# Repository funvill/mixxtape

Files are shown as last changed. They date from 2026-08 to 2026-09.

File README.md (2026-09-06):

# Mixxtape — a cassette you can actually record on

A 2-layer PCB in the form factor of a compact cassette (99.5 × 63.5 mm)
that slides into a real Norelco cassette case. The bare board **is** the object —
no enclosure, no bezel.

An onboard MEMS microphone records three 4-minute tracks. Hold REC to record,
release to stop. Pair it to any Bluetooth earbuds or speaker and press PLAY.

Cassette-shaped Bluetooth *players* exist. Nobody ships a cassette-shaped
**recorder** — and recording is the part that made a mixtape a mixtape.

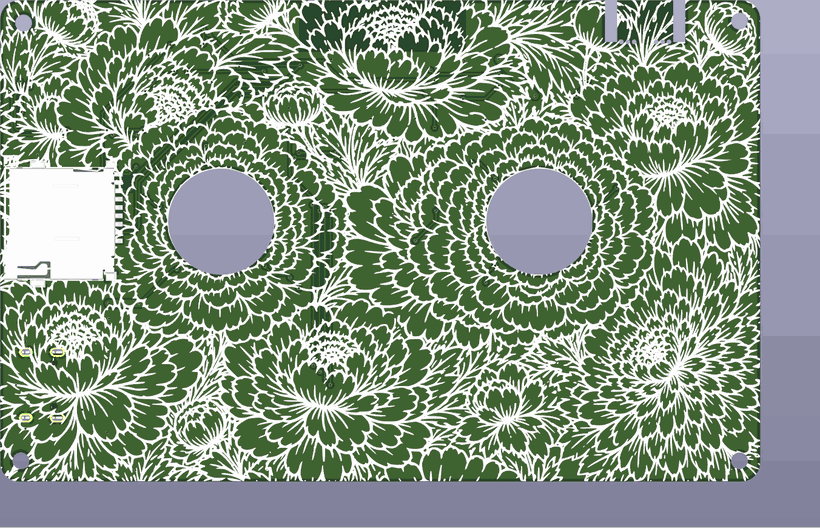
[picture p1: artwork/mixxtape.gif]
The Mixxtape board turning, front and back. The front carries the ESP32, two rings of RGB LEDs around the routed-out reel windows, four buttons and a USB-C port; the back is covered edge to edge in a peony line-art silkscreen.


<sub>3D render from KiCad. The mask reads green here because that is the
viewer's default — the board ships **matte white**, which is what makes the
sharpie label work.</sub>

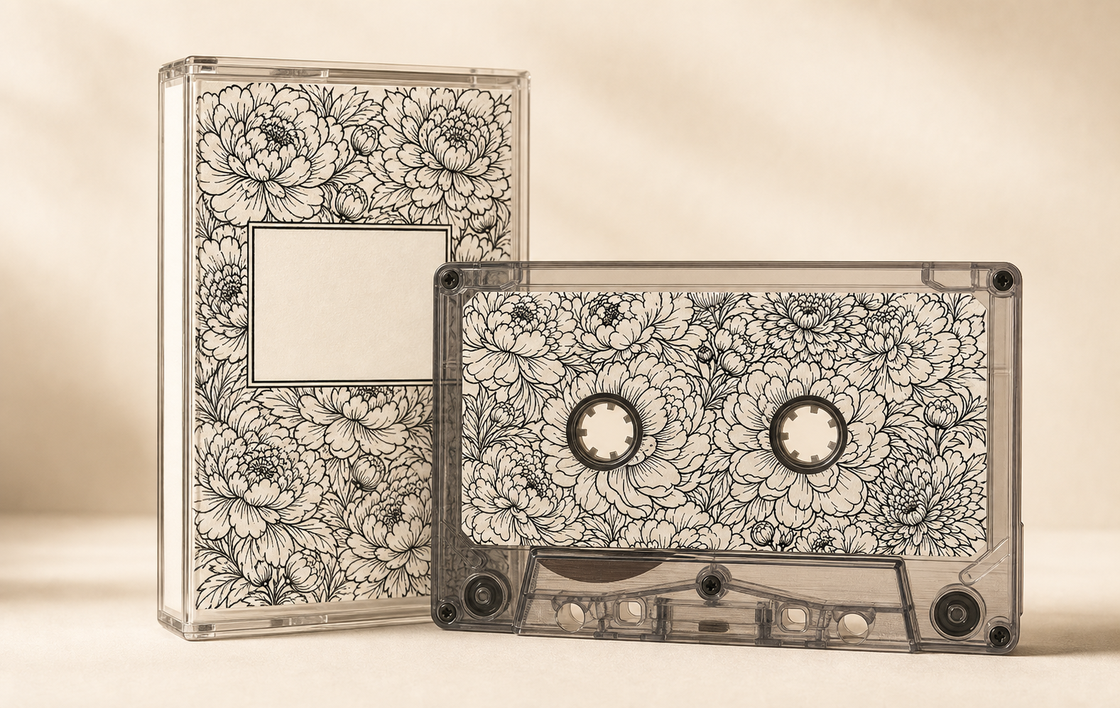
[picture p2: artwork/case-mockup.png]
A cassette and its paper insert, both carrying the same black peony line-art on an off-white ground, the insert showing a blank ruled label box.


<sub>Artwork mockup of the B-side design and the J-card insert. The board is
the object; this shows where the artwork is going.</sub>

## How you use it

- **Hold REC** — records. Release stops. Recording always overwrites the current
  track from zero — recording *is* erasing, same as tape.
- **PLAY** — plays all three tracks in order. It's a tape side, not three voice
  memos.
- **TRACK** — cycles track 1 → 2 → 3.
- **MODE (hold 2 s)** — pairing. Hold the board against your speaker; it picks
  the closest device by signal strength. No phone, no app, no list.
- Plug it in and it auto-reconnects to the last thing it paired with.

## Notable design features

- **Snap-off write-protect tab.** A mouse-bitten break-off PCB tab carries a
  trace to a GPIO. Snap it and the firmware refuses to record — permanently.
  Handing someone a tape becomes a ritual with a physical, irreversible step.
- **The reels show tape position.** Twelve RGB LEDs ring each routed-out reel
  window. During playback the left ring empties and the right ring fills, like
  tape transferring between reels. Red pulse tracks recording level.
- **Matte white solder mask** so you can sharpie the label on, with a ruled
  label block silkscreened where a cassette's paper label sits.
- **No battery.** USB-C only, and there is no charging circuit on the board
  at all. A cassette's promise is that you find it years later and it still
  works.
- **Jig-programmed.** No USB-UART on the board — USB-C is power only.
  Firmware loads through six pogo-pin pads via a programming jig.

## Hardware summary

Every fitted part is stocked at JLCPCB. The project rule is a minimum of 5,000
in stock, so a run never stalls on one line item — with a single documented
exception: **the microphone sits at ~3,500**, because no digital MEMS
microphone at JLCPCB clears the bar, and the one that does is analogue and
would wreck the audio path.

| Block | Part | JLCPCB | Qty | Notes |
|---|---|---|---|---|
| MCU | ESP32-WROOM-32E-N4 | [C701341](https://jlcpcb.com/partdetail/C701341) | 1 | The original Xtensa ESP32 — the only one with Classic Bluetooth, so the only one that can be an A2DP *source* |
| Microphone | MSM261DHT006 | [C51928215](https://jlcpcb.com/partdetail/C51928215) | 1 | **PDM** digital MEMS, mono, **top-ported** — sound enters from the component side, so there is no hole through the board |
| Storage | GD25Q128ESIG | [C2758105](https://jlcpcb.com/partdetail/C2758105) | 1 | 16 MB NOR flash, separate from the module's own flash. Three fixed slots, ~4 min each. Winbond W25Q128JVSIQ ([C97521](https://jlcpcb.com/partdetail/C97521)) is a drop-in second source |
| Indicators | XL-2020RGBC-2812B | [C5349954](https://jlcpcb.com/partdetail/C5349954) | 29 | WS2812-compatible RGB. Two 12-LED reel rings, three track lamps, REC, BT |
| LED data buffer | SN74AHCT1G125 | [C7484](https://jlcpcb.com/partdetail/C7484) | 1 | Lifts the ESP32's 3.3 V data line to the LEDs' 5 V rail |
| Regulator | AMS1117-3.3 | [C6186](https://jlcpcb.com/partdetail/C6186) | 1 | 5 V USB down to 3.3 V |
| USB-C | TYPE-C-31-M-12 | [C165948](https://jlcpcb.com/partdetail/C165948) | 1 | Power and CC sensing only — no data lines |
| Buttons | TS-1187A-B-A-B | [C318884](https://jlcpcb.com/partdetail/C318884) | 4 | REC, PLAY, TRACK, MODE |
| Write-protect tab | — | — | 1 | Not a part. A mouse-bitten PCB tongue carrying a net tie; snap it and recording is disabled for good |
| Programming pads | — | — | 1 | Six bare pogo targets. No USB-UART on the board |

Passives are all JLCPCB basic-library parts:
[10 µF 0805](https://jlcpcb.com/partdetail/C15850) ×2 (rail bulk),
[10 µF 0402](https://jlcpcb.com/partdetail/C15525),
[1 µF](https://jlcpcb.com/partdetail/C52923) (the ESP32's EN delay),
[100 nF](https://jlcpcb.com/partdetail/C1525) ×12,
[10 k](https://jlcpcb.com/partdetail/C25804) ×7,
[5.1 k](https://jlcpcb.com/partdetail/C25905) ×2 (the USB-C CC pull-downs) and
[100 Ω](https://jlcpcb.com/partdetail/C25076) (microphone supply isolation).

| | |
|---|---|
| Audio | 44.1 kHz mono, ADPCM-encoded at record time; playback decodes with table lookups and hands PCM to the Bluetooth stack |
| Power | USB-C only, power and CC sense. No battery, no charger |
| Board | 2-layer, 99.50 × 63.50 mm, matte white solder mask with black silkscreen |
| Cost | **$9.41/board** at a run of 20 — $173.14 in parts plus $15.00 of setup fees for five extended-library parts |

Full detail, with live stock and pricing, is in the
[generated BOM](docs/cassette-recorder-bom-v4.md) — it is derived from the
schematic, so it cannot drift out of step with it.

## Project status

**Design locked, schematic and firmware core underway.** `hardware/` holds a
KiCad 9 project with a first-pass schematic (ERC-clean) and JLCPCB part
libraries. `firmware/` has the ESP-IDF skeleton plus the host-tested core —
crash-safe slot manager, ADPCM codec, playback sequencer, reel display,
pairing policy, bond table and record limiter — all proven without hardware,
since there is no devkit. Target: a prototype run of 3–5 boards, then a full
run of 20. What is left needs a board in hand: the SPI flash, I²S capture,
the A2DP plumbing, LED output, and A2DP against real earbuds.

## Documentation

**Before ordering boards:**

- [Pre-production checklist](docs/PRE-PRODUCTION-CHECKLIST.md) — the
  case-fit test, open decisions, and what to re-quote
- [Case-fit test sheet](docs/case-fit-test-1to1.pdf) — print at 100%, cut
  out, put in a real cassette case

**For people using one:**

- [Cassette insert template](docs/jcard-template-1to1.pdf) — double-sided
  J-card for the case, 1:1, print at 100% ([side 1](docs/jcard-template-side1.svg), [side 2](docs/jcard-template-side2.svg))
- [Documentation index](docs/README.md) — everything below, organised
- [Quick-start pictograms](docs/quick-start-pictograms.html) — wordless
  instructions, one printable sheet
- [Manual](docs/MANUAL.md) — how to record, play, pair, and what the lights mean
- [FAQ](docs/FAQ.md) — including the honest limitations

**For people building or hacking one:**

- [Project write-up](docs/cassette-project-writeup.md) — the pitch, design
  rationale, and open questions
- [Agent handoff brief](docs/cassette-recorder-agent-brief.md) — the
  authoritative spec: locked decisions, GPIO map, behaviour spec, phase order
- [Bill of materials](docs/cassette-recorder-bom-v4.md) — generated from the
  schematic with live JLCPCB prices and stock, so it cannot drift
- [Line-out option](docs/line-out-option.md) — rejected; kept for the reasoning
  and the verified part numbers
- [Prior art](docs/prior-art.md) — research on cassette-form-factor projects
- [Firmware plan](docs/firmware-plan.md) — architecture, milestones, and
  hardware interface for the firmware agent

## Prior art

- **Mixtape Alpha** (Open Music Labs with Jie Qi / MIT Media Lab, 2012) — a
  cassette-shaped ATmega328p synth; the bare-PCB-as-object philosophy comes
  straight from it.
- **Mixxtape** (Mixxim) — the commercial cassette-shaped Bluetooth *player*.
  The thing this project is not.

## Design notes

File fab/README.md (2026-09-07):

# Fabrication export — JLCPCB

Generated from `hardware/mixxtape.kicad_pcb`. Rebuild with:

```
python hardware/scripts/export_fab.py
```

It refuses to run on a board that is not DRC clean, and it cross-checks the BOM
against the placement file — a designator in one and not the other stops the
export.

**Board state:** DRC 0 errors, 0 unconnected · ERC 0 violations · board and
schematic agree on every pad.

## What to upload

| File | Where it goes |
|---|---|
| `jlcpcb/mixxtape-gerbers.zip` | the main upload box |
| `jlcpcb/mixxtape-bom.csv` | BOM, once assembly is switched on |
| `jlcpcb/mixxtape-cpl.csv` | CPL / pick-and-place |

## Order settings

| | |
|---|---|
| Layers | 2 |
| Dimensions | **99.50 × 63.50 mm** |
| Thickness | 1.6 mm |
| **Solder mask** | **Matte white** — adds about two days, and the silkscreen is then black as a fixed pairing, not a choice |
| Silkscreen | Black (follows from white mask) |
| Surface finish | HASL is fine; ENIG if you want the break-off tab's link to stay bright |
| Assembly | Top side only |
| Parts | 66 placements across 15 BOM lines |

## Reference renders

`artwork/renders/` holds 3D renders of both sides, to compare against
JLCPCB's placement previewer before paying:

| | |
|---|---|
| `board-top-white.png`, `board-bottom-white.png` | Rendered with the stackup actually ordered — matte white mask, black silkscreen |
| `board-top.png`, `board-bottom.png` | KiCad's default green, which shows the copper more clearly |

The board file itself carries **no stackup block**, so KiCad renders it green.
The white pair was produced from a throwaway copy carrying the ordered
stackup; stackup colours do not affect the Gerbers either way. Regenerate
with:

```
kicad-cli pcb render --output out.png --side top --quality high hardware/mixxtape.kicad_pcb
```

## Things worth checking in their previewer

**Rotations.** Twenty parts sit at angles that are not multiples of 90° — the
two twelve-LED reel rings, plus four capacitors tucked between them. That is
deliberate, not an export fault. JLCPCB handles arbitrary angles, but their
part library sometimes defines a different zero-rotation than KiCad does,
particularly for LEDs and connectors. **Step through the placement previewer
before paying**, especially D1–D29 and J1.

**One part is deliberately not fitted.** J4, the microSD socket, is marked DNP
and is absent from both the BOM and the CPL — the microSD is a footprint-only
option. **If the previewer shows a microSD socket, stop.**

R9 *is* fitted. It is the pull-up that keeps the SD chip-select pin defined
even with the socket unpopulated.

## What is in the zip

Nine Gerber layers, two Excellon drill files (PTH and NPTH separately) and the
`.gbrjob` file, which helps their parser map the layers.

Drill map Gerbers are generated into `jlcpcb/gerbers/` but deliberately left
**out** of the zip — they are documentation, and a stray `.gbr` can be mistaken
for a copper layer by an auto-detector. Send them only if DFM asks.

## Export settings used

Per JLCPCB's own KiCad guide:

- Layers: F.Cu, B.Cu, F.Paste, B.Paste, F.SilkS, B.SilkS, F.Mask, B.Mask, Edge.Cuts
- Protel filename extensions (their recommendation)
- Subtract soldermask from silkscreen
- Zone fills checked before plotting
- X2 format **off**, for the widest CAM compatibility
- Drill: Excellon, millimetres, decimal, absolute origin, alternate oval mode,
  PTH and NPTH in separate files

The Gerbers and the CPL both use the absolute origin, so they align.

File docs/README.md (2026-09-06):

# Documentation

Start with the root [README](../README.md) for what the object is. This folder
holds the working documents behind it.

## Read first

| | |
|---|---|
| [Agent handoff brief](cassette-recorder-agent-brief.md) | The authoritative spec — locked decisions and the reasoning behind them, the GPIO map, the behaviour spec, and the phase order. Read in full before design, firmware or BOM work. |
| [Pre-production checklist](PRE-PRODUCTION-CHECKLIST.md) | Everything that must be true before boards are ordered. The case-fit test comes first, because the outline and hole positions have never touched real plastic. |

## For users

| | |
|---|---|
| [Manual](MANUAL.md) | How to record, play, pair, and what the lights mean. |
| [Quick-start pictograms](quick-start-pictograms.html) | Wordless, IKEA-style instructions for pairing, playing, recording and changing track. Drawn to the board's real proportions. Prints on one sheet. |
| [FAQ](FAQ.md) | Including the honest limitations. |

## Build and manufacture

| | |
|---|---|
| [Bill of materials](cassette-recorder-bom-v4.md) | **Generated** from the schematic with live JLCPCB stock and pricing. Rebuild with `python hardware/scripts/gen_bom.py`; never edit by hand. |
| [BOM as CSV](cassette-recorder-bom-v4.csv) | JLCPCB assembly format, fitted parts only. |
| [Case-fit test sheet](case-fit-test-1to1.pdf) | Print at 100 %, cut it out, put it in a case. |

## Artwork and packaging

| | |
|---|---|
| [B-side silkscreen template](../hardware/mixxtape-back-silkscreen-template.svg) | 1:1 outline of the back face with the keepouts marked, for anyone reworking the artwork. Rebuild with `gen_silk_template.py`. The art itself — the peony — is final and lives in the board file. |
| [Cassette insert template](jcard-template-1to1.pdf) | Double-sided J-card for the case, 1:1, two pages for duplex printing. Editable sides: [1](jcard-template-side1.svg), [2](jcard-template-side2.svg). Rebuild with `gen_jcard_template.py`. |

## Design record

| | |
|---|---|
| [Firmware plan](firmware-plan.md) | Architecture, milestones, and what is deliberately out of scope. |
| [Storage budget](storage-budget.md) | Why the tape stores ADPCM rather than SBC, and how the numbers work out. |
| [Line-out option](line-out-option.md) | **Rejected.** Kept as a decision record: what a 3.5 mm jack would have cost, with verified parts and pricing, should it ever come back. |
| [Prior art](prior-art.md) | Cassette-form-factor projects, and what nobody has shipped. |
| [Project write-up](cassette-project-writeup.md) | The pitch and the design reasoning, long form. |

## Generated files

Several documents here are produced by scripts in `hardware/scripts/` and will
be overwritten. Edit the generator, not the output:

| Output | Generator |
|---|---|
| `cassette-recorder-bom-v4.md` / `.csv` | `gen_bom.py` |
| `jcard-template-side{1,2}.svg`, `jcard-template-1to1.pdf` | `gen_jcard_template.py` |
| `../hardware/mixxtape-back-silkscreen-template.svg` | `gen_silk_template.py` |
| `../hardware/mixxtape-mechanical.kicad_pcb` | `gen_layout.py` |

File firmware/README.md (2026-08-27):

# Mixxtape firmware

ESP-IDF firmware for the cassette recorder. Read
[`docs/firmware-plan.md`](../docs/firmware-plan.md) first — it holds the
architecture, the hardware interface, and the milestone order. Storage
arithmetic lives in [`docs/storage-budget.md`](../docs/storage-budget.md).

**Framework is ESP-IDF and that is [LOCKED]** — Classic Bluetooth / A2DP
source exists only in Bluedroid. See the firmware plan for why Zephyr was
rejected.

## Layout

```
components/tape/   slot manager, ADPCM codec, tape-side player (portable C)
components/ui/     button grammar + device state machine     (portable C)
components/leds/   reel display rendering                    (portable C)
components/factory/ factory-test harness                     (portable C)
components/btaudio/ pairing, bonds, A2DP source                (mixed)
                   NB: must NOT be called `bt` — that is ESP-IDF's own
                   component name, and ours would shadow it
components/audio/  record-path look-ahead limiter            (portable C)
main/              ESP32 entry point and pin map
test/host/         host unit tests + NOR flash mock
```

Everything with real logic in it is portable C behind `flash_hal.h`, so it
compiles and is tested on a PC. There is no devkit for this project, so the
target-specific layer is kept as thin as possible and the logic that can
be proven without hardware is proven without hardware.

## Host tests

No ESP-IDF needed — any C compiler and CMake:

```bash
cmake -S firmware/test/host -B build && cmake --build build && ctest --test-dir build --output-on-failure
```

The centrepiece is the **power-yank sweep** in `test_tape_store.c`. The mock
flash models a NOR part honestly (erase sets bits, program only clears them,
torn writes land half the data) and can tear any chosen operation. The sweep
tears *every* flash operation of a recording in turn, "re-plugs" the device,
and re-checks the invariants:

- no slot is left mid-recording
- an untouched take is byte-identical
- the interrupted slot is either a whole-frame prefix of the new take, or
  the previous take complete and intact — never stale audio spliced on
- nothing is ever programmed over non-erased flash
- the device still records afterwards

This matters because there is no battery: a yanked USB cable is the normal
way this device powers off.

## Factory test (M5)

Twenty boards get assembled by hand, so each one is probed on the jig
before production firmware goes on:

```bash
idf.py -C firmware -DMIXXTAPE_FACTORY_TEST=ON build flash monitor
```

It probes every subsystem, prints an operator table, and emits one
greppable line:

```
FT|1|flash_id=PASS:0xEF4018|mic=PASS:1832|tab=PASS:1|bt=PASS:3|VERDICT=PASS
```

Log the jig's serial output to a file and that file is the build record for
the run — when board 14 turns out flaky three months later, you can look it
up instead of guessing.

Two properties matter and are enforced by tests:

- **Every step runs, even after one fails.** A board with a dead mic *and*
  a dead flash reports both faults on one pass, not one fault per reflash.
- **Results carry measured values, not just verdicts.** `mic=PASS:1832`
  lets you spot the one board reading 40 before it ships.

Interactive steps (LED walk, button presses) are skipped automatically on
an unattended run rather than blocking the line.

**Probes are not implemented yet.** The harness is host-tested; the probes
that need drivers M4 has still to write report `SKIP` with a `TODO M4`
detail, and the runner prints `SUITE INCOMPLETE` rather than a pass banner
while any remain. `main/factory_main.c` is the bring-up checklist.

## Target build

Needs ESP-IDF v5.x:

```bash
idf.py -C firmware build
```

Flashing is via the **J5 pogo pads and a jig** — there is no USB-UART on the
board (USB-C is power only). The jig carries the bridge and the EN/IO0
auto-program transistors.

## State

M0-M3 of the plan are done: project skeleton, storage budget resolved,
the host-tested core, and the reference study that settled the stored
format (ADPCM, not SBC — ESP-IDF's A2DP source takes PCM only). Playback
sequencing and the reel display are written and tested too.

Pairing *policy* and the bond table are written and tested too — what is
missing there is only the Bluedroid plumbing that feeds them.

Not yet written, all gated on prototype boards (M4): the SPI flash HAL,
PDM capture, the A2DP source and discovery callbacks, WS2812 output via
RMT, and CC sensing. Every one of those is a driver — the logic they feed
is already written and tested.

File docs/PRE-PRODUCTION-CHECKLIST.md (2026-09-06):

# Before you order boards

Nothing here is optional, and most of it is cheap. The expensive mistakes on
a project like this are all made in the ten minutes before clicking order.

Work top-down: the physical test gates the layout, the layout gates the
prototypes, and the prototypes gate the run of 20.

---

## 0. Blockers from the six-agent review (2026-08-30) ⬜

Six independent reviews ran against this board — schematic/electrical,
PCB/DFM, BOM/footprints, firmware-vs-hardware, bring-up/rework, and analog/RF.
Everything they found that could be fixed deterministically **has been fixed**
(see the CHANGELOG). What is left below needs either a physical object or your
judgement, and **each one can still cost the run.**

### 0a. USB-C plug fit — RESOLVED ✅

**Steven test-fitted a real USB-C plug against a 1:1 print on 2026-09-06 and
it seats.** J1 was not moved and the outline was not notched.

The measurement that prompted this stands and is worth keeping, because it
will be re-discovered: J1's mating face sits at x = 129.613 against a board
edge at 130.380, so **0.767 mm of bare FR4 protrudes in front of the
receptacle mouth**, with no relief notch. A review reasoned that a plug's
overmould shoulder seats flush against the receptacle at full insertion and
would foul that lip. The setback is real; the consequence was inferred from
generic plug geometry, and a real plug says otherwise.

**Still open, separately:** whether the closed cassette shell leaves room in
front of the port. That is a different question from whether the plug seats on
a bare board, and it is tracked under the case-fit items below.

### 0b. Mounting holes — RESOLVED ✅

**Steven measured them against the real shell on 2026-09-06 and they are
correct as drawn.** No change needed.

| | Position | Board-relative |
|---|---|---|
| 1 | 33.580, 32.750 | 2.750, 60.750 |
| 2 | 33.580, 90.750 | 2.750, 2.750 |
| 3 | 127.250, 33.000 | 96.420, 60.500 |
| 4 | 127.600, 90.750 | 96.770, 2.750 |

For the record, because it will look like a defect to the next person who
measures it: the four holes are **not** a rectangle. The bottom row spans
94.020 mm against the top row's 93.670 — 0.350 mm of skew — and the left
column's pitch is 58.000 against the right's 57.750, another 0.250 mm. A
review flagged this on the reasonable assumption that a moulded shell has
square bosses. It does not, and the holes follow the plastic. **Leave them
alone.**

### 0c. Step through D1–D29 in JLCPCB's previewer ⬜

**The LED part changed on 2026-08-30** — see the CHANGELOG. The old footprint
was drawn for a different manufacturer's pad-1 corner and would have
reverse-powered all 29. The new part (C5349954) has been verified against
LCSC's own library data and the netlist is correct, but:

- 20 parts sit at rotations that are not multiples of 90°, 16 of them LEDs.
- **JLCPCB's library sometimes defines a different zero-rotation than KiCad.**
- The previewer renders a *package*, not a netlist. **It cannot catch a pin-1
  error** — a wrong-corner part looks perfect in the render.

So the previewer is necessary and not sufficient. Look at it anyway, and give
D1–D29 and J1 their own minute.

### 0d. Microphone port direction — RESOLVED ✅

**MSM261DHT006 (C51928215) is TOP-PORTED.** Confirmed 2026-08-30 from LCSC's
own product page, which states: *"The MSM261DHT006 is an omnidirectional,
top-port MEMS microphone with PDM digital output."*
[C51928215](https://www.lcsc.com/product-detail/C51928215.html) ·
[datasheet](https://www.lcsc.com/datasheet/C51928215.pdf)

So the board is correct as drawn: **no through-hole under U2**, and the top
face is the acoustic path. This was flagged because `gen_layout.py` argues the
case using the name of the part it *replaced* (MSM261S4030H0R), and two
reviewers could not close it from the repo. It is closed now.

**What still applies:** keep U2's top face clear. Nothing tall beside it — the
only neighbours within 14 mm are C7 at 2.70 mm and R12 at 3.79 mm, both 0402,
so that is fine. But check during the case-fit test that no shell rib lands
over it, and remember a written label on the B-side artwork must not cover it.

### 0e. Decide on the protective components that were NOT added ⬜

These need schematic changes plus placement and routing. They were identified
but deliberately not applied unattended, because each adds a part and a net:

| Add | Where | Why |
|---|---|---|
| 10 k to 3V3 | `BTN_REC` (GPIO0) | Only the ESP32's internal ~45 k holds the boot strap. `BTN_REC` is **94.8 mm** — the longest signal net on the board — runs 16 mm alongside SPI_CLK, and lands on a bare pogo pad people touch. Leakage or noise at reset drops the board into download mode: dark, unresponsive, looks dead. |
| 10 k to GND | `LED_DATA` | GPIO27 is high-Z from reset, so U8's AHCT input floats near threshold, drawing crowbar current and possibly latching 29 LEDs to random colours at power-on. |
| 330 R series | U1.12 → U8.2 | J5 supplies **3V3, not VBUS**, so on jig power U8's VCC is 0 V. Driving GPIO27 high then forward-biases U8's input clamp into a dead rail, on **every flash cycle**. |
| 330 R series | U8.4 → D1 DIN | Damps the first hop of the chain. |
| 22 µF | U4 output, ≤2 mm | The AMS1117 datasheet asks for it and `cassette-recorder-agent-brief.md:103` says so; it never reached the schematic. Effective output C is realistically 5–6 µF. |
| 100 nF | U1 EN pin, ≤2 mm | The EN de-glitch RC (R3/C9) is **52 mm of routed trace** from the pin, alongside SPI_MOSI. |
| 1 k series | `TAB_SENSE` at U1 | The user snaps this tab **with their fingers** — a guaranteed human contact event on exposed copper wired straight to a GPIO with no clamp. |

Also consider **inverting the TAB1 divider** (3V3–R7–TAB_SENSE–TAB1–GND). As
built, GPIO21 is tied to 3V3 through a zero-ohm net tie; one firmware line
configuring it as output-low shorts the rail through the ESP32's driver.

### 0f. Fill in the factory-test probes ⬜

**With no prototype, the factory test is your only instrument** — and five of
its eight probes are stubs returning SKIP, so it can never report PASS. The
three unimplemented ones that matter most are exactly what you cannot check by
eye: **the microphone works, the radio transmits, and the flash accepts a
write.**

None of these need a board change:

- **`mic` — make it acoustic.** RMS of room noise cannot tell a working mic
  from a clock picking up crosstalk. Put a cheap piezo on the jig at a fixed
  distance, play a fixed tone, run a Goertzel at that frequency, and report the
  bin magnitude *and* its ratio to two neighbours.
- **`bt` — report RSSI, not a device count.** An inquiry count is
  environment-dependent: a quiet bench gives 0 and fails a good board. Pin one
  discoverable device at a fixed distance. An antenna or shield-solder defect
  shows as a 15 dB shift a pass/fail count would never see.
- **`flash_rw`** — pattern-write the spare region, read back, report CRC and
  throughput in KB/s. The JEDEC read barely exercises MISO.
- **`cc`** is nearly free: `cc_sense.c` already exists and works, it just is not
  wired into `probe_cc`.
- Add `esp_reset_reason()`, and **prefix the log line with the MAC** —
  `factory_test.h` calls the log "the build record for the run" and there is
  currently no way to tell board 14 from board 3.

**Also add a boot-time LED flash to `app_main`.** Today it never calls
`ws2812_init`, so a working board and a dead board are visually identical: 29
dark LEDs and UART on the jig pads. One line of "the CPU is running and the
RMT/level-shifter/LED-chain path works" is worth more during a 20-board
bring-up than any amount of UART.

Beware: **the `buttons` probe can pass spuriously.** REC is GPIO0, which the
jig's auto-reset also drives. The jig must tri-state IO0 before that step, and
the probe should verify IO0 reads high first.

### 0g. Build five, not twenty ⬜

Order 20 bare PCBs, **assemble 5**. Against the failure modes that remain
unrecoverable on this board — the USB-C fit, the mic port direction, the
mounting-hole skew — a pilot costs roughly one extra setup fee (~$20–30) and
one lead time, against ~$280 of scrapped assemblies.

Note **JLC will not assemble boards you already hold**, so a second run means
paying for boards again. Do not plan to hand-solder the microphone later: it is
a bottom-terminated LGA and hand-placing it is *harder* than letting JLC reflow
it.

### 0h. Accepted residuals — known, quantified, not fixed ⬜

These were judged not worth the risk of an unattended change. Decide whether
you agree.

- **Antenna clearance is 8.5 mm, not the 15 mm Espressif recommend.** Improved
  from 1.85 mm. Reaching 15 mm means rerouting 3V3/TAB_SENSE and EN/SPI_MOSI,
  or notching the outline so the antenna overhangs — which would invalidate
  the case fit you just verified against real plastic.
- **The write-protect tab is ~51 % solid FR4** across its 7.4 mm break line.
  It is now genuinely drilled (it was milled, at a size JLC could not cut), and
  the pitch was widened to 1.05 mm so the 0.45 mm hole-to-hole floor is met -
  but widening the pitch adds web as fast as it adds gap, so the solid fraction
  did not improve. The central unperforated span went from 2.30 mm to 1.60 mm.
  **It will need pliers or a score-and-snap, not a thumb.**
  The limit is geometric: 3V3 crosses at x = 45.150 and TAB_SENSE at 45.550,
  forcing a hole-free zone through the middle, and with a mandatory 0.45 mm
  between holes there is no arrangement that gets below ~45 %. Making it
  properly snappable means rerouting those two traces to cross at the edge of
  the tab rather than its centre. That is a real routing change and was not
  attempted unattended.
- **PDM_DATA runs 0.61 mm from SPI_CLK** for 4.8 mm on B.Cu, and the flash is
  written while the mic is recording. Expect flash-write-correlated clicks in
  recordings. Moving U2 next to U1 would fix this and the 67 mm PDM route at
  once — a placement change too large to make unattended.
- **U4 is at ~67 mm² of attached copper**, up from 29. Fine at a realistic
  150–250 mA load; marginal at a sustained 500 mA.
- ~~J1's CC pad mapping is unverified.~~ **RESOLVED 2026-08-30.** Read in
  physical order along the signal row, J1's pads come out as `B1A12, B4A9, B5,
  A8, B6, A7, A6, B7, A5, B8, A4B9, A1B12` — exactly the USB Type-C standard
  12-pin sequence, reversed by the connector's 90° rotation. **B5 lands on CC2
  and A5 on CC1**, both in their standard positions, each with its own 5.1 k
  pull-down (R2, R1). VBUS is on both A4B9 and B4A9, GND on both A1B12 and
  B1A12, and SBU1/SBU2/D+/D− are correctly left open. Cross-checked against
  LCSC's own library data for C165948 (TYPE-C-31-M-12).
- **The board draws more than a default USB port guarantees.** 29 LEDs plus an
  ESP32 TX burst exceeds 500 mA. R10/R11 correctly route CC to GPIO36/39 so
  firmware *can* read the source's advertised current — **it must**, and must
  cap brightness when the source is default-USB.

---

## 1. The case-fit test — mostly done ✅

**Steven ran the 1:1 printout against a real plastic case on 2026-08-30 and
it fits.** That retires the single largest mechanical unknown: the outline
had been borrowed from a board that fits *some* case, and the reel windows,
tab position and mounting holes are ours and had never touched plastic.

One item below is still open, and it is the one that decides whether the fit
generalises or was luck.

⬜ **Buy several cassette cases, from different brands.** The brief is
   emphatic: internal ribs and hub-clamp ridges vary, and thrifted cases are
   not dimensionally consistent. **One case proves the design is not wrong;
   it does not prove it is right.** Still worth doing before a 20-board run,
   because the failure it catches is one that scraps every board at once.

✅ **Print [`case-fit-test-1to1.pdf`](case-fit-test-1to1.pdf) at 100%.**
   Done 2026-08-30. Turn off "fit to page" / "scale to fit" if reprinting —
   printers shrink pages by a few percent without telling you.

✅ **Measure the calibration bar on the printout.** Must read exactly
   50.0 mm. Treated as satisfied by the successful fit — a scaled print
   would not have seated correctly — but measure it explicitly on any
   reprint, because a print scaled by a percent or two can still *feel*
   right in the hand.

✅ **Cut it out and put it in a case.** Done 2026-08-30 — it fits. The
   points that were checked, kept here as the record of what "it fits"
   covered:

   - Does the outline sit in the case without forcing?
   - Do the **reel windows** clear the hub-clamp ridges, or do the ridges
     land on board material where LEDs will be?
   - Does the **write-protect tab** (top-left) clear the internal ribs? The
     mouse-bite nibs must not sit where a rib presses.
   - Do the four **mounting holes** clear the case's internal ribs?
   - Does the **microphone** land somewhere a fingertip, a case rib or
     a written label will not cover? It is top-ported, so its top face
     is the acoustic path — there is no hole through the board.

⬜ **Write the measurements down.** Record them in this file rather than
   re-running `hardware/scripts/gen_layout.py`. **Do not re-run that
   script** — it rebuilds the original 100.33 mm outline and would undo the
   trim to 99.50 mm, along with every placement and route since. It carries
   a warning header saying so. If a measurement forces a mechanical change,
   edit the board directly and re-run `hardware/scripts/export_fab.py`.

---

## 2. Decisions still open ⬜

These are all flagged in the repo but need an actual answer before copper.

✅ **The microphone — decided.** Moved to MSM261DHT006 (C51928215), the
   best-stocked digital MEMS mic at JLC. Acoustically an equal swap; the
   cost was the interface (PDM instead of I²S, firmware updated) and a
   completely different pinout, so the schematic changed rather than just
   the part number. Two things came out of the datasheet review and are
   worth remembering:

   - It is **top-ported**, and so was the part the brief specified. The
     acoustic hole the brief called for through the board was a mistake
     and has been removed. Keep the mic's top face clear instead.
   - **3,485 in stock is below the 5,000 rule** — a documented exception,
     because no digital MEMS mic at JLC clears it and the only one that
     does is analog. Re-check stock before ordering; if it has fallen,
     alternates are MP34DT06JTR (C503097) and ICS-43434 (C5656610).

⬜ **Record path: one pass, not two.** The brief's two-pass pipeline needs a
   scratch region that does not fit. Firmware now encodes ADPCM straight to
   the slot. Consequence: a look-ahead limiter instead of whole-take peak
   normalisation. See `storage-budget.md` §4.

⬜ **Slot size 5 MiB → 5.125 MiB** (82 erase blocks), to keep the full
   four-minute take. A deliberate deviation from the locked "3 × 5 MB
   slots"; it preserves three fixed slots and the 4-minute promise.

⬜ **Licence of the borrowed outline.** Open Music Labs publish the Mixtape
   Alpha board files but state no licence for them. Confirm with them
   before distributing derived artwork. If they decline, redraw the outline
   from a measured cassette.

⬜ **The name.** The repo is named after Mixxim's commercial product. Fix
   before anything goes public.

⬜ **Tab count** — one for the whole tape (recommended, faithful) or three,
   one per track (more useful).

✅ **Silkscreen artwork — done.** The peony on the back face is **final**
   (Steven, 2026-09-06). It lives in the board file as the `LOGO` footprint at
   (80.582, 61.700), 2.16 MB across 193 shapes, deliberately full-bleed with
   ~0.42 mm hanging off each side for the fab to clip. The designer brief that
   used to sit in `docs/` has been retired — there is no outstanding artwork
   commission. The 1:1 template
   ([`mixxtape-back-silkscreen-template.svg`](../hardware/mixxtape-back-silkscreen-template.svg))
   stays for anyone reworking it later.

   Still deferred, and only if you want them: the five decorative guide holes
   along the bottom edge.

---

## 2b. Manufacturability, audited 2026-08-29 ⬜

Checked against JLCPCB's published 2-layer limits. Everything below either
passed or was fixed, but three items want a human eye before the order goes in.

- [ ] **Smallest plated annular ring is 0.200 mm on J1** — above JLCPCB's
  0.18 mm floor but under their 0.25 mm recommendation. Fine in all likelihood;
  worth a glance at the fab's DFM report rather than a surprise.
- [ ] **Closest hole-to-hole is 0.500 mm against a 0.45 mm limit**, inside the
  DNP microSD footprint. Only bites if J4 is ever fitted.
- [ ] **The B-side artwork has 32 shapes thinner than 0.15 mm** and 52 more
  between 0.15 and 0.25 mm. The first group will not print. Get the artwork
  thickened before committing to a run, or accept that the fine detail vanishes.
- [x] Footprint attributes corrected — the microphone was tagged `through_hole`
  with eight SMD pads, which can drop it from the pick-and-place file entirely.
- [x] Silkscreen line widths raised to JLCPCB's 0.15 mm minimum.
- [x] Eleven DRC rules had been set to `ignore`, hiding 145 findings including
  the one that would have caught the microphone. The eight that matter are back
  on as warnings.
- [x] **USB-C needs no board notch.** The TYPE-C-31-M-12 is a top-mount
  right-angle receptacle; its only board penetrations are four plated shell legs
  and two non-plated locating pegs, all already in the footprint. Its mouth sits
  0.76 mm inboard of the board edge, and the strip in front of it is clear of
  copper and parts. A notch is only needed for *mid-mount* receptacles, which
  this is not.
- [ ] **Confirm the case does not block the USB-C.** The port is on the right
  edge; a closed Norelco case has a wall there. Decide whether the board is
  meant to come out of the case to charge, or whether the case gets modified.

---

## 3. Re-quote, don't trust this repo ⬜

⬜ **Re-run `hardware/scripts/gen_bom.py`.** Prices and stock in the BOM are
   a snapshot. NOR flash has already moved once (W25Q128 went from $1.65 to
   $2.26 during this project).

⬜ **Check the supply-chain rule section.** Every fitted part should clear
   5,000 in stock, or be a documented exception.

⬜ **Confirm matte white solder mask** is available and what it costs.

⬜ **Count the extended parts.** At 20 boards the per-part setup fees
   dominate the component cost — adding one new extended part costs about
   as much as 50 LEDs.

---

## 4. Prototypes before the run ⬜

⬜ **Order 3–5 boards first, not 20.** At ~$14 each they are cheaper than a
   devkit, and they are the only way to answer the questions below.

⬜ **Build the programming jig.** There is no USB-UART on the board, so
   nothing can be flashed without it.

⬜ **Fill in the factory-test probes.** `firmware/main/factory_main.c` is
   the checklist; the harness is written and tested, the probes are stubs.
   The runner prints `SUITE INCOMPLETE` until they are real.

⬜ **Answer the three questions that could still change the hardware:**

   - **Handling noise.** A bare board with a mic on it, held in a hand.
     This is the project's biggest technical risk and it cannot be
     answered on paper.
   - **A2DP against real sinks.** Test a basket of them — AirPods, cheap
     TWS earbuds, a Bluetooth speaker. Confirm the class-of-device filter
     and tune the RSSI threshold, which is currently a guess.
   - **Reconnect latency on power-up.** If it is ~8 seconds, the ritual is
     dead and the interaction needs rethinking. Measure it early.

---

## 5. Only then ⬜

⬜ Fix whatever the prototypes taught you.
⬜ Re-quote again.
⬜ Order the 20.

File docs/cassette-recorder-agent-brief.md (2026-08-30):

# Cassette Mixtape Recorder — Agent Handoff Brief

**Owner:** Steven
**Status:** Design locked, pre-layout. No schematic drawn yet.
**Run size:** 20 boards, one-off. Not a production program.

---

## 0. Read this first

Several decisions in this document look wrong at first glance and are not.
Each one is marked **[LOCKED]** with its rationale. Do not "optimize" a locked
decision — if a change looks compelling, raise it with Steven rather than
acting. Section 2 lists the specific wrong turns an agent is most likely to
take.

Everything not marked LOCKED is open, and §7 splits it into what you may
decide yourself versus what needs Steven.

---

## 1. What this is

A 2-layer PCB in the exact form factor of a compact cassette (100.0 × 63.5 mm),
which slides into a real Norelco cassette case. The bare board *is* the object —
no enclosure, no bezel.

An onboard MEMS microphone records three tracks. Hold REC to record, release to
stop. Then pair to any Bluetooth earbuds or speaker and press PLAY.

Reel windows are routed out of the board with 12 RGB LEDs ringing each one. As a
track plays, the left ring empties and the right ring fills, mimicking tape
transferring between reels.

**Design ethos:** this descends from Open Music Labs' Mixtape Alpha (2012, with
Jie Qi / MIT Media Lab High-Low Tech) — bare PCB as a thing you touch, trace
routing as visual design, aesthetics as a first-class constraint. Not a
functional-first board that happens to be cassette-shaped.

**Prior art to read before starting:**
- Mixtape Alpha wiki: `wiki.openmusiclabs.com/wiki/MixtapeAlpha` — Eagle files,
  gerbers, BOM, and a candid "limitations of the design" section. Pull
  `mixtape2.brd` for the cassette outline rather than redrawing it.
- Mixxtape (Mixxim, `paulthings.com`) — the commercial cassette-shaped player.
  Player only, no recording. This is the thing we are *not* building.

---

## 2. Traps — the five mistakes most likely to be made here

1. **Do not substitute a newer ESP32.** The ESP32-S3, C3, C6, C5, and H2 are all
   BLE-only. Classic Bluetooth — and therefore A2DP — exists only on the
   original Xtensa LX6 ESP32. No A2DP means it cannot talk to ordinary earbuds,
   which is the entire product. This is the single most important constraint in
   the document.
2. **Do not switch to an nRF part.** Nordic has never shipped Classic Bluetooth.
   Same failure.
3. **Do not add a Seeed XIAO.** No XIAO in the lineup has Classic Bluetooth. The
   XIAO footprint may still be useful as a *secondary* prototyping footprint, but
   it cannot be the production MCU.
4. **Do not increase flash capacity "for headroom."** NOR flash prices rose
   100–120% in 1H2026, with high-density parts hit hardest. Headroom is the most
   expensive thing on this BOM. Track length was set to 4 minutes specifically to
   fit 16 MB.
5. **Do not add a battery to the default build.** See §3, Power.

---

## 3. Locked decisions

| Decision | Value | Rationale |
|---|---|---|
| **MCU** | ESP32-WROOM-32E, module not bare chip | **[LOCKED]** Classic BT for A2DP source. Module carries FCC/IC/CE modular approval; a bare chip would put full intentional-radiator testing on us. |
| **Flash size** | 16 MB external | **[LOCKED]** 3 × 4 min mono SBC ≈ 11.5 MB. |
| **Separate audio flash** | Yes, not module flash | **[LOCKED]** No battery means no graceful-shutdown window. A yank mid-write must not be able to corrupt the bootloader. Also avoids XIP cache stalls during record. |
| **Audio path** | Mono, encode to **block-framed IMA ADPCM** at record time | **[LOCKED]** Playback must be read-frames-and-transmit. No real-time decode, no resample, no DSP during streaming. |
| **Sample rate** | 44.1 kHz | **[LOCKED]** Matches A2DP negotiation, eliminates resampling entirely. |
| **Power** | USB-C only; no battery or charger on the board | **[LOCKED]** A LiPo in a drawer for years is dead and possibly hazardous. The object's premise is that it still works when rediscovered. Also avoids UN38.3 shipping paperwork. |
| **Controls** | 4 tactile buttons + 1 break-off write-protect tab | **[LOCKED]** Physical buttons, not cap touch — explicitly reversed after consideration. |
| **Indicators** | 29 × WS2812B-2020 RGB, single data line | **[LOCKED]** Replaced charlieplexing. Quiescent draw is irrelevant on USB. |
| **Recording UX** | Hold REC to record; always overwrites current slot from zero | **[LOCKED]** No delete function needed — recording *is* erasing, same as tape. |
| **Playback UX** | PLAY plays all three tracks in order | **[LOCKED]** It's a tape side, not three voice memos. |
| **Reconnect** | Auto-reconnect to last bond on power-up | **[LOCKED]** |
| **Storage layout** | 3 fixed 5 MB slots + header region | **[LOCKED]** No dynamic allocation, no compaction. |
| **Solder mask** | Matte white | **[LOCKED]** Glossy mask rejects permanent marker. Users sharpie the label. |
| **Sides** | One side, three tracks. No accelerometer. | **[LOCKED]** Rejected on BOM cost. |
| **Case** | Thrifted Norelco cassette cases | **[LOCKED]** |

---

## 4. Bill of materials

The authoritative BOM is **generated from the schematic** — see
[`cassette-recorder-bom-v4.md`](cassette-recorder-bom-v4.md), rebuilt with
`hardware/scripts/gen_bom.py`. It carries live JLCPCB stock and pricing and
cannot drift away from the design. Summary:

| Ref | Part | JLCPCB | Note |
|---|---|---|---|
| U1 | ESP32-WROOM-32E-N4 | [C701341](https://jlcpcb.com/partdetail/C701341) | **MSL 3, X-ray required.** N16 is C701343 |
| U2 | MSM261DHT006 | [C51928215](https://jlcpcb.com/partdetail/C51928215) | **PDM** MEMS mic, top-ported. Replaced MSM261S4030H0R (C2840615) at zero stock — completely different pinout, so a schematic change rather than a swap |
| U3 | GD25Q128ESIG | [C2758105](https://jlcpcb.com/partdetail/C2758105) | Second sources: C97521 (Winbond W25Q128JVSIQ), C113767 |
| U4 | AMS1117-3.3 | [C6186](https://jlcpcb.com/partdetail/C6186) | SOT-223. 22 µF on the output for stability, per its datasheet |
| U8 | SN74AHCT1G125 | [C7484](https://jlcpcb.com/partdetail/C7484) | 3.3 V → 5 V buffer for the LED data line |
| D1–D29 | XL-1615RGBC-2812B | [C5349954](https://jlcpcb.com/partdetail/C5349954) | 12 + 12 reel rings, 3 track, REC, BT |
| SW1–4 | TS-1187A-B-A-B | [C318884](https://jlcpcb.com/partdetail/C318884) | |
| J1 | USB-C 16P | [C165948](https://jlcpcb.com/partdetail/C165948) | + 2 × 5.1 kΩ CC pulldowns — mandatory |
| R12 | 100 Ω | [C25076](https://jlcpcb.com/partdetail/C25076) | Microphone supply isolation, per the MSM261DHT006 datasheet |
| C9 | 1 µF | [C29266](https://jlcpcb.com/partdetail/C29266) | The ESP32's EN delay. The datasheet asks for 1 µF, not 100 nF |

**$10.01/board at qty 20** — $182.13 in parts plus $18.00 of setup fees for six
extended-library parts.

**U6 (CH340N) and U7 (USBLC6-2SC6) are gone.** USB-C is power only; programming
is via the six-pad pogo jig, so there is no USB data path to protect.

---

## 5. GPIO map

Avoid GPIO 6–11 (module flash). GPIO 12 is MTDI strapping and must be low at
boot — leave unused. GPIO 34/35/36/39 are input-only.

| Signal | GPIO | Note |
|---|---|---|
| PDM CLK → mic | 25 | **Changed from I²S.** MSM261DHT006 is PDM |
| PDM DATA ← mic | 33 | |
| *(free)* | 26 | Was I²S BCLK; PDM needs only two wires |
| VSPI SCK → flash | 18 | |
| VSPI MISO ← flash | 19 | |
| VSPI MOSI → flash | 23 | |
| VSPI CS → flash | 5 | Strapping, defaults high — OK |
| WS2812 data | 27 | Drive via **RMT peripheral** |
| SW1 REC | 0 | Also BOOT for flashing |
| SW2 PLAY | 4 | |
| SW3 TRACK | 16 | |
| SW4 MODE | 17 | |
| Write-protect tab | 21 | Pull-down; tab intact = high |
| Line-in ADC *(DNP)* | 35 | ADC1 |
| UART0 TX / RX | 1, 3 | To the J5 pogo pads only — there is no USB-UART on the board |

Free for expansion: 13, 14, 22, 32.

---

## 6. Behaviour spec

### Buttons

| Button | Short | Long |
|---|---|---|
| REC | — | **Hold to record.** Release stops. Overwrites current slot. |
| PLAY | Play / pause | Sleep |
| TRACK | Cycle 1 → 2 → 3 | — |
| MODE | — | 2 s pair · 5 s dub · 10 s dev WiFi |

### Write-protect tab

Break-off PCB tab, top edge, mouse-bites, trace from 3V3 to GPIO21 with
pull-down. Intact → high → recording permitted. Snapped → low → **firmware
refuses all recording, permanently.** One tab locks the whole tape.

Route the trace so the snap line crosses it cleanly. Keep mouse-bite nibs clear
of case ribs.

### Pairing

The mixtape is the A2DP **source** — it initiates. Bluetooth sinks have no
source-selection UI and don't need one.

1. User puts speaker/earbuds into their own pairing mode.
2. User holds MODE 2 s. Reels sweep amber.
3. `esp_bt_gap_start_discovery()` → inquiry.
4. Filter results by **Class of Device**: major class Audio/Video, minor class
   headphones or loudspeaker. Drops phones, laptops, keyboards automatically.
5. Filter by **RSSI better than ~−50 dBm** (≈30 cm). This makes proximity the
   selection mechanism — the user holds the board against the speaker. Threshold
   needs empirical tuning.
6. `esp_a2d_source_connect()`, Just Works SSP, bond, stream.

Store 4–8 bonds. On power-up try last-used first, then others.

**Known race:** the sink is often simultaneously trying to reconnect to its own
last source (usually a phone). Handle with retry + backoff, and give honest LED
feedback — slow red pulse after ~15 s of failure means "the speaker is busy."

### LED states

| State | Reels |
|---|---|
| Searching | Amber sweep |
| Connected | Green lock |
| Playing | White — left ring empties, right fills |
| Recording | Red pulse, brightness = VU level |
| Background erase | Slow reverse, dim |
| Dubbing | Violet |

**Clamp global brightness to ~25%.** All 29 at full white is ~1.7 A.

### Record pipeline

Two-pass. Nothing clever happens in real time.

1. REC held → I²S DMA into ring buffer → write **ADPCM** to a scratch region.
2. REC released → device idle → analyze peak, normalize, encode to **SBC**,
   write to the final slot. Reels spin during this, so the wait reads as
   rewinding rather than hanging.
3. Slot invalidation triggers **background pre-erase** at idle. Sector erase is
   ~40 ms and must never happen on the record critical path; recording issues
   page programs only (~0.7 ms).

### Playback

Read SBC frames from flash → `esp_a2d_source_audio_data_send()`. That is the
entire playback path. If you find yourself decoding or resampling during
playback, something upstream went wrong.

---

## 7. Open questions

### Agent may decide

- LDO part selection (1 A, 5 V in, 3.3 V out, SOT-23-5 or SOT-89)
- WS2812B-2020 specific LCSC part and second source
- Exact reel ring diameter and LED pitch
- Decoupling strategy for the LED chain (~1 cap per 4 LEDs)
- Hacker header pinout refinement — currently 3V3, GND, I²S ×3, UART ×2, EN,
  spare GPIO ×2
- Firmware task structure and RTOS priorities
- ADPCM variant

### Needs Steven

- **Tab count:** one for the whole tape (recommended, faithful) vs three
  (per-track, more useful)
- **N4 vs N16** once the live price delta is known — if under ~$0.40, take N16
- **Silkscreen artwork.** On a bare-PCB product the art *is* the industrial
  design. Nobody should generate this without him.
- **Project name**
- **Line-in DNP:** confirm the 3.5 mm jack footprint choice
- **Tape-head playback in a real deck** — deliberately deferred. Mixxim holds a
  patent covering a cassette-shaped player that plays in real decks. Do not
  design toward this without a legal read.

### Must verify before ordering

- [ ] ESP32-WROOM-32E-N4 live price vs N16
- [ ] GD25Q128ESIG live price and stock, and on the second sources C97521 and C113767
- [ ] JLCPCB surcharge for matte **white** solder mask (adds ~2 days; the
  silkscreen is then black, which is fixed rather than a choice)
- [ ] Matte white solder mask availability and any surcharge
- [ ] Extended-part reel fees — ~7 extended parts × ~$3, dominates cost at qty 20
- [ ] Norelco case internal dimensions **against a physical case in hand** — rib
      and hub-ridge geometry varies by brand; buy several

### Unanswerable on paper — needs a prototype

- **Mic mechanical noise.** A bare PCB transmits fingernail contact and board
  flex straight into a MEMS mic. This is the top technical risk. Mitigate with
  relief slots around the mic and placement away from the natural grip, but it
  cannot be confirmed without building one.
- Whether SBC-at-record fits the real-time budget alongside I²S DMA.
- A2DP reconnect latency on power-up. If it's ~8 s, the ritual is dead and the
  UX needs rethinking.

---

## 8. Mechanical

- Outline 100.0 × 63.5 mm, 1.6 mm FR4 (real cassette: 100.5 × 64 × 10 mm)
- Two reel window slots + five guide holes along the bottom edge
- **WROOM antenna keepout:** no copper, no pour, nothing underneath. Overhang
  the module past the board edge or cut a 6 mm clear region. Easy to get wrong
  on a board this dense.
- **Mic acoustic port: ~~0.5–0.8 mm non-plated hole through the board~~ —
  WRONG, removed.** The specified MSM261S4030H0R is *top*-ported (its
  datasheet, p.2: "omnidirectional, Top-ported"), as is every in-stock
  alternative in that family. Sound enters from the component side, so a
  hole beneath the part does nothing but weaken the board. What matters
  instead is that nothing covers the mic's top face — no case rib, no
  label, no fingertip. Marked as a keep-clear zone in the layout.
- **Sharpie label block:** upper-left third, where a cassette's paper label sits.
  Faint light-grey ruled lines on silkscreen.
- **Mounting holes:** four Ø2.2 mm, one near each corner.
- **No lanyard hole and no castellated header.** Both were dropped; the
  programming pads replaced the header, and the lanyard hole was removed when
  the mounting holes went in.
- All components top-side. Single-sided SMT is a hard constraint.

---

## 9. Suggested phase order

1. **Verification pass** — clear the §7 checklist. Cheap, and it gates BOM
   decisions.
2. **Outline + mechanical** — pull the Mixtape Alpha board file, adapt the
   outline, place reel windows, the break-off tab and four mounting holes. Check against
   a physical case.
3. **Schematic** — power, MCU, mic, flash, LED chain, buttons, tab, USB, DNP
   sections clearly marked.
4. **Firmware bring-up on a devkit** — before layout is final. Prove A2DP source
   connects to real earbuds, prove PDM mic capture, prove ADPCM encode timing.
   These are the risky parts and they don't need the real board.
5. **Layout** — aesthetics are a design requirement here, not an afterthought.
6. **Prototype run of 3–5** before committing all 20.

Steps 1 and 4 are the highest-value early work. Layout before firmware bring-up
would be a mistake — the timing unknowns could change the hardware.

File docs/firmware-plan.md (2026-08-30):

# Firmware plan — agent handoff

**Audience:** the agent (or person) implementing firmware in `firmware/`.
**Read first:** `docs/cassette-recorder-agent-brief.md` (product spec, locked
decisions, traps). This document adds the firmware architecture, the current
hardware interface (which has evolved from the brief — this doc wins where
they differ), and a milestone order designed around one hard constraint:
**there is no devkit.** The first prototype PCBs are the bring-up vehicle,
so everything that can be de-risked on a host PC must be done before boards
arrive.

---

## 1. Constraints (do not violate)

- **Target:** ESP32-WROOM-32E (original Xtensa ESP32 — the only ESP32 with
  Classic Bluetooth / A2DP). Framework: **ESP-IDF** (A2DP source and SBC
  need IDF-level APIs; Arduino layer optional on top, not required).
  **[LOCKED — Steven, 2026-08-25]** Zephyr was evaluated and rejected: its
  BT stack is BLE-first with only partial BR/EDR host support, upstream has
  proposed deprecating BR/EDR entirely (zephyr#67145), and there is no
  supported Classic-BT/A2DP path on ESP32 under Zephyr — the proven A2DP
  source + SBC encoder live in Bluedroid, which is ESP-IDF-only. Do not
  revisit. Keep everything outside the BT/audio core behind the mockable
  HAL (M2) so the framework dependency stays contained.
- **Playback must stay cheap.** ESP-IDF's A2DP source takes **PCM** and
  encodes SBC inside Bluedroid; there is no API for pre-encoded frames
  (verified in M3 — see `docs/storage-budget.md`). The tape therefore
  stores block-framed IMA ADPCM and playback is read-block, decode with a
  few table lookups per sample, hand over PCM. No resampling, no filter
  banks, no transforms. If you find yourself doing real DSP at playback,
  something upstream is wrong.
- **Encode at record time**, one pass: PDM → PCM → ADPCM block → flash.
  44.1 kHz mono throughout — matches A2DP negotiation, eliminates
  resampling. The PDM-to-PCM decimation happens inside the ESP32's I²S
  peripheral, so it costs no CPU.
- **PDM downsample ratio must be 64, not 128.** PDM clock = sample rate x
  ratio, and 44100 x 128 = 5.64 MHz is above the microphone's 4.8 MHz
  maximum. 64 gives 2.8224 MHz, comfortably inside its window.
- **Recording must survive a USB yank at any moment.** No battery, no
  graceful-shutdown window. Only the slot being written may be corrupted.
  Sector erases (~40 ms) never happen on the record critical path —
  background pre-erase at idle; record issues page programs only (~0.7 ms).
- **Recording is erasing.** Hold REC always overwrites the current slot
  from zero. No delete function. Snapped write-protect tab (GPIO21 low) →
  refuse all recording, permanently.
- **PLAY plays all three tracks in order** — it's a tape side.
- Storage: 3 fixed slots + header region on the W25Q128 (16 MB). No
  filesystem, no dynamic allocation, no compaction.

## 2. Hardware interface (rev 0.1 schematic — supersedes brief §5)

| Signal | GPIO | Notes |
|---|---|---|
| PDM CLK → mic | 25 | MSM261DHT006, mono, L/R tied low, top-ported |
| PDM DATA ← mic | 33 | |
| VSPI SCK / MISO / MOSI | 18 / 19 / 23 | Shared: audio flash + (DNP) microSD |
| Audio flash CS | 5 | GD25Q128ESIG; 10k pullup |
| microSD CS *(DNP)* | 22 | 10k pullup (DNP); SPI mode |
| microSD card-detect *(DNP)* | 32 | Switch to GND; **enable internal pullup** |
| WS2812 data | 27 | Via SN74AHCT1G125 to 5 V; drive with **RMT peripheral** |
| SW1 REC | 0 | Boot strap — safe as active-low button |
| SW2 PLAY | 4 | Short = play/pause, long = sleep |
| SW3 TRACK | 16 | Cycle 1→2→3 |
| SW4 MODE | 17 | 2 s pair · 5 s dub · 10 s dev WiFi |
| Write-protect tab | 21 | External 10k pulldown; intact = high = record OK |
| CC1 sense | 36 (SENSOR_VP) | ADC1; see §6 power management |
| CC2 sense | 39 (SENSOR_VN) | ADC1 |
| UART0 TX / RX | 1 / 3 | To J5 jig pads only — **no USB-UART on board** |
| Line-in *(DNP)* | 35 | Unpopulated |
| Free | 12*, 13, 14, 15, 2, 26 | *IO12 is MTDI strap — must be low at boot, avoid. IO26 freed by the move from I²S to PDM |

**Changes vs the brief:** CH340N and USB data path deleted (USB-C is power
only); castellated header deleted; programming is via the 6-pad pogo jig
(J5: 3V3, GND, EN, IO0, TX, RX); SENSOR_VP/VN now sense USB-C CC; IO22/IO32
now assigned to the DNP microSD.

## 3. Programming & the jig

- The **jig carries the USB-UART bridge** (CH340C/CP2102 or similar) and the
  classic two-transistor EN/IO0 auto-program circuit, driving the J5 pads
  with pogo pins. The board itself has none of this.
- Flash with `esptool` / `idf.py flash` through the jig. Design a **factory
  test firmware** early (§7 milestone M5): exercises mic, flash, LEDs,
  buttons, tab-sense, BT inquiry — pass/fail over UART so 20 boards take
  minutes each.
- Post-assembly reflash for end users without a jig: none by default —
  consider the 8BitMixtape-style audio bootloader as a stretch goal only.

## 4. Architecture

### Tasks (FreeRTOS, suggested)

| Task | Core | Prio | Job |
|---|---|---|---|
| `audio_capture` | 1 | high | I²S-PDM DMA drain → ring buffer (record only) |
| `encoder` | 1 | med | Limiter + ADPCM block encode, straight to the slot |
| `a2dp_stream` | 0 | high | Decode blocks ahead of the A2DP PCM callback (playback) |
| `storage` | 1 | med | Slot manager, page programs, background pre-erase queue |
| `ui` | 0 | low | Buttons (debounce, short/long), state machine |
| `leds` | 0 | low | RMT frames ~30 fps from a state+progress struct |

BT stack (Bluedroid) lives on core 0; keep the audio/flash pipeline on
core 1. All inter-task communication via queues; no shared mutable state
without a mutex.

### Record pipeline (one pass, as built)

Nothing clever happens in real time.

1. REC held → I²S-PDM DMA → PCM ring → look-ahead limiter → **ADPCM block**
   encode → block ring → `tape_store_write()`. Page programs only; the
   erase frontier runs one 64 KiB block ahead of the write pointer, so a
   slot erase never sits on the critical path.
2. REC released → `tape_store_end_record()` truncates to whole blocks and
   commits a single header record. No pass 2, no wait, no scratch region.
3. A yank at any point leaves the take truncated to its last complete
   block and still playable. Recovery is `tape_store_mount()`'s job and is
   covered by the power-yank sweep in `test/host`.

Level control is a look-ahead limiter (~100 ms in RAM) rather than
whole-take peak normalisation: one pass cannot know the peak in advance,
and a limiter is the better tool for a mic capturing a room anyway.

The M1 storage conflict this replaced, and the M3 finding that settled the
stored format, are both written up in `docs/storage-budget.md`.

### Playback pipeline

`tape_store_read()` a block → `adpcm_block_decode()` → PCM into a small
ring → the A2DP source data callback drains it. Bluedroid encodes SBC.

The callback runs on the BT task and **must not block**: it is handed a
buffer and a length, returns how many bytes it filled, and a length of -1
means flush. So the decode must always be running ahead of it, never
inside it. Blocks are independently decodable, so seeking (track skip,
resume after pause) is a block-index calculation, not a re-scan.

### Pairing / reconnect (brief §6 has the full flow)

A2DP **source** role. MODE 2 s → `esp_bt_gap_start_discovery()` → filter by
Class-of-Device (Audio/Video major; headphone/speaker minor) → filter RSSI
> ~−50 dBm (proximity = selection) → connect, Just Works SSP, bond. Store
4–8 bonds; on power-up try last-used then others, with retry + backoff
(the sink is usually busy reconnecting to a phone — honest LED feedback
after ~15 s). **Measure plug-in→audio latency from day one**; if it's ~8 s
the UX needs rethinking and Steven needs to know.

### Dub (MODE 5 s) — design later, stub now

Board-to-board transfer. Candidate transports: BT (SPP/A2DP between two
boards) or audio itself (8BitMixtape's TinyAudioBoot precedent). Leave a
stub state; don't architect around it yet.

### Dev WiFi (MODE 10 s)

WiFi + Classic BT coexistence on the original ESP32 is poor during A2DP.
Dev mode must **stop streaming first**, then bring up WiFi (logs/OTA).
Never run both.

## 5. LED language (drive via RMT, global brightness cap)

| State | Reels |
|---|---|
| Searching | Amber sweep |
| Connected | Green lock |
| Playing | White: left ring empties, right fills (position = tape metaphor) |
| Recording | Red pulse, brightness = VU level |
| Background erase | Slow reverse spin, dim |
| Dubbing | Violet |
| Sink busy (>15 s) | Slow red pulse |

Plus D25–D27 track indicators, D28 REC, D29 BT status.

## 6. Power management (new — CC sense)

Default assumption: **500 mA budget** (USB 2.0 default). Firmware reads CC1
and CC2 via ADC1 (GPIO36/39, through 10 k). With our Rd = 5.1 k, the live CC
line sits at ≈0.41 V (default 500 mA), ≈0.92 V (1.5 A), ≈1.68 V (3 A). One
line carries the voltage, the other is near 0 — read both, use the higher.

- Budget 500 mA → LED global brightness cap ~15–20 %, never all-white.
- Budget ≥1.5 A → cap may rise to ~25–30 %.
- Re-read on boot only (cable doesn't change mid-session; keep it simple).
- ESP32 ADC is noisy — average 16+ samples; thresholds mid-band (~0.66 V,
  ~1.23 V).

## 7. Milestones — ordered for no-devkit de-risking

**Phase A: host-only (before any hardware exists)**

- **M0 — Skeleton ✅ done.** ESP-IDF project in `firmware/`, pin map in
  `main/include/board.h`, `sdkconfig.defaults` configured for Classic-BT /
  A2DP source with BLE off, CI in `.github/workflows/firmware.yml` (host
  tests + IDF build).
- **M1 — Paper math ✅ done.** `docs/storage-budget.md`. Resolved the §4
  conflict: the two-pass ADPCM scratch cannot coexist with three 5 MiB
  slots, so the record path is now **one pass**. M3 then settled the stored
  format as ADPCM (see below). **Needs Steven's sign-off** — one pass means
  a look-ahead limiter instead of whole-take peak normalisation, and slots
  grew to 5.125 MiB to keep the four-minute take.
- **M2 — Host-testable core ✅ done.** `components/tape` (slot manager,
  append-only header log with CRC + generation, ADPCM block codec,
  tape-side player), `components/ui` (button grammar and device state
  machine) and `components/leds` (reel rendering), all behind
  `flash_hal.h`. `test/host` has a NOR mock with power-loss tearing and a
  sweep that tears every flash operation of a recording in turn, plus a
  power-budget sweep proving no LED mode exceeds its share of the USB
  budget (119 mA worst case at the default cap). 7 suites, ~58,000
  assertions, green.
- **M3 — Reference study ✅ done.** The decisive finding: ESP-IDF's A2DP
  source callback is fed **PCM**, and Bluedroid encodes SBC internally with
  no API for pre-encoded frames. Stored format changed to block-framed IMA
  ADPCM; see `docs/storage-budget.md`. Still to mine from the reference
  code: the callback's buffer-depth and flush (`len == -1`) semantics, which
  shape the playback prefetch task.

**Phase B: first prototype boards (order 2–3 early, before the run of 20 —
at ~$14/board they are the devkit)**

- **M4 — Bring-up:** power rails, UART over jig, flash JEDEC ID, mic I²S
  capture to UART dump, LED chain, buttons, tab, CC sense readings.
- **M5 — Factory test firmware — harness ✅ done, probes gated on M4.**
  `components/factory` sequences the suite, aggregates results and emits
  both an operator table and a one-line machine record; host-tested with
  mock probes (every step runs after a failure, skips do not fail a board,
  interactive steps skip on unattended runs, reports never overflow their
  buffer). `main/factory_main.c` holds the board-side probes: tab sense,
  buttons and the SPI JEDEC ID read are written; mic, LED walk, CC sense,
  flash read/write and BT inquiry are stubs that report SKIP until the M4
  drivers exist, and the runner prints SUITE INCOMPLETE while any remain.
  Build with `idf.py -DMIXXTAPE_FACTORY_TEST=ON`.
- **M6 — The risk spikes**, in order: (1) *retired by M3* — we no longer
  encode SBC ourselves, and ADPCM encode is a handful of ops per sample;
  what remains is confirming PDM capture keeps up with flash writes;
  (2) A2DP source vs a basket of real sinks
  (AirPods, cheap TWS, a BT speaker) — connect rate, CoD filtering, RSSI
  threshold tuning; (3) reconnect latency, measured. Each answers a
  question the brief says can kill the design.
- **M7 — Integration:** full record→normalize→encode→play loop, LED
  language, sleep, bonds. Then the run of 20.

**Anything M6 breaks goes back to Steven before the 20-board order.**

## 8. Out of scope for now

- Dub transport implementation (stub only)
- Audio bootloader (stretch)
- microSD "studio edition" (hardware is DNP; leave a mount point in the
  storage HAL so it can slot in later)
- Line-in, battery operation (DNP)

## 9. References

- ESP-IDF A2DP source example: `examples/bluetooth/bluedroid/classic_bt/a2dp_source`
- pschatzmann ESP32-A2DP: <https://github.com/pschatzmann/ESP32-A2DP>
- 8BitMixtape TinyAudioBoot (audio bootloader precedent):
  <https://github.com/8BitMixtape/8Bit-Mixtape-NEO>
- W25Q128JV datasheet (page program 0.7 ms typ, sector erase 45 ms typ)
- USB Type-C spec §4.5.2 (Rp/Rd CC voltages)

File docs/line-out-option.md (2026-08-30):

# Line-out option — a 3.5 mm jack

> **Status: REJECTED, 2026-08-29.** Not being built. Kept as a decision record
> so the ground does not get gone over again — the parts, costs and pin budget
> below were all verified and remain accurate.
>
> Rejected on scope, not on feasibility. Everything below still stands, and
> **IO26, IO13 and IO14 are free again** — capacitive touch pads briefly took
> two of them and were removed. If this is ever revisited, the pin budget is
> intact.

The board's only output today is Bluetooth. This is the assessment of adding a
3.5 mm jack so it can also drive a powered amp, a pair of desk speakers, or
headphones on a wire.

The intended use is **the board out of its case** — you slide it out of the
Norelco shell, plug in, and it plays. That matters more than it sounds; see
[What it costs the design](#what-it-costs-the-design).

---

## The short version

| | |
|---|---|
| **Feasible?** | Yes, comfortably. Pins, board space and firmware structure are all already there. |
| **Cost** | About **$1/board**, on a board that currently costs $10.01 |
| **Effort** | ~1 hour schematic · half a day to a day of layout · ~1 day firmware |
| **Hard part** | Layout. The board is fully routed with zero DRC errors; adding a part means re-routing a region and re-checking the back artwork. |
| **Decision needed** | Whether headphones are a first-class use, which decides between shape A and shape B below. |

---

## Two shapes

Line-out and headphones look like the same jack, but they are different
electrical jobs. A line output wants ~2 V RMS into a high-impedance input. A
headphone output wants tens of milliwatts into 16–32 Ω. One part does not do
both well.

### Shape A — line-out only

```
tape_player_read() → I²S1 → PCM5102A → 3.5 mm jack
```

**Perfect for a powered amp or powered speakers.** The PCM5102A is a line
driver: 2.1 V RMS, designed for kΩ loads.

**Headphones will work, but quietly**, and will distort as you push them. Its
output stage is not specified to drive 32 Ω. That may be an acceptable
trade — it is the simplest possible version, one IC and one connector.

### Shape B — line-out and real headphone drive

```
tape_player_read() → I²S1 → PCM5102A → PAM8908 → 3.5 mm jack
```

Adds a 35 mW stereo Class-AB headphone amplifier. Drives 16–32 Ω properly, and
at low volume its output is a perfectly good line-out as well — which is how
every phone has ever solved this.

Costs one more IC, roughly four more passives, and a little more board area.

---

## Parts

All verified in JLCPCB stock. The project rule is ≥5,000.

| Role | Part | JLCPCB | Stock | Note |
|---|---|---|---|---|
| DAC | PCM5102APWR | [C107671](https://jlcpcb.com/partdetail/C107671) | 12,561 | $0.8872 @500. TSSOP-20. Config pins (FLT, DEMP, XSMT, FMT) all strap high or low — no I²C |
| Jack | PJ-320D | [C431535](https://jlcpcb.com/partdetail/C431535) | **79,274** | $0.037. **Surface mount**, 4 pads, 11.4 × 8.5 mm pad field |
| Headphone amp *(shape B only)* | PAM8908JER | [C33233](https://jlcpcb.com/partdetail/C33233) | 5,865 | 35 mW stereo Class-AB. Only just clears the stock rule — see the risk note below |

### Jack alternatives, all surface mount

| Part | JLCPCB | Stock | Pads |
|---|---|---|---|
| PJ-342 141 | [C7507452](https://jlcpcb.com/partdetail/C7507452) | 21,038 | 6 |
| PJ-327A 5JJ | [C668605](https://jlcpcb.com/partdetail/C668605) | 14,552 | 5 |
| PJ-320B | [C22355831](https://jlcpcb.com/partdetail/C22355831) | 5,413 | 3 |

These were confirmed surface-mount by reading their actual footprint data —
zero drilled holes, plain rectangular pads — not by trusting JLCPCB's category
field, which is unreliable for connectors. Watch for parts tagged 手工焊接
(*hand soldering*): JLCPCB will not machine-place those, which would break the
board's single-sided-SMT constraint.

### The part to avoid

**MAX98357A.** It is the default answer for ESP32 audio and it is wrong here.
Its output is **bridged** — both terminals swing, neither is ground. Wire that
to a 3.5 mm jack and the plug's sleeve shorts half the bridge. It is for a
soldered speaker, not a socket.

---

## Why this fits the board as it stands

Four things happen to already be true, which is most of why this is cheap.

**The GPIOs are free and unstrapped.** IO26, IO13 and IO14 — exactly the three
an I²S transmit needs. IO26 was freed when the microphone moved from I²S to
PDM, which needs two wires instead of three.

**The I²S peripheral is free.** The microphone runs on `I2S_NUM_0`, because PDM
receive is I2S0-only on this chip. **I2S1 has never been touched.** Recording
and playback are modal anyway, so they would not contend even if they shared.

**The firmware already has the right shape.** Playback is pull-based:

```c
uint32_t tape_player_read(tape_player_t *p, int16_t *dst, uint32_t samples);
```

and `bt_audio_set_source()` consumes exactly that signature. An I²S output task
calls *the same function*. This is not a coincidence to rely on twice — it is
worth keeping that way.

**Mono into both ears is already solved.** `bt_audio.c`'s data callback
duplicates every mono sample into interleaved stereo for A2DP. The I²S path
does the identical thing, so both channels of the DAC get signal.

---

## Where it goes

A 12.4 × 9.5 mm pocket (the PJ-320D plus a millimetre of clearance) was scanned
against every placed part, courtyard and board cutout:

| Edge | Free positions | Span |
|---|---|---|
| **Left** | **89** | y 6 → 50 |
| Bottom | 26 | x 4 → 16.5 |
| Top | 5 | x 22.5 → 24.5 |
| Right | **0** | blocked by J4, R12, C2 |

**The left edge is the natural home** and is wide open. The right edge is full —
that is the USB-C, regulator and microphone cluster.

The signal run from U1 to the left edge is roughly 40 mm, crossing the left reel
ring's LED chain. That is unremarkable for I²S at a few MHz, but it is real
routing work on a board that is currently finished.

---

## A freebie worth taking

The PJ-320D has a fourth pad. On jacks of this style it is normally a **switch
contact that opens when a plug is inserted** — which would let the firmware
auto-switch from Bluetooth to wire the moment you plug in, with no gesture.

**IO34 and IO35 are free and input-only.** No strapping risk, and input-only is
exactly what a detect line wants.

*Unverified:* that the fourth pad on this specific part is a detect switch
rather than a second sleeve or a TRRS ring. Confirm against the datasheet before
designing it in.

---

## Effort

| | |
|---|---|
| **Schematic** | ~1 hour. One TSSOP-20, one jack, ~8 passives. No I²C, no register configuration. |
| **Layout** | **Half a day to a day — this is the real cost.** The board is fully routed: 469 segments, 98 vias, zero DRC errors. Three new signals must cross ~40 mm, then zones re-pour, DRC re-runs, and the placed B-side artwork needs re-checking against any new vias. |
| **Firmware** | ~1 day. An I²S TX driver, output routing (Bluetooth / jack / both), a gesture to switch, volume. The look-ahead limiter already exists. Plus host tests for the routing logic. |
| **BOM and docs** | Free. The BOM is generated from the schematic. |

### Cost

| | Shape A | Shape B |
|---|---|---|
| DAC | $0.89 | $0.89 |
| Jack | $0.04 | $0.04 |
| Headphone amp | — | not priced |
| Extended-part setup fee | $3.00 one-off | $6.00 one-off |
| **Per board at qty 20** | **~$1.08** | **~$1.4 + amp** |

Against a current $10.01/board, shape A is roughly a **11 % increase**.

---

## What it costs the design

**The silhouette.** The premise is the exact cassette form factor — *the bare
board is the object*. A jack body is 11.4 × 8.5 mm and about 5 mm tall, and its
opening has to be reachable. Because the board comes out of the case to be
used, this only shows while it is in your hand rather than while it is being a
cassette on a shelf. That is a much smaller cost than it first appears, and it
is why the out-of-case decision matters.

**A second port with no case answer.** USB-C already has this open question — a
closed Norelco shell has walls all round. A jack makes it two. If the answer for
both is "take the board out", that is coherent; it should just be stated
somewhere a user will read it.

**It competes with the thing that already works.** "Pair it to any Bluetooth
earbuds or speaker" is in the first line of the README. The jack buys lower
latency, no pairing, and compatibility with anything that has a 3.5 mm input.
Those are real, but they are an addition to a solved problem, not a fix for a
broken one.

---

## Risks

**PAM8908 stock is thin.** 5,865 against a rule of 5,000. One supply wobble and
shape B needs a documented exception, the way the microphone already does. If
headphones matter, it is worth finding a second source before committing.

**Current budget.** The DAC is about 10 mA — irrelevant. A headphone amp at
volume is tens of milliamps — still small beside 29 LEDs. Neither threatens the
USB budget, which the firmware already caps by CC sensing.

---

## What was verified, and what was not

Verified against the design files and live JLCPCB data:

- IO26 / IO13 / IO14 free and unstrapped; IO34 / IO35 free and input-only
- Microphone on `I2S_NUM_0`, I2S1 unused
- `tape_player_read` / `bt_audio_set_source` signatures, and the mono-to-stereo
  duplication in the A2DP callback
- Board space, by scanning a real 12.4 × 9.5 mm envelope against every placed
  courtyard, pad and cutout
- Every part number, stock figure and price above
- That the listed jacks are surface mount, by reading their footprint pad data

Not verified:

- **That the PCM5102A is inadequate for 32 Ω headphones.** This follows from its
  role as a line driver and its datasheet load conditions, not from measurement.
  If someone has one on the bench, it is worth ten minutes.
- The PAM8908's price
- Whether the PJ-320D's fourth pad is a detect switch
- Footprint figures are pad-field extents, not body size or plug clearance

---

## The decision

**Is wired headphone listening a first-class use, or is this a line-out to
powered speakers that headphones happen to fit?**

Answer that and the shape follows. Everything else here is settled.

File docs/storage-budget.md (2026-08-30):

# Storage & buffer budget (firmware M1)

Resolves the conflict flagged in `docs/firmware-plan.md` §4: the brief's
two-pass record pipeline needs an ADPCM scratch region that does not fit
alongside three 5 MiB slots in a 16 MiB flash.

> ## ⚠ Revised after the M3 reference study: the tape stores ADPCM, not SBC
>
> **ESP-IDF's A2DP source accepts PCM only.** The API reference is explicit
> — `esp_a2d_source_data_cb_t` receives a "buffer to be filled with PCM data
> stream from higher layer", and "for now, the input should be PCM data
> stream". Bluedroid performs the SBC encoding itself, and exposes **no API
> for handing it pre-encoded SBC frames**.
>
> So the brief's "playback is read-frames-and-transmit" cannot be built as
> written: storing SBC would force us to *decode* SBC to PCM at playback
> purely so the stack could re-encode it — the exact real-time DSP the
> design forbids, plus a generation of extra loss.
>
> **The tape therefore stores block-framed IMA ADPCM.** Playback reads a
> block, decodes it with a few table lookups per sample, and hands PCM to
> Bluedroid. That is far cheaper than SBC decode and honours the intent of
> the locked decision better than SBC ever could. Recording is symmetric:
> I²S PCM → ADPCM → flash, and ADPCM encode is trivially cheap, which also
> retires the "does SBC encode fit the real-time budget" risk (M6 #1).
>
> Consequences: sections 1–4 below are the *original* SBC analysis, kept
> because the air-format numbers still govern what pairing negotiates.
> Sections 5 onward describe what is actually built. Slot size grew from
> 5 MiB to 5.125 MiB (82 erase blocks) to keep the full four-minute take —
> a deliberate, flagged deviation from the locked "3 x 5 MB slots", which
> preserves that decision's substance (three fixed slots, no dynamic
> allocation) and the 4-minute promise the flash size was chosen around.

All sizes are **binary** (MiB = 1,048,576 B). Flash is a GD25Q128E (or the pin- and command-compatible W25Q128JV):
16,777,216 B, 256 B program page, 4 KiB sector erase, 64 KiB block erase.

---

## 1. Audio rates

Source: 44,100 Hz, mono, 16-bit → **88,200 B/s** raw PCM.

**SBC frame length** (A2DP/SBC spec, MONO channel mode):

```
frame_bytes = 4 + (4 x subbands x channels)/8 + ceil(blocks x channels x bitpool / 8)
```

With the standard config — 8 subbands, 16 blocks, mono, Loudness allocation —
this reduces to `frame_bytes = 8 + 2 x bitpool`, at
`44100 / (16 x 8) = 344.531` frames/s.

4:00 is 82,687 whole frames (`floor(240 x 44100 / 128)` — the exact value is
82,687.5, and a partial frame is not playable), so stored sizes are that
count times the frame length:

| bitpool | frame B | B/s | kbps | 4:00 (B) | 4:00 (MiB) |
|---|---|---|---|---|---|
| 16 | 40 | 13,781 | 110 | 3,307,480 | 3.15 |
| 19 | 46 | 15,848 | 127 | 3,803,602 | 3.63 |
| 20 | 48 | 16,537 | 132 | 3,968,976 | 3.79 |
| **26** | **60** | **20,671** | **165** | **4,961,220** | **4.73** |
| 31 | 70 | 24,117 | 193 | 5,788,090 | 5.52 |

These are the numbers `sbc_frame.c` produces and `test_sbc_frame.c` asserts;
integer truncation is deliberate so firmware and this table cannot drift.

IMA-ADPCM scratch (4 bits/sample) = 22,050 B/s → **4:00 = 5,292,000 B
(5.05 MiB)**.

## 2. The conflict, quantified

Brief's locked layout: 3 x 5 MiB slots + header region.

```
header (64 KiB block)            65,536 B
3 x 5 MiB slots             15,728,640 B
                            -----------
subtotal                    15,794,176 B
flash total                 16,777,216 B
remaining for scratch          983,040 B   (960 KiB)
ADPCM scratch needed         5,292,000 B   (5.05 MiB)
DEFICIT                      4,308,960 B   (4.11 MiB)
```

960 KiB of scratch buys **44 seconds** of ADPCM, not 4 minutes.

## 3. Options considered

**A — Scratch overlays the target slot.** Recording already invalidates the
slot, so pass 1 could write ADPCM into slot N itself. Fails twice: ADPCM
(5,292,000 B) overflows a 5 MiB slot by 49,120 B, and pass 2 would have to
read ADPCM from and write SBC into the same region — a yank mid-encode
destroys both the scratch and the take.

**B — Dedicated scratch, smaller slots.** 5.25 MiB scratch + 64 KiB header
leaves 3.56 MiB per slot, which caps SBC at bitpool 18 (121 kbps). Violates
the locked "3 x 5 MiB slots" layout and costs audio quality.

**C — Keep 5 MiB slots, scratch in the 960 KiB remainder.** Caps recording
at 44 s. Not viable.

**D — One-pass: encode SBC directly during capture. ✅ RECOMMENDED**
No ADPCM scratch at all. The conflict disappears, and every locked decision
is satisfied *more* directly.

## 4. Recommendation: one-pass (Option D)

| | Two-pass (brief §6) | One-pass (D) |
|---|---|---|
| Scratch region | 5.05 MiB (doesn't fit) | none |
| Locked 3 x 5 MiB layout | violated | **honoured exactly** |
| Max bitpool at 4:00 | 18 (121 kbps) | **26 (165 kbps)** |
| Flash writes per take | 2x (ADPCM + SBC) | **1x** |
| Wait after REC release | ~10-20 s pass-2 | **none** |
| Yank during record | scratch lost, take lost | **take survives, truncated** |
| Level control | peak normalise (whole take) | look-ahead limiter (10 ms) |

The only real loss is whole-take peak normalisation. A look-ahead limiter in
RAM is standard practice for live recorders and is the right tool for a mic
capturing a room anyway — it also can't be fooled by one loud transient the
way peak normalisation can. Built and tested as `components/audio/limiter`:
10 ms of look-ahead (882 B of delay line), a sliding-maximum envelope that
makes the output ceiling a hard guarantee, and makeup gain to +18 dB so
ambient takes are audible.

The yank behaviour is a genuine *improvement* and very on-theme: pull the
cable mid-record and you keep what was recorded, exactly like real tape.

> **⚠ Needs Steven's sign-off.** The brief's §6 two-pass pipeline is
> descriptive prose, not a row in the LOCKED table — and the LOCKED row it
> serves ("encode to SBC at record time") is satisfied more literally by
> one-pass. Firmware defaults to D, with the layout and record policy behind
> compile-time constants so reverting is cheap. The ADPCM codec is
> implemented and tested regardless (small, and needed if two-pass returns).

## 5. Chosen layout (`tape_layout.h`) — as built

Stored format: **block-framed IMA ADPCM**, 4 bits/sample, 44.1 kHz mono.

One block is 512 B: a 4-byte header (predictor int16, step index, payload
checksum) plus 508 B of nibbles = 1016 samples = **23.04 ms**. Overhead is
0.8 %, giving **22,223 B/s** (`44100 * 512 / 1016`, truncated).

Blocks earn their keep three times over:

- **Seeking is free.** Each block carries its own codec state, so playback
  can start at any block — which track skip, pause/resume and the reel
  position display all need.
- **Erased flash is unmistakable.** A valid header needs a step index ≤ 88;
  erased flash reads 0xFF. Crash recovery scans for the first invalid block.
- **Torn writes are detectable.** The payload checksum catches a block whose
  header landed but whose data was cut short by a power loss — without it,
  recovery keeps 23 ms of noise. (This was a real bug, caught by the sweep.)

```
offset          size          region
0x000000        64 KiB        header (sectors 0/1 used as ping-pong log)
0x010000        5.125 MiB     slot 0
0x530000        5.125 MiB     slot 1
0xA50000        5.125 MiB     slot 2
0xF70000        576 KiB       spare / reserved
                              (future: bond table, wear relief)
```

Each slot is 82 erase blocks — the smallest whole-block size holding a full
four-minute take. Slot erase is therefore always whole-block, and a slot is
a whole number of ADPCM blocks with no runt at the end.

**Track length:** 5,373,952 / 22,223 = **4:01.8 max**; a nominal 4:00 take
uses 5,333,760 B (99.3 % of a slot).

## 6. Header log & crash safety

- Two 4 KiB sectors used as a **ping-pong append-only log** of 64-byte
  records (64 records/sector). Writing a record is one page program; when a
  sector fills, erase the other and continue there. ~64x fewer erases than a
  naive A/B rewrite scheme.
- Each record: magic, generation counter, per-slot state/length/duration,
  SBC config, CRC32. Mount picks the valid record with the highest
  generation; a yank mid-write leaves the previous record intact.
- **Partial-recording recovery:** a slot left in `RECORDING` state is
  repaired at mount by binary-searching for the first fully-erased page,
  walking back to the last complete SBC frame (syncword 0x9C, fixed frame
  length), and committing it as `VALID` with that length.

## 7. Erase strategy

A 5 MiB slot is 80 x 64 KiB block erases (~150 ms typ, 1 s max each) —
12 s typical, so it can never sit on the record critical path.

1. Preferred: background pre-erase at idle after a slot is invalidated;
   header tracks an `erased` flag per slot.
2. Fallback: just-in-time erase **one block ahead** of the write pointer.
   Writing a 64 KiB block at 20.7 KB/s takes 3.2 s, comfortably longer than
   even a worst-case 1 s erase, and the SBC ring absorbs the stall.

## 8. RAM buffers

Buffer the *encoded* stream, not PCM — SBC is 4.3x smaller, so the same
stall tolerance costs a quarter of the RAM.

| Stage | Size | Covers |
|---|---|---|
| I²S DMA (PCM) | 8.8 KB (100 ms) | DMA/scheduling jitter |
| ADPCM ring (post-encoder) | 44 KB (2 s) | 1 s worst-case block erase, 2x margin |
| Playback prefetch | 8 KB (~360 ms) | flash read latency vs A2DP callbacks |
| PCM out to Bluedroid | 8.8 KB (100 ms) | decoded ahead of the A2DP callback |

Total ≈ 70 KB of the ESP32's ~320 KB DRAM — comfortable alongside Bluedroid.

Buffer the *encoded* stream, not PCM, wherever there is a choice: ADPCM is
4x smaller, so the same stall tolerance costs a quarter of the RAM. The one
unavoidable PCM buffer is the last hop into Bluedroid, which only needs to
cover callback jitter, not flash stalls.

## 9. Open item for M6 (needs real sinks)

**Stored bitpool must be one the sink will accept.** We are the A2DP source
and propose the config, but the sink advertises min/max bitpool, and stored
frames cannot be re-encoded at playback (that would be exactly the
real-time DSP the design forbids).

Typical sinks accept up to bitpool 53, so 26 should be universally safe —
but this is untested. M6 must verify bitpool 26 / mono / 16 blocks /
8 subbands / Loudness against a basket of real sinks. If any common sink
rejects it, drop `TAPE_SBC_BITPOOL` (one constant) to 19 and re-encode;
3.63 MiB still fits a 5 MiB slot with room to spare.

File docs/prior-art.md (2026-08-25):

# Prior art — the cassette as a form factor

Research notes for the Mixxtape cassette recorder. Two direct ancestors, then
five other projects that use the compact cassette as the *shape* of the
device — not just as media. Each entry ends with what it teaches this project.

---

## Direct ancestors

### 1. Mixtape Alpha — Open Music Labs + Jie Qi (MIT Media Lab), 2012

<http://www.openmusiclabs.com/projects/mixtape_alpha/>

"The smallest synthesizer we could make without a prescription." An
ATmega328p synth on a cassette-shaped bare PCB, shipped in a real cassette
case with printed instructions. Stylophone-style continuous input plus 6
buttons; 4 voices, 4 effects, 5-note polyphony. You can record songs and
trade mixtapes with friends.

Fully open: schematics, code, board files, and even a Pure Data patch for
building custom wavetables live on the wiki
(`wiki.openmusiclabs.com/wiki/MixtapeAlpha`).

Design philosophy, in their own words: an attempt to break down the barriers
between people and electronics — to get them comfortable touching PCBs and
change expectations about how electronics should look. Resistive touch pads,
and all trace routing done with aesthetics as a first-class constraint.

**What it teaches us:** the entire design ethos (bare PCB as object, routing
as art), the cassette outline board file (`mixtape2.brd` — pull it rather
than redrawing), and the social loop: the device's output is tradeable.
Their answer to "what's on the tape" is clean — the device *makes* the
sound, so what's recorded exists nowhere else.

### 2. 8Bit Mix Tape — GaudiLabs / Dusjagr et al., ~2016

<https://www.hackster.io/news/the-8bit-mix-tape-d523f35405b7>

An Arduino-compatible ATtiny84/85 sound generator built to live *inside* a
real cassette shell, with control knobs poking out through the two reel
windows. Evolved publicly on its wiki from v0.1 (board strapped to the
outside of a dummy tape) to the v0.9 "Next Level Edition"; a "Pro Advanced
2000" variant was built into an NES cartridge.

**What it teaches us:** the reel windows are usable interface real estate —
they put knobs where we put LED rings. Also a lesson in iterating in public:
every board revision is on the wiki.

---

## Five more cassette-form-factor projects

### 3. Mixxtape — Mixxim, 2017 (commercial)

- Kickstarter: <https://www.kickstarter.com/projects/mixxtape/mixxtape-the-cassette-reinvented>
- Coverage: <https://newatlas.com/mixxtape-cassette-tape-music-player/49966/>,
  <https://www.hackster.io/news/mixxtape-turns-the-old-cassette-into-a-new-digital-music-player-2f362d95bf05>

The commercial cassette-shaped digital music player — 1215% funded in 30
days. MP3/FLAC playback, 8 GB onboard plus microSD to 256 GB, OLED display,
Bluetooth, rechargeable battery, headphone jack — and it physically plays
in a real tape deck through a tape-head interface (with the caveat that
decks with tape-movement sensors reject it).

**What it teaches us:** demand for the *object* is proven, and playback-only
is the ceiling of what's shipped — nobody has shipped recording. Also the
hazard: Mixxim holds a patent covering cassette-shaped players that play in
real decks. Tape-head playback stays deferred without a legal read
(brief §7).

### 4. Car cassette adapter — Larry Schotz, 1980s (commercial)

- <https://en.wikipedia.org/wiki/Cassette_tape_adapter>
- History: <https://www.vice.com/en/article/the-car-cassette-adapter-was-an-unsung-hero-at-the-dawn-of-the-digital-age/>

The original electronics-in-a-cassette-shell, invented by serial audio
inventor Larry Schotz to pipe a Discman into car tape decks. A "dummy"
tapeless cassette with a *write* head pressed against the deck's read head:
the incoming 3.5 mm signal is converted to a magnetic signal at the head
gap, no tape involved. One-way gears inside simulate reel movement so
auto-reverse and end-of-tape sensors don't eject it.

**What it teaches us:** this is the century-old prior art for tape-head
audio injection (relevant context for the Mixxim patent question), and its
fake-reel-motion gears are the mechanical checklist for what real decks
sense — exactly the sensors Mixxtape's deck-play mode would need to fool.

### 5. 8BitMixtape NEO — 8BitMixtape community, 2018

- <https://github.com/8BitMixtape/8Bit-Mixtape-NEO>
- <https://www.synthtopia.com/content/2018/05/15/8bit-mixtape-neo-synthesizer-an-open-lo-fi-electronic-music-platform/>

The 8Bit Mix Tape lineage matured into a platform: ATtiny85, 2 pots,
2 buttons, and 8 addressable NeoPixels on a cassette-styled PCB. Its party
trick is the TinyAudioBoot audio bootloader — new firmware is uploaded by
*playing a .wav file* into the board from any phone, computer, or Walkman.
The community shares "mixtapes" (firmware images as audio) that turn the
synth into a drum machine, pitch shifter, or algorave instrument.

**What it teaches us:** two things we're already circling — addressable RGB
LEDs on a cassette PCB read as personality, and firmware/content delivered
*as audio* is a proven, delightfully on-theme trick (worth remembering for
the dubbing feature: board-to-board transfer over sound is precedented).

### 6. ZX Spectrum in a cassette — JamHamster, 2021

- <https://www.tomshardware.com/news/raspberry-pi-zero-zx-spectrum-casette>
- <https://www.hackster.io/news/this-cassette-tape-emulates-the-zx-spectrum-61b6c23a33a3>

A Raspberry Pi Zero W physically trimmed (PCB sections cut off) to fit
entirely inside a genuine cassette shell, emulating the ZX Spectrum — the
computer whose software famously shipped *on* cassettes. Composite video out
via the Pi's test pads, PWM audio over GPIO, micro-USB power, and two USB-A
ports squeezed in for controllers.

**What it teaches us:** the shell's interior volume budget, proven the hard
way. Also the poetry angle: the cassette that *is* the computer instead of
holding its programs rhymes with our cassette that *is* the recording
device. (JamHamster later did the same with a working tape-head interface in
a TZXDuino build — worth a look if deck playback ever revives.)

### 7. Cassette Pi — IoT notification scroller, 2020

- <https://www.cnx-software.com/2020/08/16/using-an-old-cassette-tape-to-enclose-a-battery-powered-raspberry-pi-zero/>

A Raspberry Pi Zero W, battery, and LED matrix display inside a transparent
cassette shell. It receives IoT notifications via IFTTT; on message arrival
the cassette vibrates and scrolls the text across the LED display seen
through the shell.

**What it teaches us:** a transparent shell plus internal light is a strong
look — informative and glanceable without a screen. Confirms a battery and
radio fit inside the shell with room for a display, and that the cassette
silhouette makes even a notification gadget feel like an artifact.

---

## Round 2: record/playback devices in the cassette shell

A second research pass looking specifically for devices that *record* as well
as play, in cassette form factor.

### 8. Digisette Duo / Duo-Aria — Digisette LLC, 2000 ⭐

- Review: <https://www.soundandvision.com/content/quick-takes-digisette-duo-aria-mp3-player>
- Retrospective: <https://www.youtube.com/watch?v=19_OMV2P33I>
- FCC filing: <https://fcc.report/FCC-ID/PCMAR200/130275.pdf>

The closest thing to a true ancestor, seventeen years before Mixxtape: an
"e-cassette" MP3/WMA player in exact cassette form. Insert it whole into a
tape deck and an electromagnetic transducer along its edge lines up with the
deck's pickup head. 32–64 MB onboard plus MMC expansion, NiMH battery (~6 h
music / 9 h spoken word), USB dock — **and a digital voice recording
module.** A cassette-shaped device that records audio and plays it back
through a real tape deck shipped commercially in 2000, then vanished.

**What it teaches us:** (a) record + playback in the shell has been done
once, as a dictaphone feature — voice memos for yourself, not recordings you
trade, so the mixtape social loop is still unclaimed; (b) it's prior art
from 2000 for cassette-shaped players with deck playback, which reframes the
Mixxim patent question — worth handing to whoever does the legal read;
(c) even in 2000 a mic, battery, dock connector, and transducer all fit the
shell.

### 9. ION Audio Cassette Adapter Bluetooth — 2014 (commercial)

- <https://www.amazon.com/ION-Audio-Cassette-Adapter-Bluetooth/dp/B00I3YLHAC>
- <https://www.bhphotovideo.com/c/product/1049238-REG/ion_audio_bluetooth_cassette.html>

The Schotz adapter concept updated: a Bluetooth receiver in a cassette shell
feeding the deck's head, with a rechargeable battery (~6 h) — and a
**built-in microphone** for hands-free calls through the car speakers. Turns
itself on when inserted and off when ejected.

**What it teaches us:** a commercial product already put a working microphone
inside a cassette shell in an acoustically hostile spot (inside a running
tape transport) — encouraging for our handling-noise worry, though our
bare-PCB mic has no shell around it. The insert-to-power-on trick is also a
nice interaction precedent.

### 10. Milktape and Suck UK "Mix Tape" — cassette-shaped USB mixtapes

- <https://milktape.com/>
- <https://www.suck.uk.com/products/mixtapeusbdrive/>

Cassette-shaped USB flash drives sold explicitly as mixtape gifts. Suck UK's
comes in a cassette case with a paper J-card to handwrite the track list;
Milktape sells small-capacity (128 MB) customizable tapes — deliberately
sized to hold *one mixtape*, not a music library.

**What it teaches us:** the gift ritual sells even with zero audio hardware —
the shell, the case, and the handwritten label carry the whole product.
Milktape's small-on-purpose capacity validates our 3-track constraint as a
feature, not a limitation. Both are also prior art for the handwritten-label
ritual our matte-white sharpie block serves.

### 11. NFC mixtape cassettes — Etsy makers & DIY, 2020s

- <https://makerworld.com/en/models/1077383-retro-nfc-cassette-keychain-for-spotify-playlist>
- <https://www.notebookcheck.net/New-3D-printed-cassette-player-nails-the-retro-aesthetic-using-NFC-and-Spotify.1154678.0.html>

A living cottage industry of cassette-shaped NFC tokens: tap the cassette to
a phone and a Spotify playlist opens. One maker (bharms27) built a full
3D-printed "player" — a phone dock where inserting a printed cassette with an
NFC tag starts the album, complete with spinnable rollers.

**What it teaches us:** demand for *physical playlist tokens* is current and
ongoing, not just 80s nostalgia — but every one of these outsources the
audio to a streaming service. The token is a pointer, the music dies with
the subscription. Our tape holding the actual audio is the durable version
of the same desire.

---

## Patterns across all eleven

- **Recording is almost untouched.** Only the Digisette (2000) ever put
  record + playback in the shell, and only as a self-dictation feature.
  Nobody has shipped *recording as the point* — record, hand it over, snap
  the tab. The niche is still empty.
- **The reel windows are the signature feature** — knobs (8Bit Mix Tape),
  visible mechanism (adapters), spinnable rollers (NFC player), or our LED
  rings. Designs that ignore them read as generic rectangles.
- **The gift ritual is the product** for a whole segment (Milktape, Suck UK,
  NFC tokens) — shell + case + handwritten label sell without any audio
  hardware at all.
- **Open + tradeable beats closed + polished** in this niche's culture: the
  projects with living communities (Mixtape Alpha, 8BitMixtape) are the
  fully open ones.
- **Audio as a transport layer** keeps recurring (audio bootloader, tape-head
  injection) and is on-theme for dubbing.
- **Deck compatibility is a patent minefield** (Mixxim) — but the 1980s
  Schotz adapters and the 2000 Digisette both predate it; a legal read has
  real prior art to work with. Stays deferred regardless.
- **Mics survive inside cassette shells** (ION adapter, Digisette) — the
  open question unique to us is a mic on a *bare* PCB with no enclosure.

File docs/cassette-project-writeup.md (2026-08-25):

# Building a cassette you can actually record on

I've been designing a PCB shaped like a cassette tape. Not a case with
electronics inside — the bare board *is* the cassette. Same 100 × 63.5 mm
outline, reel windows routed out, and it drops into a real Norelco case (I'm
buying those at thrift stores).

It has a microphone. You hold down REC and it records. Three tracks. Then you
pair it to any Bluetooth earbuds or speaker and it plays them back.

That's the whole thing.

---

## Why this and not the ten cassette MP3 players that exist

There are cassette-shaped Bluetooth players you can buy — the Mixxtape is the
good one, ~$100, plays in real tape decks. But they're all **players**. You
sideload files onto them.

Nobody ships a cassette-shaped **recorder**. And recording is the part that made
a mixtape a mixtape. You made it, it was yours, you gave it to someone.

The other ancestor here is the Mixtape Alpha from Open Music Labs — a
cassette-shaped ATmega328p synth from 2012, done with Jie Qi at the MIT Media
Lab. Their whole point was getting people comfortable touching a bare PCB.
Fully open, files still up. I'm stealing that philosophy wholesale.

---

## How you'd use it

- **Hold REC** — records. Let go, it stops. Holding always overwrites from zero,
  so recording *is* erasing, same as tape.
- **PLAY** — plays all three tracks in order. It's a tape side, not three voice
  memos.
- **TRACK** — skip.
- **MODE, 2 seconds** — pairing. Hold the board against your speaker while its
  pairing light is blinking. It picks the closest device by signal strength, so
  proximity is the selection mechanism. No phone, no app, no list.

Plug it in and it auto-reconnects to the last thing it paired with.

---

## The bits I'm happiest with

**A write-protect tab that actually snaps off.** Break-off PCB tab on the top
edge, mouse-bitten, carrying a trace to a GPIO. Snap it and the firmware
refuses to record. Permanently. It's the "don't tape over my mixtape" thing,
and it makes handing someone a tape into a ritual with a physical, irreversible
last step.

**The reels do something useful.** Twelve RGB LEDs in each reel window. As a
track plays, the left ring empties and the right ring fills — tape transferring
between reels — so it's a position indicator nobody has to learn. Red pulse for
recording with brightness tracking level. Slow reverse spin while it's erasing a
slot in the background, which is what a real deck does before you record over
something.

**Matte white solder mask so you can sharpie the label on.** Glossy green mask
rejects permanent marker — it beads and thumbs off. Matte white takes it.

**No battery.** This is the decision I keep going back and forth on. A LiPo in a
drawer for eight years is dead and possibly puffed. A cassette's whole promise
is that you find it years later and it still works. So: USB-C only, with the
battery footprint on the board but unpopulated for anyone who wants to solder
one on. A power bank in your pocket with a cassette on a cable is basically a
Walkman anyway.

---

## Boring but load-bearing decisions

- **Original ESP32**, not an nRF or an ESP32-S3/C3. Only the old Xtensa ESP32
  has Classic Bluetooth, and without Classic Bluetooth there's no A2DP, which
  means it can't talk to normal earbuds. LE Audio would work but Apple still
  doesn't support it, so half of you couldn't use it.
- **Mono mic.** One microphone, so, mono. Encodes to SBC while you record so
  playback is just read-bytes-and-transmit — no real-time DSP.
- **Separate flash chip** for audio so a yanked USB cable mid-record can't
  brick the firmware.
- ~$13/board at a run of 20. NOR flash prices have roughly tripled this year
  which is genuinely annoying and drove several of the sizing decisions.

---

## Where I actually want your input

**1. Is a microphone recording of a room a thing anyone wants to trade?**
This is my real doubt. Mixtape Alpha had a clean answer — the device *makes*
the sound, so what's on it exists nowhere else. Mine records whatever's nearby,
which might just be a worse copy of something that already exists. Is the
answer "voice messages, not music"? Is it "ambient recordings are the point"?
Or is it "this needs a line-in and you're kidding yourself"?

**2. Battery or no battery?** Argue me out of the no-battery position.

**3. One write-protect tab for the whole tape, or three (one per track)?**
Three is more useful. One is more faithful.

**4. How bad is holding a bare PCB with a mic on it going to sound?**
Fingernails, board flex, handling noise straight into a MEMS mic. This is my
biggest technical worry and I don't think I can answer it without building one.
If anyone's fought this, I want to hear it.

**5. What do I call it?**

**6. Do you want one?** Making ~20. Some will be bad.

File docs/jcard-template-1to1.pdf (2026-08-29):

# MIXXTAPE — CASSETTE INSERT (J-CARD)

1:1. Print at 100% / actual size, fit-to-page OFF.

SIDE 1 — OUTSIDE | 101.6 × 104.775 mm

Page 1 and 2 sit in the same place. Duplex, flip on the LONG edge.

FRONT PANEL 65.09 mm

SPINE 12.7 mm NAME · REV seen on the shelf edge

TRACKS TRACKLIST FLAP 26.99 mm leave blank — the owner records these by hand 1 min:sec 2 min:sec 3 min:sec

# ARTWORK

the face seen through the case front

name · cover art

### 50.0 mm — MEASURE THIS FIRST

If this bar is not exactly 50.0 mm the printer scaled the page, and nothing else here can be trusted.

solid black — cut line — the finished card
dashed blue — fold — score, do not cut
dotted red — safe area — keep type inside
dashed grey — bleed — run art out to here (3 mm)

Norelco cases vary by brand. Cut one, fold it, try it in a real case before printing a batch.

# MIXXTAPE — CASSETTE INSERT (J-CARD)

1:1. Print at 100% / actual size, fit-to-page OFF.

SIDE 2 — INSIDE | 101.6 × 104.775 mm

Page 1 and 2 sit in the same place. Duplex, flip on the LONG edge.

FRONT PANEL 65.09 mm

SPINE 12.7 mm reverse of the spine — usually blank

NOTES TRACKLIST FLAP 26.99 mm recorded on · where · who it is for

# INSIDE FRONT

hidden until the card is lifted out

how it works · credits · URL · licence

### 50.0 mm — MEASURE THIS FIRST

If this bar is not exactly 50.0 mm the printer scaled the page, and nothing else here can be trusted.

solid black — cut line — the finished card
dashed blue — fold — score, do not cut
dotted red — safe area — keep type inside
dashed grey — bleed — run art out to here (3 mm)

Norelco cases vary by brand. Cut one, fold it, try it in a real case before printing a batch.

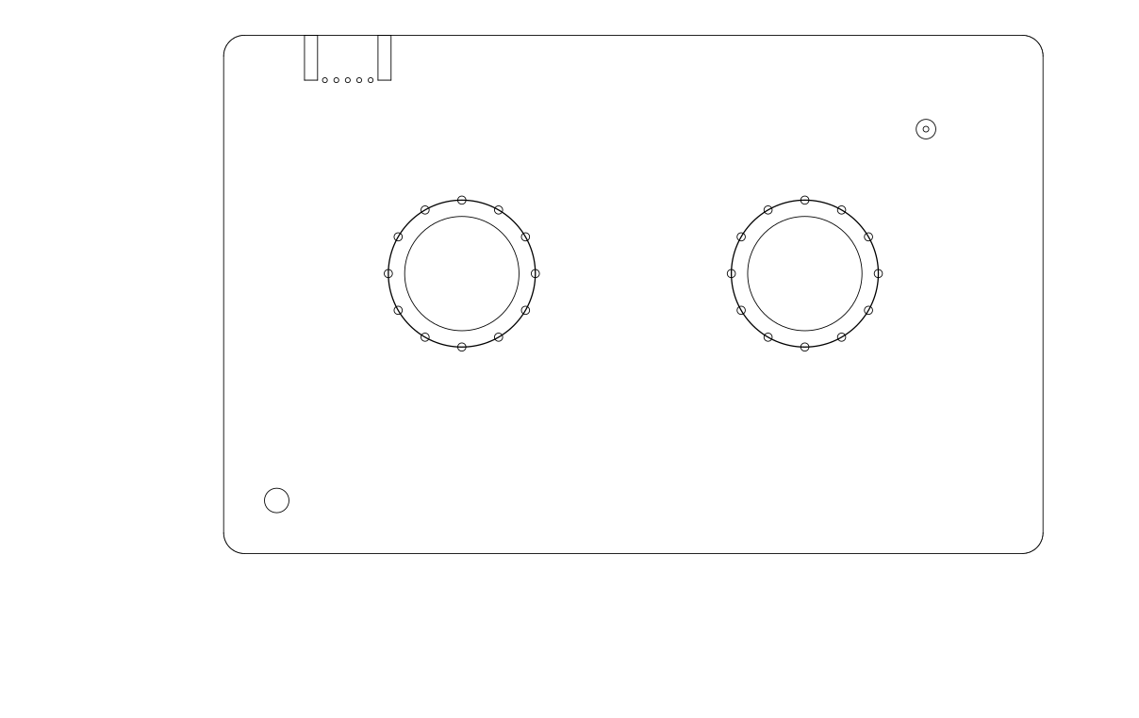
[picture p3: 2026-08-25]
docs/img-board-mechanical.png

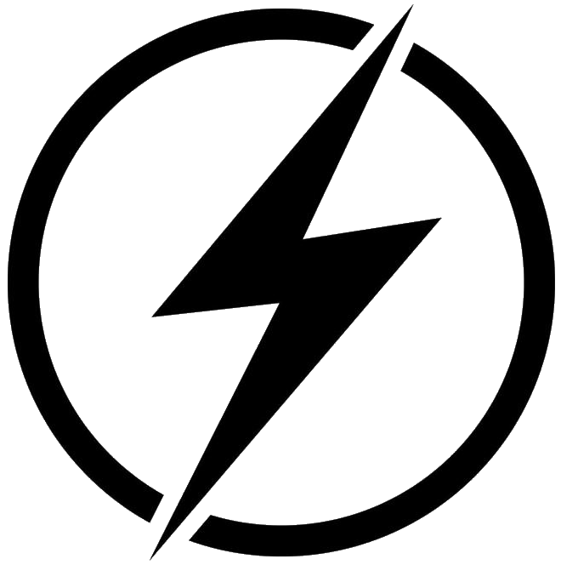
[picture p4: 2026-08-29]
hardware/images/power.png

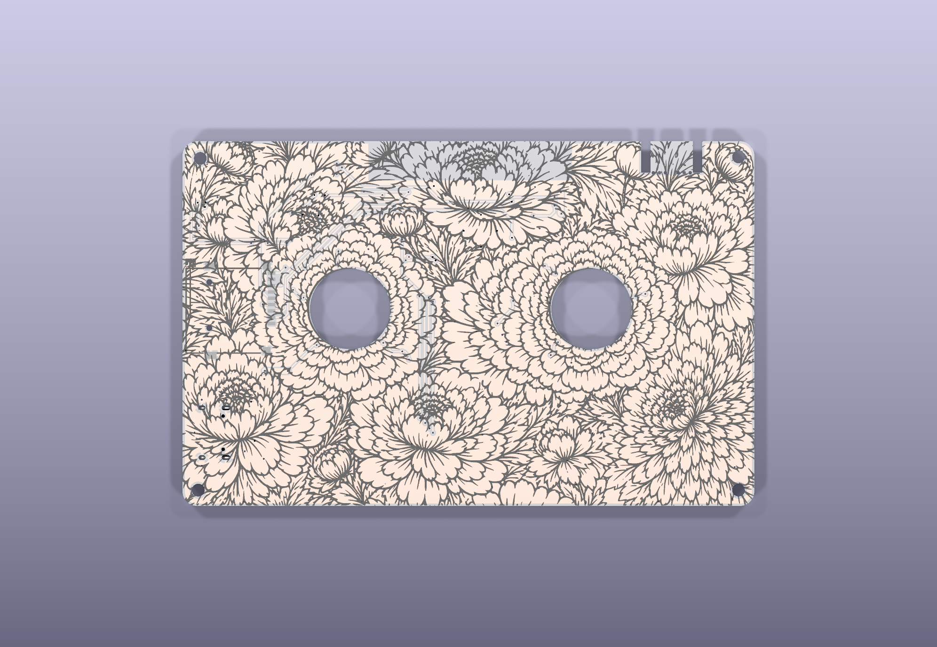
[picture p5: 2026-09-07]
artwork/renders/board-bottom-white.png

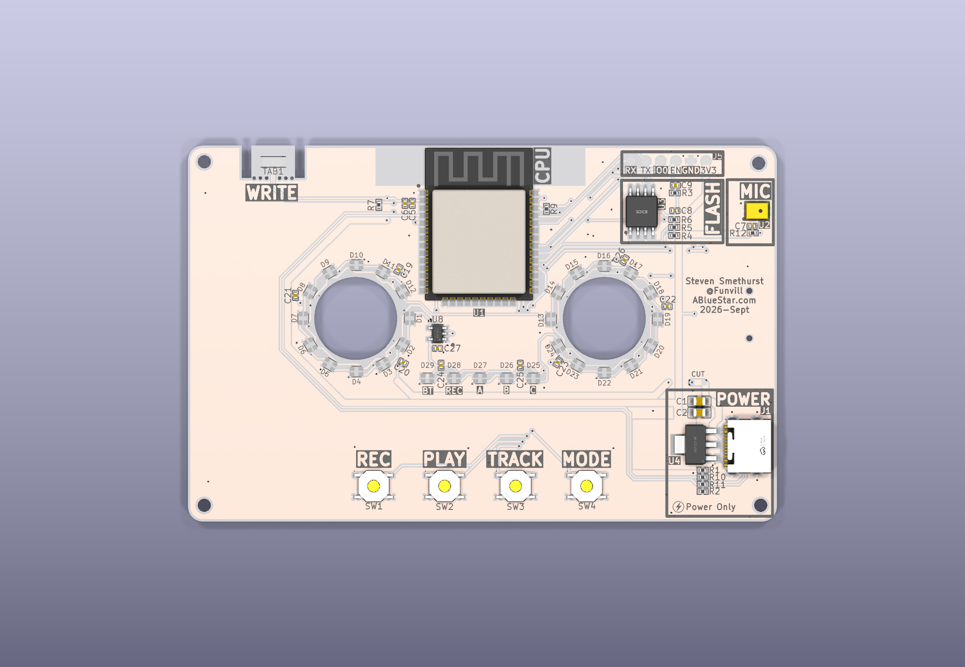
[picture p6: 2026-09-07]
artwork/renders/board-top-white.png

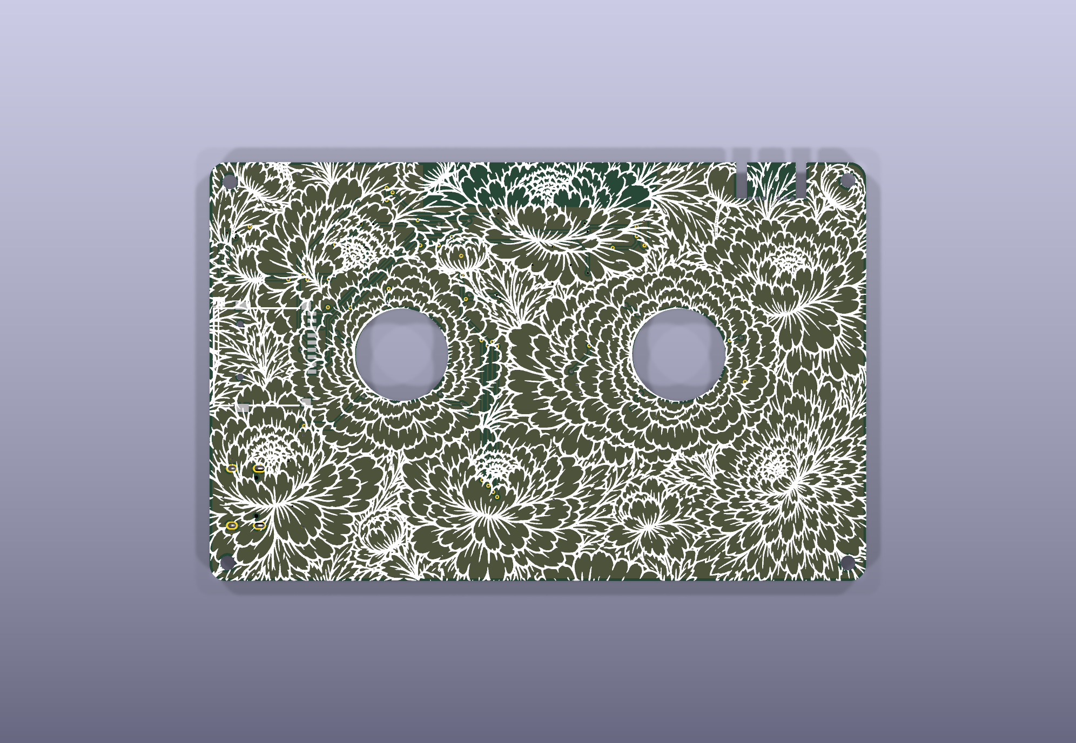
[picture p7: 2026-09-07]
artwork/renders/board-bottom.png

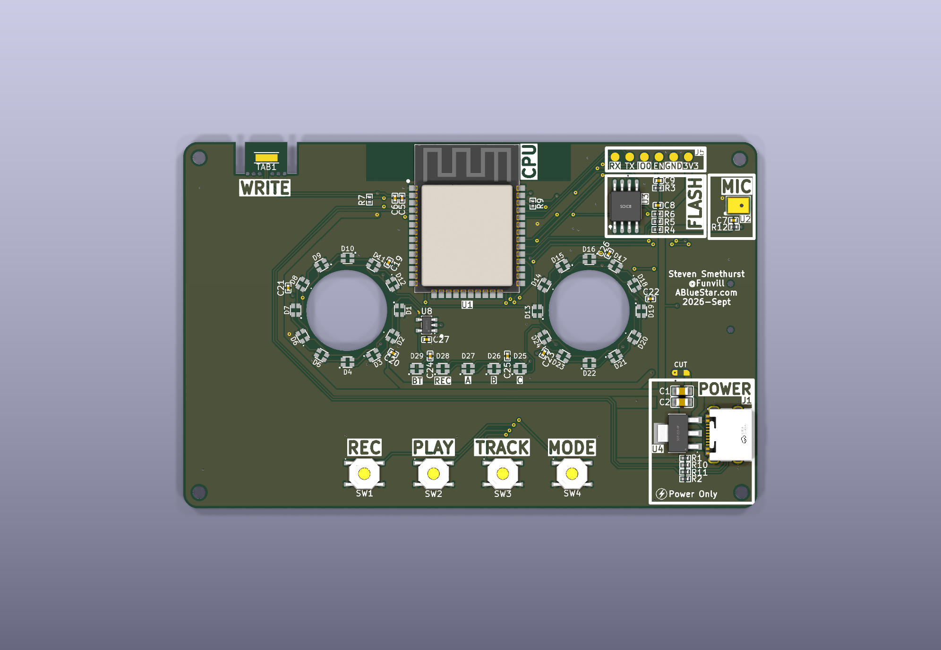
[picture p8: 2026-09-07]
artwork/renders/board-top.png

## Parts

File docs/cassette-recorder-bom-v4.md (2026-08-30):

# Bill of materials — v4

> Generated from `hardware/mixxtape.kicad_sch` by
> `hardware/scripts/gen_bom.py`, with prices and stock read live from
> JLCPCB at the time shown. **Do not hand-edit** — change the
> schematic and re-run, so the two can never disagree again (v3 did,
> in seven places).

Quantities are for a run of **20 boards**, and unit prices are
taken from the tier covering the whole order rather than a single
piece.

---

## Fitted parts

| Ref | Value | LCSC | Package | /bd | Order qty | Stock | Lib | Unit | Ext |
|---|---|---|---|---|---|---|---|---|---|
| C1, C2 | 10uF | C15850 | C0805 | 2 | 40 | 7,989,630 | basic | $0.0959 | $3.84 |
| C5 | 10uF | C15525 | C0402 | 1 | 20 | 10,659,536 | basic | $0.0255 | $0.51 |
| C6–C27 (12) | 100nF | C1525 | C0402 | 12 | 240 | 37,557,517 | basic | $0.0055 | $1.32 |
| C9 | 1uF | C52923 | C0402 | 1 | 20 | 11,781,626 | basic | $0.0120 | $0.24 |
| D1–D29 (29) | XL-1615RGBC-2812B | C5349954 | LED-SMD_4P-L1.6-W1.5_XL-1615RGBC-2812B | 29 | 580 | 366,246 | ext | $0.0401 | $23.26 |
| J1 | USB-C-16P | C165948 | USB-C_SMD-TYPE-C-31-M-12_1 | 1 | 20 | 390,037 | ext | $0.1855 | $3.71 |
| J5 | PROG-JIG | — | PROG_JIG_6PAD | 1 | 20 | — | ? | — | — |
| R1, R2 | 5.1k | C25905 | R0402 | 2 | 40 | 8,910,424 | basic | $0.0043 | $0.17 |
| R3, R4, R5, R6, R7, R9, R10, R11 | 10k | C25744 | R0402 | 8 | 160 | 33,084,764 | basic | $0.0031 | $0.50 |
| R12 | 100R | C25076 | R0402 | 1 | 20 | 4,589,188 | basic | $0.0078 | $0.16 |
| SW1, SW2, SW3, SW4 | PLAY / TRACK / MODE / REC | C318884 | SW-SMD_4P-L5.1-W5.1-P3.70-LS6.5-TL_H1.5 | 4 | 80 | 978,596 | basic | $0.0205 | $1.64 |
| TAB1 | WRITE-PROTECT | — | TAB_BREAKOFF_LINK | 1 | 20 | — | ? | — | — |
| U1 | ESP32-WROOM-32E-N4 | C701341 | WIFI-SMD_ESP32-WROOM-32E | 1 | 20 | 24,224 | ext | $3.2528 | $65.06 |
| U2 | MSM261DHT006 | C51928215 | LGA-8_L4.0-W3.0-R_WMM7040DT0 | 1 | 20 | 3,485 | ext | $0.4500 | $9.00 |
| U3 | GD25Q128ESIG | C2758105 | SOIC-8_L5.3-W5.3-P1.27-LS8.0-BL | 1 | 20 | 10,000 | ext | $1.3348 | $26.70 |
| U4 | AMS1117-3.3 | C6186 | SOT-223-3_L6.5-W3.4-P2.30-LS7.0-BR | 1 | 20 | 1,174,771 | basic | $0.2019 | $4.04 |
| U8 | SN74AHCT1G125 | C7484 | SOT-23-5_L3.0-W1.7-P0.95-LS2.8-BR | 1 | 20 | 27,012 | ext | $0.1264 | $2.53 |

⚠ marks a part whose current JLCPCB stock is below what this run
needs — check before ordering, or pick the second source.

## Not fitted (DNP)

Footprints on the board, deliberately unpopulated. They cost nothing
on the default build and let a variant be built without a respin.

| Ref | Value | LCSC | Package | Purpose |
|---|---|---|---|---|
| J4 | microSD (DNP) | C91145 | TF-SMD_TF-01A | microSD — the "studio edition" option |

## Cost

| | Per board | Run of 20 |
|---|---|---|
| Components | $7.13 | $142.66 |
| Extended-part setup fees (6 × $3.00) | $0.90 | $18.00 |
| **Parts subtotal** | **$8.03** | **$160.66** |

68 placements per board across 17 distinct fitted
parts, 6 of them extended.

PCB fabrication and assembly labour are quoted separately and are not
included above — at this quantity the setup fees above dominate the
component cost, so adding a distinct extended part is expensive and
adding more of one you already use is nearly free.

## Supply-chain rule: every fitted part needs 5,000+ in stock

- `C51928215` MSM261DHT006 — 3,485 in stock, needs 20 — accepted exception

  No digital MEMS microphone at JLCPCB meets the 5,000 rule - the whole category is thin, and the best-stocked digital part is only ~3.5k. The one microphone that does clear the bar (ZTS6216, C481302, 29k) is ANALOG: it needs a DC-blocking cap and a gain stage into the ESP32's ADC, which the brief already describes as a lo-fi path with ~9 effective bits. Meeting the rule there would wreck the product's only input. A digital part at ~3.5k is the lesser risk: the run needs 20 pieces, so that is 174x coverage, and three alternates are qualified.

## Needs attention before ordering

**U1 — ESP32-WROOM-32E-N4 (`C701341`)**

N4 (4 MB). N16 is C701343 — take it if the delta is small, though the firmware fits in 4 MB comfortably. Stock is the thinnest of any fitted part after the microphone, but this module is a locked decision: it is the only ESP32 with Classic Bluetooth, and without that there is no A2DP and no product.

**U2 — MSM261DHT006 (`C51928215`)**

Replaces MSM261S4030H0R (C2840615), which went to zero stock. Acoustically an equal swap, not a downgrade: identical -26 dBFS sensitivity, same 1.6-3.6 V range, same 4x3 mm LGA-8 outline, 1 dB less SNR (60 vs 61 dB) and 2 dB better acoustic overload (122 vs 120 dB SPL), which is the more useful end for a recorder that will meet a door slam. Cheaper too, $0.45 against $1.61, and lower current. Its one real cost is the interface: PDM rather than I2S, so firmware runs the ESP32's I2S peripheral in PDM RX mode - supported in hardware, and it frees GPIO26 because PDM needs two wires instead of three. Note the pinout is COMPLETELY different from the old part (pin 1 is VDD, not GND; pins 5-8 are all GND), so this was a schematic change, not a part-number swap. Like its predecessor it is TOP-ported: no hole through the board, keep its top face clear. Upgrade path if prototypes show the mic is the weak link: ICS-43434 (C5656610, ~3.7k, $3.33) keeps I2S and gains 5 dB of SNR, at 7x the price and a different 3.5x2.65 mm footprint.

**U3 — GD25Q128ESIG (`C2758105`)**

Swapped from the Winbond W25Q128JVSIQ (C97521), which had risen to $2.26 from BOM v3's $1.65 — the NOR price rise the brief warned about was real. The GigaDevice part is about half that. The land pattern matches to within 0.02 mm, and the command set (0x06, 0x05, 0x03, 0x02, 0x20, 0xD8, 0x9F) and 256 B / 4 KiB / 64 KiB geometry are identical, so nothing in the layout or the storage design changes. The ONE difference is the JEDEC manufacturer byte: 0xC84018 rather than 0xEF4018. The driver and the factory test both accept either id, so a board built with the Winbond part still works — but do not narrow that check back to one value. This part is EXTENDED, so it carries a one-off setup fee that the Winbond part did not; it still wins by a wide margin at 20 boards. Second sources: C97521 (Winbond) and C113767.

**U8 — SN74AHCT1G125 (`C7484`)**

TI part, 26k stock. UMW second-source C20617903 has 40k and costs a third as much if stock ever tightens. Both clear the rule easily.

## Second sources

| Part | Primary | Alternate | Note |
|---|---|---|---|
| Audio flash | C2758105 | C97521, C113767 | Winbond W25Q128JV; JEDEC id differs, firmware accepts both |
| ESP32 module | C701341 (N4) | C701343 (N16) | 16 MB module if the delta is small; firmware fits in 4 MB |
| Reel LEDs | C5349955 | C5349956 (SK6812 protocol) | Genuine WS2812B-2020 (C965555) is end-of-life at JLC |
| Level shifter | C7484 | C20617900 (UMW) | Cheaper, less known |

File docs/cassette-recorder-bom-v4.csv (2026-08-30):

Comment | Designator | Footprint | JLCPCB Part #
10uF | C1 C2 | C0805 | C15850
10uF | C5 | C0402 | C15525
100nF | C6 C7 C8 C19 C20 C21 C22 C23 C24 C25 C26 C27 | C0402 | C1525
1uF | C9 | C0402 | C52923
XL-1615RGBC-2812B | D1 D2 D3 D4 D5 D6 D7 D8 D9 D10 D11 D12 D13 D14 D15 D16 D17 D18 D19 D20 D21 D22 D23 D24 D25 D26 D27 D28 D29 | LED-SMD_4P-L1.6-W1.5_XL-1615RGBC-2812B | C5349954
USB-C-16P | J1 | USB-C_SMD-TYPE-C-31-M-12_1 | C165948
5.1k | R1 R2 | R0402 | C25905
10k | R3 R4 R5 R6 R7 R9 R10 R11 | R0402 | C25744
100R | R12 | R0402 | C25076
PLAY / TRACK / MODE / REC | SW1 SW2 SW3 SW4 | SW-SMD_4P-L5.1-W5.1-P3.70-LS6.5-TL_H1.5 | C318884
ESP32-WROOM-32E-N4 | U1 | WIFI-SMD_ESP32-WROOM-32E | C701341
MSM261DHT006 | U2 | LGA-8_L4.0-W3.0-R_WMM7040DT0 | C51928215
GD25Q128ESIG | U3 | SOIC-8_L5.3-W5.3-P1.27-LS8.0-BL | C2758105
AMS1117-3.3 | U4 | SOT-223-3_L6.5-W3.4-P2.30-LS7.0-BR | C6186
SN74AHCT1G125 | U8 | SOT-23-5_L3.0-W1.7-P0.95-LS2.8-BR | C7484

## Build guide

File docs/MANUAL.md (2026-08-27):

# The manual

> **Draft.** No hardware exists yet. This describes the design as built in
> firmware and schematic; anything marked *(unverified)* is waiting on the
> first prototype boards. The product name is still undecided — this
> document says "your tape" throughout, which is what it is anyway.

---

## What this is

A circuit board shaped exactly like a cassette. Not a case with
electronics inside — the bare board *is* the cassette. It has a
microphone. You hold down REC and it records. Then you pair it to any
Bluetooth earbuds or speaker and press PLAY.

Three tracks, about four minutes each. One side. That's the whole thing.

It drops into an ordinary cassette case, and the board is matte white so
you can write the label on it in permanent marker, the way you used to.

---

## What you need

- **A USB-C cable and something to power it from.** A phone charger, a
  laptop, a power bank. There is no battery — see
  [Power](#power-and-batteries).
- **Bluetooth earbuds or a speaker.** Anything that ordinary phones pair
  with will do.

---

## The controls

Four buttons along the bottom edge, and a small tab on the top edge.

| Button | Press | Hold |
|---|---|---|
| **REC** | — | Records for as long as you hold it |
| **PLAY** | Play / pause | Hold ~1 s to sleep |
| **TRACK** | Next track (1 → 2 → 3 → 1) | — |
| **MODE** | — | 2 s: pair · 5 s: dub · 10 s: developer mode |

MODE decides what to do when you *let go*, so holding past two seconds
does not accidentally start pairing on the way to something else. The
lights tell you which one you are about to get.

---

## Getting started

**1. Plug it in.** The reels wake up. If it has paired with something
before, it starts looking for it straight away.

**2. Pair it.** Put your speaker or earbuds into their own pairing mode,
then hold **MODE for two seconds**. The reels sweep amber while it looks
around. Now hold your tape against the speaker.

That last part is the whole interface. Your tape picks the closest audio
device it can find, so proximity is how you choose. There is no phone, no
app, and no list of devices to scroll through. It ignores phones,
laptops and anything else that is not a speaker, so the only thing you
can accidentally pair with is another speaker further away — and the fix
for that is to move closer and try again.

The reels turn green when it connects.

**3. Record.** Hold **REC**. The reels pulse red, brighter as the room
gets louder. Let go and it stops.

**4. Play.** Press **PLAY**. It plays all three tracks in order, like a
side of a tape. The left reel empties and the right reel fills as it goes.

---

## Recording

**Hold REC to record. Let go to stop.** There is no separate stop button
and no record-arm step.

**Recording erases.** Holding REC always records over the current track
from the beginning — it does not append, and there is nothing to delete.
This is exactly how tape worked, and it is deliberate: the only way to
keep something is not to record over it.

**Each track holds about four minutes.** If you fill one, recording stops
there. Press TRACK to move to the next one.

**Three tracks, about twelve minutes in total.** That is not a limitation
we are apologising for. A mixtape that holds everything is a hard drive.

**If the power is pulled while you are recording, you keep what you
recorded.** The take is simply shorter than it would have been. Nothing
else on the tape is affected. This matters more than it sounds, because
pulling the cable is how this thing switches off.

### Levels

You do not set a recording level and there is no gain knob. Your tape
watches the room and adjusts continuously: quiet rooms get lifted so
ambience is audible, and sudden loud sounds are caught before they
distort. The REC lamp brightness follows the input, so you can see it
working.

---

## Playing

**PLAY plays the whole side** — all three recorded tracks, in order,
without gaps between them. Empty tracks are skipped rather than played as
silence.

- **PLAY again** pauses. Press again to carry on.
- **TRACK** jumps to the next recorded track.
- **Hold PLAY** for about a second to put it to sleep. Any button wakes it.

While it plays, the **left reel empties and the right reel fills**. That
is your position on the side. Nobody should have to be told what it means,
which is the point.

---

## The lights

Twenty-four lights ring the two reel windows, and five more sit along the
bottom: three for the track, one for record, one for Bluetooth.

| What you see | What it means |
|---|---|
| Amber sweeping round the reels | Looking for a speaker |
| Reels turn green | Connected |
| Left reel emptying, right filling | Playing — this is your position |
| Red pulse, brightness following the room | Recording |
| Slow, dim reverse spin | Tidying up in the background. Ignore it |
| Violet | Copying to another tape |
| Slow red pulse after ~15 seconds | The speaker is busy — see below |
| Dark | Asleep, or nothing happening |

**The slow red pulse** almost always means the speaker or earbuds are
still connected to someone's phone. Bluetooth devices only talk to one
thing at a time. Disconnect it at the other end, or turn the phone's
Bluetooth off, and your tape will get in.

---

## The write-protect tab

There is a small tab on the top edge, joined by a few tiny bridges. It
does the same job as the plastic tab on a real cassette.

**Snap it off and your tape can never record again.** Not "until you
reset it" — never. It is a physical trace across a break line; once it is
gone, the firmware refuses to record, permanently.

This is the point of the object. You record something, you write the
label on the front, you snap the tab, and you hand it to someone. The last
step is irreversible and takes a physical act, which is what makes it a
gift rather than a file transfer.

Snap it with your fingernail or a pair of pliers. Everything else keeps
working — it plays exactly as before.

**Do not snap it if you are still deciding.** We cannot undo it, and
neither can you.

---

## Power and batteries

**There is no battery. It runs from USB-C only.**

That is a deliberate choice, and the reason is the whole premise of the
object. A lithium battery left in a drawer for eight years is dead, and
possibly swollen. A cassette you find in a box years later should still
work. So: no battery, nothing to degrade, nothing to leak.

In practice a small power bank in your pocket with a tape on a cable is
more or less a Walkman.

Any USB-C source will run it. If you plug it into a charger that can
supply more current, it notices and runs the lights brighter.

There is no battery on the board and nowhere to fit one. The charging
circuit that used to sit there unpopulated has been removed: it could never
have worked, because the 3.3 V regulator needs more headroom than a lithium
cell can give it.

---

## Labelling it

The board is matte white on purpose. Glossy circuit boards reject
permanent marker — it beads up and rubs off on your thumb. Matte takes it
and keeps it.

There are faint ruled lines in the upper-left area, where a cassette's
paper label goes. Write on it. That is what it is for.

---

## Looking after it

It is a bare circuit board, and it is meant to be handled — but a few
things are worth knowing.

- **Keep it in the case.** It arrives in an ordinary cassette case. That
  is the best protection it will get.
- **There is a small hole under the microphone.** Do not cover it, block
  it with a sticker, or poke anything into it.
- **Do not get it wet**, and do not leave it somewhere very cold and then
  breathe on it.
- **Static** is the usual way to kill a bare board. Touch something
  earthed before picking it up in a very dry room. In normal conditions
  this is not something to worry about.
- **Handling noise.** It has a microphone on a bare board, so fingernails
  and flexing show up in the recording. Hold it by the edges while
  recording, or better, put it down. *(How much this matters is one of the
  things the first prototypes are meant to tell us.)*

---

## If something is wrong

**Nothing lights up.** Try a different cable — a surprising number of
USB-C cables are charge-only or simply broken. Then try a different port.

**It will not pair.** Make sure the speaker is in *its* pairing mode, not
just switched on. Hold the tape right against it. If the reels sweep amber
and then pulse red slowly, the speaker is talking to something else.

**It paired but there is no sound.** Check the speaker's own volume.
Press PLAY. If the tracks are empty there is nothing to play — the reels
will not move.

**It will not record.** Look at the top edge. If the tab is gone, that is
the answer, and it is permanent.

**A recording is shorter than expected.** Either you filled the track
(about four minutes) or power was interrupted. In both cases what was
recorded is intact.

**It sounds bad.** Try holding it by the edges, or setting it down
somewhere solid instead of holding it at all.

---

## For people who want to open it up

Everything is public: schematic, board files, firmware, and the design
notes that argue with themselves along the way. It descends from Open
Music Labs' Mixtape Alpha, and it inherits that project's attitude that
you should be comfortable touching a bare board.

There is no USB data connection — USB-C carries power only. Firmware is
loaded through six pads along the edge using a jig, which keeps the
production board simple. If you want to build one, the repository has the
details.

The board also has an unpopulated microSD footprint and an unpopulated
line-in jack, for anyone who wants to build a variant.

---

## Specifications

| | |
|---|---|
| Size | 100.0 × 63.5 mm, 1.6 mm thick — a cassette |
| Recording | 3 tracks, about 4 minutes each |
| Audio | Mono, 44.1 kHz, one built-in microphone |
| Storage | 16 MB, on board, no card needed |
| Wireless | Bluetooth Classic (A2DP) — ordinary earbuds and speakers |
| Paired devices remembered | 8, most recent tried first |
| Power | USB-C only. No battery |
| Case | Standard cassette case |

---

## What this does not do

Worth being straight about, because people ask:

- **It does not play in a tape deck.** It is cassette-shaped, but there is
  no tape head, and putting it in a deck will do nothing.
- **It is not a music player.** You cannot load MP3s onto it. It records
  what is in front of it. That is the entire idea — plenty of
  cassette-shaped players already exist, and none of them record.
- **There is no app**, and there will not be one.
- **It does not connect to your phone as a phone accessory.** It talks
  *to* speakers, the way a phone does.

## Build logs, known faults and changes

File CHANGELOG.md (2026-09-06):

# Changelog

All notable changes to this project will be documented in this file.

The format is based on [Keep a Changelog](https://keepachangelog.com/en/1.1.0/).
This project is pre-release; entries are dated rather than versioned until the
first prototype run.

## [Unreleased]

### Changed (2026-09-06, three pre-production questions answered)

- **The peony is the final B-side artwork.** The designer brief that used to
  live at `docs/b-side-silkscreen-brief.html` has been retired — there is no
  outstanding artwork commission. The 1:1 template
  (`hardware/mixxtape-back-silkscreen-template.svg`) stays for anyone reworking
  it later.
- **The four mounting holes are correct as drawn**, measured against the real
  shell. They are deliberately *not* a rectangle: 0.350 mm of skew across the
  rows and 0.250 mm between the columns, because the moulded bosses are not
  square either. A review flagged this as a defect on the reasonable assumption
  that they would be. **Leave them alone** — the note in the checklist now says
  so, so the next person to measure them does not "fix" it.
- **A real USB-C plug seats against a 1:1 print.** J1's mating face still sits
  0.767 mm inside the board edge with no relief notch; the setback is real but
  the predicted fouling is not. Whether the *closed shell* leaves room in front
  of the port is a separate question and stays open.

### Fixed (2026-08-30, a latent fatal fault in the LED footprint)

- **All 29 LEDs would have been reverse-powered.** The footprint
  `LED-SMD_4P-L2.0-W2.0-TL_WS2812B-2020` was drawn for the **genuine Worldsemi
  C965555** and still carried that part number in its `LCSC Part` property,
  while the BOM shipped the **XINGLIGHT clone C5349955**, whose pad 1 is on the
  diagonally opposite corner. Verified against LCSC's own library data: the
  Worldsemi land has pad 1 at (-0.915, -0.550); the XINGLIGHT part has it at
  (+0.675, +0.650). VDD would have landed on the GND net and GND on VBUS.
- **Nothing could have caught it.** ERC, DRC, the netlist and the BOM/CPL
  cross-check all passed, because every one of them trusts the footprint. There
  is no bodge for 29 parts on 0.225 mm of exposed copper with 0.64 mm between
  neighbours - it would have been a respin of the whole run.
- **The pitch was wrong too**, independently of the rotation: the board's pads
  sat at +/-0.92 mm in X against the real part's +/-0.675 mm, so a CPL rotation
  fix alone would not have saved it.
- Now **XL-1615RGBC-2812B (C5349954)**, which Steven has used before. Half the
  price ($0.040 against $0.060), double the stock, and its pin *functions* land
  in the same corners the board already routes to - **the swap needed no
  re-routing at all**, 0 unconnected. Its pad *numbering* is the manufacturer's
  (1=GND 2=DIN 3=VDD 4=DOUT), so the symbol's pins were renumbered to match
  while leaving their positions and names untouched, which kept every wire
  attached where it was.
- **The lesson, now written into `AGENTS.md`:** a footprint whose `LCSC Part`
  differs from its BOM line is a defect in itself. "Same protocol" says nothing
  about pad 1 - and that exact phrase, in `AGENTS.md` and in `gen_bom.py`, is
  what propagated this.

### Fixed (2026-08-30, eleven DRC rules were hiding 144 findings)

- Promoted 19 severities to error and fixed everything they surfaced: two
  dangling track stubs, two missing courtyards, a starved thermal relief on
  D24, eight hairline silk strokes at 0.06 mm that would not have printed at
  all, and text below JLC's 1.0 mm height and 0.15 mm thickness floors.
- `min_via_annular_width` raised 0.10 -> 0.13 mm, JLCPCB's real floor.
- `subtractmaskfromsilk` set to **yes** in the board. The export script already
  passed `--subtract-soldermask`, so the shipped Gerbers were safe - but anyone
  re-plotting from the KiCad GUI would have got unclipped silk on 54 pads.
- `silk_edge_clearance` deliberately left at **warning**: the B-side artwork is
  a full bleed and the fab clips it. Visible, not silenced.

### Fixed (2026-08-30, the programming interface had solder paste on it)

- **J5's six bare pogo pads carried `F.Paste`.** JLC would have stencilled
  1.5 mm of paste onto each with no part to absorb it, leaving six uneven blobs
  on the *only* way firmware can reach a bare board - USB-C is power-only, so
  J5 is a single point of failure for the entire project. Removed, on the board
  and in the library. `TAB1`, the other bare-copper feature, was already
  correct; J5 was simply inconsistent with it.
- Its silkscreen read `BNT`. Now `IO0`.

### Fixed (2026-08-30, the write-protect tab might not have been perforated)

- The six mouse bites existed only as **0.6 mm circles on Edge.Cuts** - milled
  features. JLCPCB's minimum internal routing feature is 1.0 mm, so a 0.6 mm
  milled circle is below what their router can cut: a DFM query, a silent
  omission, or a broken bit. Omitted, the tab is a solid 7.4 mm slab and the
  write-protect feature is dead on every board.
- Now NPTH pads in a `MOUSEBITE_6` footprint, verified present in
  `mixxtape-NPTH.drl`. **Still open:** 51 % of the break line remains solid
  FR4, because a 2.3 mm unperforated centre carries the 3V3 and TAB_SENSE
  traces. It will be stiff to snap.

### Changed (2026-08-30, Bluetooth range: the antenna keep-out was too narrow)

- The keep-out existed and was honoured - it was 22 mm wide, so **GND pour came
  within 1.85 mm of the module on the right and 2.10 mm on the left**, in the
  antenna's own plane, where it detunes it and absorbs near-field energy. This
  is the arrangement Espressif's guidelines name explicitly as the one to
  avoid: module inland, antenna ringed by ground with a small hollow.
- Widened to 35.5 mm. **Measured clearance is now 8.47 mm left, 8.97 mm
  right.** Nothing but pour was in the way, so this cost one polygon edit and a
  re-pour with zero re-routing.
- **The residual is stated rather than hidden:** Espressif recommend 15 mm. The
  left edge stops at 62.5 mm because the 3V3 and TAB_SENSE diagonals to the
  write-protect tab pass through; the right at 98.0 mm because EN and SPI_MOSI
  do. Reaching 15 mm means rerouting those, or notching the outline so the
  antenna overhangs - which would invalidate the case fit just verified against
  real plastic. 8.5 mm is a 4x improvement taken at zero risk.

### Added (2026-08-30, the board can now be diagnosed and repaired)

- **44 probe points.** All 110 vias were tented on both sides, so there was not
  one probe target that was not an accidental component-pad overhang. Untented
  55 on the diagnostic nets, then **re-tented the 11 that sit under a component
  body** - bare copper under an LGA microphone or the module is a short, not a
  test point. PDM_CLK and PDM_DATA now have four each; their only previous
  access was at the ESP32, 36 mm from the microphone.
- **Three cut-links**, so a board that arrives wrong can still be salvaged.
  Each is a narrowed neck in an existing trace with a solder-mask opening
  either side: cut to isolate, bridge to restore or re-route. On **VBUS**
  (0.6 mm neck) it isolates all 29 LEDs from the 5 V rail - every mA of array
  current passes through it, so it doubles as the ammeter point. On
  **LED_DATA_5V** it isolates the chain or injects a known signal. On
  **MIC_VDD** it isolates the microphone. Built from copper and mask apertures
  rather than footprints, so there is nothing for a future "update PCB from
  schematic" to delete.
- **Real pin-1 markers** for U1, U2 and U8. U8's was an `fp_poly` with two
  coincident vertices and zero width - a zero-area shape that plots as
  *nothing*, on a 5-pin SOT-23 whose silk outline is symmetric, so there was no
  orientation cue at all.
- **Seven GND stitching vias** on the F.Cu ground islands that hung off the
  plane by a single via, including U8's return path.

### Changed (2026-08-30, the AMS1117 had no heatsink)

- U4's tab is 8.4 mm2, there was **no 3V3 zone anywhere on the board** and no
  thermal vias - about 29 mm2 attached, the bare-pad end of the SOT-223 curve
  at roughly 135 C/W. Added a 3V3 pour on F.Cu around the tab; 37.7 mm2 fills,
  so about 67 mm2 attached.
- **Deliberately not mirrored on B.Cu.** That layer is the board's only solid
  ground plane and the reason the LED IR drop and the PDM return paths work at
  all. A larger pour was tried and rejected: it split the F.Cu ground pour and
  cost an unconnected item.

### Fixed (2026-08-30, firmware that would have shipped broken)

- **The SPI flash ran at 40 MHz full duplex.** ESP-IDF caps full duplex at
  26 MHz, because the dummy bits that compensate for MISO input delay cannot be
  inserted in that mode. The JEDEC ID would have read back garbage, init would
  have failed and **the tape would never have mounted** - no recording, no
  playback. Now 20 MHz.
- **And the factory test would have hidden it.** The jig uses 10 MHz, "gentle
  for bring-up", so it would have reported `flash_id PASS` on a board whose
  production firmware could not read the flash at all. The reassuring path is
  the one you run first.
- **`hal_read` handed the DMA engine a 4-byte stack array** and told it to send
  up to 2052 bytes. Both buffers are now static and word-aligned.
- **`probe_flash_id` used unaligned stack buffers as DMA targets**, which
  ESP-IDF rejects - it would have reported `flash_id FAIL` on a good board, on
  the first check of the first board.
- **Brownout detection re-enabled.** It was off on the reasoning that a reset
  mid-record beats riding out a dip. That assumes graceful degradation, and it
  is not what happens: below spec the ESP32 executes undefined, and if it is
  mid-write to its own internal flash the app partition corrupts. Worse, REC is
  GPIO0 - a messy reset while REC is held comes back up in **UART download
  mode**, dark and unresponsive, indistinguishable from a dead board.

### Changed (2026-08-30, NOR flash second-sourced and halved in price)

- **U3: Winbond W25Q128JVSIQ (C97521) → GigaDevice GD25Q128ESIG (C2758105)**,
  $2.2557 → $1.3348 at a run of 20. Net **$15.41 saved** after the one-off
  Extended-part setup fee the Winbond Basic part did not carry.
- The land patterns agree to within **0.02 mm**, so nothing in the layout
  moved. Command set (0x06, 0x05, 0x03, 0x02, 0x20, 0xD8, 0x9F) and the
  256 B page / 4 KiB sector / 64 KiB block geometry are identical, so the
  storage design is untouched.
- The **only** difference is the JEDEC manufacturer byte: 0xC84018 rather than
  0xEF4018. Rather than move the hard-coded constant, **both the driver
  (`spi_flash_hal.c`) and the factory test (`factory_main.c`) now accept
  either id** and log which part was found. C97521 therefore stays a real
  drop-in second source: if GigaDevice stock moves before the order goes in,
  a Winbond-populated board still boots with no firmware change. Do not
  narrow that check back to one value.
- Host tests: 11/11 pass.
- Board cost **$9.41 → $8.62**.

### Changed (2026-08-30, passives standardised on 0402)

- **The eight 10 k resistors moved R0603 → R0402** (C25804 → C25744). Cheaper
  as well as smaller — $0.0031 against $0.0053, Basic, 33 M stock. Every trace
  still reached its pad; DRC stayed clean with nothing to re-route.
- **C1 and C2 stay 0805.** The only Basic 10 µF in 0402 is 6.3 V, and C1 sits
  on the 5 V USB rail — 79 % of rating, where DC-bias derating would leave
  roughly 2 µF of the nominal 10, for 29 LEDs. Saving $0.07 a board is not
  worth three quarters of the bulk capacitance. Two passive sizes, not three.

### Fixed (2026-08-30, ERC was not actually clean)

- **Three dangling-wire errors** — 1.27 mm stubs at y=67.31 — left behind when
  the capacitive touch pads were removed. The removal script deleted the TP
  symbols and their global labels but not the wires between them.
- These had been reported as "ERC 0" because the report being read was a stale
  `mixxtape-erc.rpt` from 26 August. **`kicad-cli` writes its report relative
  to the working directory, not next to the board**, so running it from the
  repo root silently leaves the old file in `hardware/` untouched and
  believable. Both locations are now gitignored, and the checked-in copy is
  deleted — a generated report should never have been tracked.
- ERC is now genuinely 0 errors, 0 warnings.

### Fixed (2026-08-30, gen_layout.py would undo the board)

- The pre-production checklist told the reader to record case-fit measurements
  by editing `hardware/scripts/gen_layout.py` and re-running it. That script
  rebuilds the **original 100.33 mm outline** and would discard the trim to
  99.50 mm along with every placement and route since. The instruction now
  says to edit the board directly and re-run `export_fab.py`.

### Verified (2026-08-30, the board fits a real cassette case)

- Steven printed `case-fit-test-1to1.pdf` at 1:1 and checked it against a real
  plastic case: **it fits.** This retires the largest mechanical unknown in
  the project — the outline was borrowed from a board that fits *some* case,
  and the reel windows, tab position and mounting holes are ours and had never
  touched plastic.
- Still open: the same test against cases from **other brands**. One case
  proves the design is not wrong; it does not prove it is right, and internal
  ribs and hub-clamp ridges vary between manufacturers.

### Added (2026-08-30, fabrication package committed)

- `fab/` now holds the actual JLCPCB upload — gerbers zip, BOM and CPL — plus
  a README covering order settings and what to check in their previewer.
  Regenerate with `hardware/scripts/export_fab.py`, which refuses to run on a
  board that is not DRC clean and cross-checks the BOM against the placement
  file. Intermediate gerbers stay gitignored; the zip is the artefact.

### Changed (2026-08-30, bulk capacitors right-sized)

- **C1 and C2: 22 µF 25 V (C45783) → 10 µF 25 V (C15850)**, both Basic, same
  0805 footprint. Nothing on this board exceeds 5 V — C1 sits on USB VBUS and
  C2 on the regulated 3.3 V rail — so 25 V was 5× and 7.5× margin respectively.
- **JLCPCB's Basic library has no 10 V or 16 V part in these sizes**, only 25 V,
  so dropping the voltage rating would have meant leaving Basic and paying a
  setup fee. Dropping the *capacitance* instead keeps it Basic and costs less.
- Counter-intuitively this loses almost no real capacitance. Ceramics derate
  under DC bias: a 22 µF 6.3 V part at 3.3 V delivers perhaps 8–10 µF, while a
  25 V part barely derates. **A 10 µF 25 V cap gives more capacitance in
  circuit than a 22 µF 6.3 V one**, at a fraction of the price.
- **C9: 1 µF Extended (C29266) → Basic (C52923)**, 25 V rather than 16 V. The
  other five Extended parts — LED, USB-C, ESP32, microphone, level shifter —
  have no Basic equivalent at all.
- Board cost **$10.01 → $9.41**, setup fees $18 → $15.

### Fixed (2026-08-30, part numbers scrambled twice by careless patching)

- Two attempts at these swaps split the schematic on `(symbol "` and applied a
  replacement to every resulting chunk. The final chunk runs to end-of-file and
  therefore contains **every component instance**, so one symbol's part number
  was written onto all 66 parts. Both times the generated BOM caught it
  immediately — every line collapsed onto a single part and the cost fell to
  something absurd.
- Now fixed properly: the `lib_symbols` block is located by matching
  parentheses, and library edits are confined to it by construction, with an
  assertion that no instance can appear inside.
- The repair also surfaced a **second, redundant `LCSC Part` property** that
  easyeda2kicad writes alongside `LCSC`. Nothing had ever maintained it, so it
  was stale on several symbols — including WS2812B-2020, which was carrying the
  Worldsemi part number the project stopped using months ago. Both properties
  now agree on every symbol.
- Verified: ERC 0 · DRC 0 · board and schematic agree on all 287 pads · every
  instance's part number checked against the expected design, count by count.

### Changed (2026-08-29, board narrowed to 99.50 mm)

- **The outline is now 99.50 × 63.50 mm**, trimmed 0.83 mm off the left edge
  where there are no components. The left edge and both left corners moved
  right; everything else — copper, silkscreen, every part — stayed exactly
  where it was.
- **The two left mounting holes moved with the edge.** Left in place they would
  have finished 0.82 mm from the new edge instead of 1.65 mm, which is not
  enough rim for a mounting hole.
- **A bug in the first attempt was caught by measuring, not by DRC.** The shift
  was applied per coordinate, so for the two left mounting holes the centre
  moved but the radius-defining end point did not — turning them from Ø2.20
  into Ø0.54. A 0.54 mm hole is perfectly legal, so DRC passed it without
  comment. Circles are now moved as whole objects.
- **`gen_silk_template.py` now reads the board size from Edge.Cuts** instead of
  hardcoding it, so the artwork template cannot drift from the outline again.
  `gen_layout.py` carries a warning: re-running it would rebuild the original
  100.33 mm outline.
- Propagated to the README, the pictogram sheet, the fabrication README, the
  B-side designer brief — including its dimensioned keepout table and its scale
  drawing — and the bounds constants in `add_zones.py` and `gen_placement.py`.
- Verified: DRC 0 errors, 0 unconnected; outline closed with no dangling
  endpoints; every other cutout unchanged in position and diameter.

**Note for the artwork:** the peony design was drawn full-bleed to 100.33 mm.
It still covers the board, but 0.83 mm now falls off the left edge and the
composition sits fractionally off-centre. Worth a look before the run.

### Added (2026-08-29, JLCPCB fabrication export)

- **`hardware/scripts/export_fab.py`** builds the whole package: gerbers, drill
  files, the placement file remapped to JLCPCB's column names, the BOM, and the
  zip. Settings follow JLCPCB's own KiCad guide — Protel extensions, soldermask
  subtracted from silkscreen, zone fills checked, Excellon in millimetres with
  a decimal zeros format and absolute origin. X2 is off for the widest CAM
  compatibility.
- **It refuses to export a board that is not DRC clean**, and it cross-checks
  the BOM against the placement file: a designator in one and not the other
  stops the run. Both files agree on all 66 designators.
- Drill map gerbers are generated but deliberately kept out of the zip — they
  are documentation, and a stray `.gbr` can be mistaken for a copper layer by
  an auto-detector.

### Fixed (2026-08-29, two parts would have been assembled wrongly)

- **DNP is stored per footprint on the board, not only in the schematic.** J4
  and R9 were marked Do Not Populate in the schematic but carried no DNP
  attribute on the board, so `--exclude-dnp` had nothing to act on and both
  landed in the placement file. An order placed from that export would have had
  **a microSD socket fitted to every board**.
- **J5, the programming jig pads, was in the placement file too.** Its
  footprint had `exclude_from_bom` but not `exclude_from_pos_files` — an
  omission from when it was first drawn. It is bare copper, not a part.

### Changed (2026-08-29, R9 is fitted)

- **R9 is now populated**; only J4 stays DNP. R9 is the pull-up that keeps the
  SD chip-select pin defined with the socket unfitted. Its value drops the
  "(DNP)" suffix and it folds into the 10 k line, which becomes ×8.

### Removed (2026-08-29, capacitive touch pads)

- **The touch pads are out.** TP2/TP3/TP4, their footprints, all 29 track and
  via segments on the TOUCH nets, the symbols, the labels, and the pin block in
  `board.h`. GPIO 2, 13, 14 and 15 are unallocated again, with their no-connect
  markers restored so ERC knows they are unused on purpose.
- **The footprint and symbol stay in the libraries.**
  `mixxtape_local:TOUCH_PAD_12` and its schematic symbol cost nothing sitting
  there, and they carry the working geometry — a 12 mm pad under the solder
  mask with a no-pour rule area on both layers — if the idea returns.
- The line-out document's rejection reasoning was corrected: it had said its
  pins were taken by touch pads, which is no longer true. It is still rejected,
  on scope rather than feasibility, and IO26/IO13/IO14 are free again.
- Verified after removal: **ERC 0, DRC 0, board and schematic agree on all 287
  pads**, and no `TOUCH` reference survives in the board, the schematic or the
  firmware.

### Added (2026-08-29, capacitive touch pads on the back)

- **Four Ø12 mm touch pads on B.Cu**, TP1-TP4, on the ESP32's touch channels
  **T2/T3/T4/T6 (GPIO 2, 15, 13, 14)**. Copper under the solder mask — mask is
  a good dielectric for sensing and it keeps the copper from tarnishing, so
  nothing is exposed. **No BOM cost at all**: a touch pad is a shape in the
  copper.
- **T5 (GPIO12) was available and was deliberately skipped.** It is the MTDI
  strap that selects flash voltage, and a floating copper plane is the last
  thing to hang on it — read high at boot and the module does not start. T2 and
  T3 are also strapping pins but only for boot mode and log suppression, and a
  pad adds capacitance rather than a DC level.
- The footprint **carries its own no-pour rule area on both layers**, so the
  ring that isolates the pad from the ground pour, and the cut-out that keeps a
  plane from sitting directly behind the sensor, travel with the pad wherever
  it is dragged.
- **Left unrouted on purpose.** The pads are meant to be moved to suit the
  artwork, and routing now would only have to be undone.
- Pin definitions added to `board.h`, including the note that touch v1 on the
  original ESP32 drifts with temperature and humidity, so the firmware wants a
  slow baseline rather than a fixed threshold.

### Removed (2026-08-29, line-out option closed)

- **The 3.5 mm jack is not being built.** `docs/line-out-option.md` is marked
  rejected rather than deleted — the part numbers, stock figures and costs in it
  were all verified and stay useful, and it records why IO13 and IO14 went to
  touch pads instead.

### Fixed (2026-08-29, placement caught by DRC)

- The first touch-pad placement dropped **TP3 straight on top of the button
  signals and their vias** on the back copper — ten shorts and four hole
  clearance errors. The space scan behind it only checked footprint courtyards,
  not tracks and vias. Rescanned properly against the back copper, which turned
  out to be far denser than the footprint map suggested, and re-placed.

### Added (2026-08-29, wordless quick-start pictograms)

- **`docs/quick-start-pictograms.html`** — IKEA-style instructions for the four
  things people actually do: pair, play, record, next track. No prose in the
  panels; a printable single sheet.
- **The device is drawn to its real proportions** — 100.33 × 63.50 mm, with the
  reel windows, the five status lights, the four buttons, the write-protect
  tongue, the microphone and the USB-C port all in their true positions. The
  picture matches the object in your hand rather than a generic cassette.
- Gestures were taken from `ui_state.c` rather than from the prose, which
  turned up that **MODE has three hold tiers** — 2 s pair, 5 s dub, 10 s
  dev-wifi — and that under 2 s it deliberately does nothing.
- Three things a picture cannot carry are stated in words at the foot:
  holding PLAY for a second sleeps the device, recording overwrites the
  selected track from the beginning, and MODE ignores short presses on purpose.

### Added (2026-08-29, line-out option assessed)

- **`docs/line-out-option.md`** — the write-up for adding a 3.5 mm jack, for
  line-out to a powered amp or wired headphones. Proposed only; nothing is on
  the board.
- It comes out cheap because four things happen to already be true: IO26, IO13
  and IO14 are free and unstrapped (IO26 was freed by the microphone's move to
  PDM); the mic sits on `I2S_NUM_0` so **I2S1 has never been touched**;
  playback is already pull-shaped, so an I²S output task calls the same
  `tape_player_read` the A2DP path does; and `bt_audio.c` already duplicates
  mono into interleaved stereo, which is exactly what a stereo DAC needs.
- **~$1/board and about two days of work**, most of it layout — the board is
  fully routed at zero DRC errors, so three new signals crossing 40 mm means
  re-routing, re-pouring and re-checking the placed B-side artwork.
- **Surface-mount jacks are plentiful.** PJ-320D ([C431535](https://jlcpcb.com/partdetail/C431535))
  has 79,274 in stock at $0.037. Confirmed surface-mount by reading footprint
  pad data rather than trusting JLCPCB's category field, which is unreliable
  for connectors.
- **Records the trap:** the MAX98357A is the usual ESP32 audio answer and is
  wrong for a jack — its bridged output has no ground reference, so a plug's
  sleeve shorts half the bridge. It is for a soldered speaker.
- The document separates what was verified from what was not, including the
  claim that a PCM5102A cannot drive 32 Ω headphones — that follows from its
  datasheet role, not from measurement.

### Changed (2026-08-29, documentation consolidated)

- **The README's hardware summary now carries JLCPCB part numbers, each linked
  to the part page**, plus per-part quantities. Rewriting it turned up three
  errors that had been sitting there: the microphone was still listed as
  MSM261S4030H0R, as I²S, and as bottom-ported. All three were corrected
  elsewhere months ago and never here. The cost was also stale at $13.25/board
  against the generated BOM's $10.01.
- **The agent brief was the worst of the drift.** It still specified the CH340N
  USB-UART and USBLC6 ESD diode (both deleted when USB-C went power-only), SBC
  encoding at record time (now ADPCM), a castellated header and a lanyard hole
  (neither exists), UART routed to the CH340N, and the superseded BOM as
  authoritative. All corrected.
- **`cassette-recorder-bom-v3.md` deleted.** Its one lasting value — the list of
  seven ways a hand-maintained BOM drifted from the board — now sits at the top
  of the generated BOM, where someone tempted to hand-edit will see it.
- **Added `docs/README.md`**, an index grouping the documents by what they are
  for, and naming which files are generated and by which script. Every relative
  link across the repository's markdown now resolves.
- The pre-production checklist gained a manufacturability section from the
  JLCPCB audit, and lost its references to the lanyard hole, which the board no
  longer has.

### Checked (2026-08-29, USB-C receptacle)

- **No board notch is needed.** The TYPE-C-31-M-12 is a top-mount right-angle
  receptacle; its only board penetrations are four plated shell legs and two
  non-plated locating pegs, all already in the footprint. Notches are for
  *mid-mount* receptacles, which sit partly through the board. This is not one.
- Its mouth sits **0.76 mm inboard of the board edge**, with the strip in front
  clear of copper and components, and the edge there is a straight run from
  y 2.54 to 60.96. The plug's shell passes over that lip because the mouth is
  raised above the board surface.
- Open question for the checklist: a closed Norelco case has a wall on that
  edge, so decide whether the board comes out to charge or the case is modified.

### Fixed (2026-08-29, manufacturability audit against JLCPCB)

- **The microphone was tagged `through_hole` while carrying eight SMD pads.**
  A footprint's attribute decides whether JLCPCB's pick-and-place file lists
  the part, so U2 could have been dropped from the CPL and left unassembled on
  every board. J1 had the mirror of the same fault, tagged `smd` with four real
  plated through-hole pads. Both corrected in the board and the libraries.
- **Eleven DRC rules were set to `ignore`**, hiding 145 findings — every
  silkscreen check, every courtyard check, footprint type mismatch and mirrored
  text among them. The mic's wrong attribute is exactly what
  `footprint_type_mismatch` exists to catch, and it had been switched off. The
  eight that matter are back on as warnings.
- **80 silkscreen strokes were below JLCPCB's 0.15 mm minimum**, some as thin as
  0.06 mm, inherited from the easyeda2kicad footprints; the board default was
  0.10 mm. Raised to 0.15 mm in the board and the libraries. Filled artwork
  polygons were left alone — their stroke is cosmetic, the fill is what prints.

### Checked (2026-08-29, against JLCPCB 2-layer capabilities)

- Narrowest track 0.150 mm against a 0.10 mm limit; vias 0.60/0.30 mm against
  0.25/0.15 mm; copper-to-edge held at 0.40 mm against 0.20 mm. All comfortable.
- **Two figures sit close to the line.** The smallest plated annular ring is
  0.200 mm on J1, under JLCPCB's recommended 0.25 mm though above the 0.18 mm
  floor. Closest hole-to-hole is 0.500 mm against a 0.45 mm limit, inside the
  DNP microSD footprint.
- **White solder mask is confirmed available**, adds about two days, and pairs
  with **black silkscreen as a fixed choice** — that settles an open question in
  the B-side brief.
- **The B-side artwork carries 32 shapes thinner than 0.15 mm** in one dimension
  and 52 more between 0.15 and 0.25 mm. The first group will not survive the
  screen. Recorded in the brief for the designer.

### Added (2026-08-29, README artwork)

- The 3D turntable render and the case artwork mockup now open the README, with
  a note that the render's green mask is the viewer's default rather than the
  matte white the board ships in.
- `artwork/exec-31918c24-…png` renamed to `artwork/case-mockup.png`.

### Added (2026-08-28, cassette insert template)

- **Double-sided J-card template for the case insert**, 1:1, as two SVGs and a
  two-page PDF. Panels follow the stepped standard — front 65.0875 mm, spine
  12.7 mm, tracklist flap 26.9875 mm, card 101.6 mm across — where each folded
  panel is 1/16 inch narrower than the one before so the card nests inside its
  own folds instead of binding.
- The 101.6 mm runs horizontally, matching the board's 100.33 mm, so the front
  panel reads upright at 101.6 x 65.09 and the folds are horizontal.
- **Two pages, card in the same position on each**, because that is what duplex
  printing needs. Long-edge flip; the card is centred, so every panel backs
  itself.
- The tracklist is **ruled and deliberately blank**. The owner records the
  tracks, so printing a fixed listing would be wrong — it is a write-on field,
  the same reasoning as the matte white mask on the board.
- Carries the same 50 mm calibration bar as the case-fit sheet, plus cut, fold,
  safe-area and bleed marks.

### Fixed (2026-08-27, CI: the `bt` component name collided with ESP-IDF's)

- **`firmware/components/bt` is renamed to `components/btaudio`.** ESP-IDF
  ships its own component called `bt`, and project components override
  IDF's by directory name, so ours silently shadowed the real Bluetooth
  component. `esp_hid` then lost the include paths it inherits through
  `bt` and the build died on `esp_timer.h: No such file or directory` —
  an error inside IDF's own source, which is why it read as an IDF problem
  rather than ours.
- **The IDF build has been red since 3dcf692** ("pairing policy and
  persistent bond table"), the commit that created the component. Four
  consecutive failures, all the same cause. Host tests were green
  throughout, which is why it went unnoticed.
- The constraint is now written down in `firmware/README.md`, because the
  next person to add a component called `console`, `driver` or `log` will
  hit exactly this.

### Changed (2026-08-27, CI runs on pull requests only)

- The firmware workflow no longer runs on push; it runs on `pull_request`
  and `workflow_dispatch`. **This repo commits straight to main, and a push
  to main opens no pull request** — so unless the habit changes to raising
  PRs, CI now only runs when triggered by hand from the Actions tab.
- `actions/checkout` bumped v4 → v5, clearing the Node 20 deprecation
  warning that was annotating every run.

### Removed (2026-08-27, battery section)

- **The TP4056 charger, its JST battery connector and PROG resistor are
  gone** (U5, J2, R8, plus the VBAT and PROG nets). They were always DNP,
  and they could never have worked: VBAT dead-ended at the connector and
  the charger, and even wired through, a lithium cell at 3.0–4.2 V cannot
  feed an AMS1117 that needs 1.1–1.3 V of headroom to make 3.3 V. The LEDs
  and the level shifter sit on the 5 V USB rail besides. Running from a
  cell means a different regulator and a different LED rail — a redesign,
  not a populated footprint. Removing it frees about 40 mm² on a board
  that is about to be routed.
- Docs no longer promise a battery footprint you can solder to. "USB-C
  only" was already the locked decision; now the board matches it.

### Fixed (2026-08-27, schematic review before routing)

- **The board outline was self-intersecting and would have failed CAM.**
  The write-protect tab's two slots were drawn as closed rectangles lying
  *on top of* the top edge instead of cut into it, so the edge ran straight
  through both — four real crossings. Split the top edge into three spans
  and removed the slot mouths. The outline is now a single closed loop with
  no crossings and no dangling endpoints, and the stale zone fills that
  came with it are refilled.
- **Every symbol pin now has a real electrical type.** easyeda2kicad types
  every pin `unspecified`, which silently disables the checks that matter.
  109 pins retyped from the datasheets, in the schematic *and* in
  `mixxtape_parts.kicad_sym` so a library update cannot undo it. Turning
  the checks on immediately found three genuine faults: U4's two VOUT pins
  and J1's paired VBUS and GND pins each read as two power outputs fighting
  over one rail. They are duplicate pins of one physical node, so one of
  each pair now carries the `power_out` and its twin is `passive`.
  **ERC: 191 warnings → 0 violations.**
- **TAB1 had no footprint at all**, so TAB_SENSE would have read
  permanently low. Added `mixxtape_local:TAB_BREAKOFF_LINK`, a two-pad net
  tie placed on the break-off tongue: snap the tongue and the link goes
  with it. Note for routing — both nets must cross the perforation through
  the gaps between the bite holes, and freerouting does not understand net
  ties, so hand-route those two first.
- **C9 was 100 nF on EN; the ESP32-WROOM-32E datasheet asks for 1 µF**
  (§ "it is advised to add an RC delay circuit at the EN pin… R = 10 kΩ and
  C = 1 µF"). Changed to C29266.
- **Added R12, 100 Ω (C25076), in the microphone's supply**, per figure 1
  of the MSM261DHT006 datasheet. C7 moves onto the new MIC_VDD net so the
  two form an RC filter — left on 3V3 it would just be another rail cap.
  A PWR_FLAG marks MIC_VDD as driven, and `gen_bom.py` now skips
  `in_bom no` symbols so the flag is not a phantom BOM line.
- **Four through-hole pads had zero annular ring** (J1 ×2, J4 ×2) — the
  connectors' moulded locating pegs, where pad size equalled drill size.
  Now `np_thru_hole`, fixed in the board and in the library footprints.
- **Datasheet links corrected.** D1–D29 pointed at Worldsemi C965555 while
  the fitted part is XINGLIGHT C5349955; the two symbols cloned for R12 and
  C9 had inherited their donors' links.

### Added (2026-08-27, mounting holes)

- **Three Ø2.2 mm mounting holes** at the top-left (32.75, 32.75),
  bottom-left (32.75, 90.75) and top-right (122.50, 32.75), each with the
  Ø4.2 mm annotation ring the existing holes use. The top-right one sits
  8.3 mm inboard rather than in the corner because the microphone is there
  — there is no room between it and the board edge. Moving the mic ~3 mm
  left would free (127.58, 32.75) for a symmetric pattern.
- **`mixxtape.kicad_dru`**, scoping a 0.1 mm clearance exception to J1. The
  USB-C receptacle's own pads sit 0.10 mm apart against the board's 0.20 mm
  rule; that is the connector's geometry, not our routing.
- Verified: **ERC 0, DRC clean apart from the 130 unrouted nets, every
  footprint's pads reconcile with its symbol's pins, and every board pad
  agrees with the schematic netlist.**

### Changed (2026-08-25, microphone: MSM261DHT006, PDM)

- **Microphone changed to MSM261DHT006 (C51928215)** across schematic,
  layout, firmware and docs, replacing MSM261S4030H0R (C2840615) which is
  at zero stock. Acoustically an equal swap — identical −26 dBFS
  sensitivity, same 1.6–3.6 V range, same 4×3 mm LGA-8 outline, 1 dB less
  SNR and 2 dB *better* acoustic overload — at $0.45 against $1.61.
- **This was a schematic change, not a part-number swap.** The pinout is
  completely different: pin 1 is VDD where the old part had GND, L/R moves
  to pin 2, and pins 5–8 are all GND. Footprint changed to
  `LGA-8_L4.0-W3.0-R_WMM7040DT0`.
- **Interface moves from I²S to PDM.** Two wires instead of three, so
  **GPIO26 is freed**. GPIO25 becomes the PDM clock, GPIO33 the data input.
  The ESP32's I²S peripheral does PDM receive and decimation in hardware,
  so nothing downstream of the capture task changes.
- **PDM downsample ratio must be 64.** PDM clock = sample rate × ratio, and
  44100 × 128 = 5.64 MHz exceeds the microphone's 4.8 MHz maximum. 64 gives
  2.8224 MHz, inside its window. Recorded in `board.h` because it is the
  obvious mistake to make.
- Board cost drops to **$9.85/board** at 20 boards, from $11.01.
- ERC 0 errors, DRC 0 violations, 11 host suites still green.

### Fixed (2026-08-25, microphone datasheet review)

- **The brief's "bottom-ported" microphone is actually top-ported.** The
  specified MSM261S4030H0R datasheet says so on page 2 ("omnidirectional,
  Top-ported, I²S digital output"), and so does every in-stock alternative
  in the family. The 0.5–0.8 mm acoustic hole the brief called for through
  the board would have done nothing except weaken it — sound enters from
  the component side. Hole removed from the mechanical layout and replaced
  with a keep-clear annotation; the brief is corrected at source.

### Findings (2026-08-25, microphone replacement)

- **MSM261DHT006 (C51928215) is acoustically an equal swap**, not a
  downgrade: identical −26 dBFS sensitivity, same 1.6–3.6 V range, same
  4×3 mm LGA-8 footprint, 1 dB less SNR (60 vs 61 dB) and 2 dB *better*
  acoustic overload point (122 vs 120 dB SPL) — which matters for a
  recorder that will meet the occasional door slam. Cheaper too ($0.45 vs
  $1.61) and lower current.
- **Its one real cost is the interface: PDM, not I²S.** Firmware would
  initialise the ESP32's I²S peripheral in PDM RX mode, which the original
  ESP32 supports in hardware. This is a firmware change, not a hardware
  one — the pin count and footprint are unchanged.
- **Alternative if the firmware change is unwelcome:** ICS-43434
  (C5656610, ~3.7k, $3.33) keeps I²S and gains 5 dB of SNR (65 dB) on the
  project's riskiest subsystem — but costs 7× more (+$58 across 20 boards)
  and has a different 3.5×2.65 mm footprint, so symbol and land pattern
  both change.

### Added (2026-08-25, supply-chain rule and the case-fit test)

- **Supply-chain rule (Steven):** every fitted part must have 5,000+ in
  stock at JLCPCB, and a common part beats a capable one. Enforced by
  `gen_bom.py`, which now prints a rule section; `find_common_parts.py`
  searches for compliant alternatives. Exceptions must be argued in
  `STOCK_EXCEPTIONS` rather than waved through.
- **Audit result: every fitted part clears 5,000 except the microphone.**
  The nearest thing to a problem elsewhere is the ESP32 module at 24k,
  which is a locked decision anyway (only ESP32 with Classic Bluetooth).
- **⚠ No digital MEMS microphone at JLCPCB meets the rule.** The whole
  category is thin — the best-stocked digital part is ~3.5k. The only mic
  that clears 5,000 (ZTS6216, C481302, 29k) is **analog**: it needs a
  DC-blocking cap and a gain stage into the ESP32's ADC, which the brief
  already calls a lo-fi path with ~9 effective bits. Meeting the rule there
  would wreck the product's only input, so a digital part at ~3.5k is
  recorded as an accepted exception with three qualified alternates.
- `docs/case-fit-test-1to1.pdf` — printable board outline at 1:1, with a
  50 mm calibration bar so a silently scaled print is caught before
  anything is measured against it.
- `docs/PRE-PRODUCTION-CHECKLIST.md` — the case-fit procedure, every open
  decision, what to re-quote, and the three prototype questions that could
  still change the hardware. Linked from the README.

### Added (2026-08-25, PCB mechanical layer)

- `hardware/mixxtape.kicad_pcb` — board outline, reel windows, break-off
  write-protect tab, lanyard hole and microphone port. Generated by
  `hardware/scripts/gen_layout.py`; DRC clean. **Mechanical only** — no
  components placed and no routing, which is the brief's phase 2 and the
  part that has to be checked against a real case before any copper.
- **The outline is not redrawn from a standard.** Per the brief, it is
  traced from Open Music Labs' Mixtape Alpha released gerbers
  (`hardware/scripts/cassette_outline.json`, 104 segments,
  100.33 × 63.50 mm) — a cassette shape that has actually been fabricated
  and fits real cases, which beats a dimension copied out of a datasheet.
- Reel hubs at the compact-cassette standard 42.0 mm spacing, 34.3 mm from
  the bottom edge (measured off the Mixtape Alpha board render — they sit
  slightly above centre, which is what makes it read as a cassette). Ø14 mm
  windows with the twelve LED positions marked on a Ø18 mm ring.
- Tab is 9 × 5.5 mm at the top-left, held by five 0.6 mm mouse bites, with
  routed slots either side.

### Needs Steven (2026-08-25)

- **⚠ Licence of the borrowed outline is unstated.** The Mixtape Alpha wiki
  publishes the board files but names no licence for them (the "GPL
  licensed" on that page refers to the wiki software). Confirm with Open
  Music Labs before distributing derived artwork. Mitigation if they
  decline: the shape is the compact-cassette form factor, so redrawing it
  from a measured cassette is straightforward.
- **Print the outline at 1:1 and put it in a real case.** Reel window
  diameter versus hub-clamp ridges, tab position versus internal ribs, and
  the lanyard hole versus the hinge are all still assumptions. Case brands
  are not dimensionally consistent — the brief says buy several.
- The five decorative guide holes along the bottom edge are deferred: they
  never enter a deck, so they are artwork rather than mechanism, and
  guessed positions would constrain component placement for nothing. Add
  them with the silkscreen artwork.

### Added (2026-08-25, BOM v4 — generated, with live pricing)

- `hardware/scripts/gen_bom.py` — derives the BOM from
  `hardware/mixxtape.kicad_sch` and reads prices, stock and library type
  live from JLCPCB, emitting both `docs/cassette-recorder-bom-v4.md` and a
  JLCPCB-format assembly CSV. Requests are paced and cached because JLC
  throttles bursts.
- **BOM v3 had drifted from the schematic in seven places** and is now
  marked superseded: it still listed the CH340N, USBLC6 and S8050 pair
  (deleted when USB-C became power-only) and the ME6211 LDO (replaced by
  the AMS1117), and was missing the fitted WS2812 substitute, the
  SN74AHCT1G125 level shifter and the DNP microSD footprint. Generating it
  removes that whole class of error.

### Findings from live JLCPCB data (2026-08-25)

- **⚠ The microphone is out of stock.** MSM261S4030H0R (C2840615) shows
  zero at JLC — and it is the one part the product cannot ship without.
  Same-family alternatives are in stock at roughly a third of the price
  (C51928215, C22390138, C51928210), but the part-number suffix encodes
  package and port direction, and this design needs a **bottom-ported**
  mic because there is an acoustic hole through the board beneath it. Each
  candidate needs its datasheet checked before substituting. Needs Steven.
- NOR flash is up as the brief predicted: W25Q128 is $2.26 against v3's
  $1.65.
- Parts now cost **$11.01/board** at 20 boards ($205.20 components +
  $15.00 in setup fees for 5 extended parts), against v3's ~$8.50 estimate
  for components. PCB and assembly labour are quoted separately.
- At this quantity the per-extended-part setup fee dominates: adding a new
  extended part costs $3, while using more of one already on the board is
  nearly free.

### Added (2026-08-25, user documentation)

- `docs/MANUAL.md` — the manual as it would ship with a board: getting
  started, the controls, recording and playback, the light language, the
  write-protect tab and why it is permanent, power, labelling, care,
  troubleshooting, specifications, and a plain list of what the device
  deliberately does not do.
- `docs/FAQ.md` — the questions people actually ask, answered against the
  design as built, with a closing section of honest limitations (no way to
  get recordings onto a computer, twelve minutes total, mono, handling
  noise still unproven, needs mains power, will not play in a deck).
- Both carry a draft banner and mark unverified claims as such — sound
  quality, handling noise, AirPods compatibility and reconnect latency are
  design intent until prototypes exist, and the docs say so rather than
  implying they are settled.
- Neither document uses the project's current name, since it collides with
  Mixxim's commercial product and a rename is planned; they say "your
  tape" throughout, which reads better anyway and makes the rename a
  non-event.

### Added (2026-08-25, firmware — record-path limiter)

- `components/audio/limiter` — look-ahead peak limiter with bounded makeup
  gain, replacing the whole-take peak normalisation that one-pass recording
  gave up. One gain does both jobs:
  `target = min(max_gain, ceiling / envelope)` — loud rooms are pulled down
  and cannot clip, quiet rooms are lifted (up to +18 dB) so an ambient take
  is actually audible. It is also the better tool than normalisation, which
  a single door slam defeats.
- The envelope is a true **sliding maximum** over a window that includes
  the sample about to leave the delay line, not a decaying peak follower.
  That makes `|output| <= LIMITER_CEILING` a hard guarantee for any input
  rather than a fast attack that usually keeps up — a decaying signal
  defeats the cheap version, and there is a test for exactly that case.
- Gain falls immediately and rises slowly: the immediate fall lands on
  audio still inside the 10 ms delay line, so it is inaudible, while the
  slow rise (~371 ms) stops the noise floor pumping between words. A gate
  freezes the gain below -44 dBFS so a silent room is not amplified into
  hiss. Integer throughout, so host and target results are identical.
- Also feeds the REC lamp and reel brightness via `limiter_level()`.
- Host tests: the ceiling invariant is checked against full-scale squares,
  near-Nyquist content, rail-to-rail alternation, noise and a decaying
  tone; look-ahead is proven by a silence-to-full-scale burst whose *first*
  cycle already sits at the ceiling; plus delay accounting, gain bounds,
  gate behaviour, smooth recovery, in-place aliasing, and invariance to
  chunk size. 11 suites, ~62,000 assertions, green in ~1.8 s.

### Fixed (2026-08-25)

- Level meter decay stalled at 3/255 because the shift-based decay
  underflows below 2^9, which would have left the REC lamp faintly lit
  forever after a loud take. Caught by `test_limiter`.

### Added (2026-08-25, firmware — pairing policy and bond storage)

- `components/bt/pairing` — the selection policy that makes "hold the board
  against the speaker" the entire interaction. Class-of-Device filtering
  drops phones, laptops, peripherals and wearables so the user never sees a
  list of their own hardware, and rejects the non-sink members of the
  Audio/Video class (microphones, set-top boxes, VCRs, cameras, monitors).
  RSSI then makes proximity the selection mechanism. Ties keep the earlier
  entry so repeated inquiries do not make the board look like it is
  dithering. Speakers that omit the Audio service bit are still accepted —
  plenty of cheap ones do.
- Reconnect backoff with the "sink busy" signal: the sink is usually busy
  reconnecting to its owner's phone at power-up, so attempts back off
  exponentially to a cap, and after ~15 s the user is told honestly rather
  than left watching a hopeful blink. Correct across the millisecond
  counter wrapping (~49 days).
- `components/bt/bonds` — persistent bond table in the spare flash region,
  reusing the tape header's append-only ping-pong log: 8 bonds, ordered
  most-recently-used first (which is the order power-up tries them),
  least-recently-used eviction when full, and crash-safe commits.
- Host tests: a power-yank sweep over the bond log proves an established
  bond survives a cable pull during a new pairing, the new bond either
  lands completely or not at all, and the table is still usable
  afterwards. 10 suites, ~60,000 assertions, green in ~1.9 s.

### Added (2026-08-25, firmware M5 — factory test harness)

- `components/factory` — the harness that gets 20 hand-built boards
  checked identically: sequences probes, aggregates results, and emits an
  operator table plus a one-line machine record
  (`FT|1|flash_id=PASS:0xEF4018|...|VERDICT=PASS`) so the jig's serial log
  becomes the build record for the run.
- Design properties, all host-tested with mock probes: every step runs even
  after one fails (a board with three faults reports three, not one per
  reflash); each result carries a measured value, not just a verdict;
  skips never fail a board; interactive steps are skipped automatically on
  unattended runs; both report formats truncate safely at every buffer size
  (swept 1..200 bytes).
- `main/factory_main.c` — board-side probes and the runner, built with
  `idf.py -DMIXXTAPE_FACTORY_TEST=ON`. Tab sense, button walk and the SPI
  JEDEC ID read are written; mic, LED walk, CC sense, flash read/write and
  BT inquiry are stubs reporting SKIP until the M4 drivers exist. The
  runner prints `SUITE INCOMPLETE` rather than a pass banner while any
  probe is unimplemented — a green light nobody earned is worse than none.
- 8 host suites, ~59,000 assertions, green in ~1.6 s.

### Added (2026-08-25, firmware — playback and the reel display)

- `components/tape/tape_player` — the tape-side sequencer. PLAY runs every
  recorded track in order as one side, skipping empty slots rather than
  playing silence; pause/resume, track skip with wrap, and position
  measured across the whole side (which is what the reels show). Pull-based
  so the A2DP callback, which must never block, only ever copies out of a
  ring a prefetch task fills.
- `components/leds/reels` — the reel display as a pure function of (mode,
  progress, level, clock). Left ring empties while the right fills; red
  pulse riding the input level while recording; amber sweep hunting for a
  sink; green lock; dim reverse spin during background erase; violet while
  dubbing; slow red pulse when the sink is busy.
- Host tests: `test_tape_player` (side sequencing verified sample-exact
  against independently decoded audio, empty-slot skipping, pause/resume,
  skip wrap, monotonic position, playback after remount) and `test_reels`.
  7 suites, ~58,000 assertions, green in ~1.3 s.

### Verified (2026-08-25)

- **LED power budget holds.** `test_reels` sweeps every mode across time at
  worst-case inputs and measures the frame: **119 mA worst case** at the
  default 500 mA-source brightness cap, 227 mA at the 1.5 A cap — against a
  200 mA slice of the USB budget (the ESP32 alone bursts to ~240 mA on BT
  transmit). No mode ever renders all-white. The constraint is now enforced
  by a test rather than by hoping.
- Reel conservation: the two rings together always hold the same amount of
  "tape" across a whole side, to within integer rounding.

### Changed (2026-08-25, firmware M3 — stored format is ADPCM, not SBC)

- **ESP-IDF's A2DP source accepts PCM only.** `esp_a2d_source_data_cb_t` is
  handed a "buffer to be filled with PCM data stream"; Bluedroid encodes SBC
  internally and exposes no API for pre-encoded frames. The brief's
  "playback is read-frames-and-transmit" is therefore unbuildable as
  written — storing SBC would mean decoding it back to PCM at playback just
  so the stack could re-encode it.
- **Tape now stores block-framed IMA ADPCM.** 512-byte blocks: 4-byte header
  (predictor, step index, payload checksum) + 508 B of nibbles = 1016
  samples = 23.04 ms, 22,223 B/s. Playback is read-block → table-lookup
  decode → PCM to Bluedroid, which is far cheaper than SBC decode and keeps
  the spirit of the locked "no DSP at playback" decision.
- Blocks are self-contained, so **seeking is free** — track skip,
  pause/resume and the reel position display all depend on it.
- **Slot size 5 MiB → 5.125 MiB** (82 erase blocks) to preserve the full
  four-minute take at ADPCM's higher bitrate. Flagged deviation from the
  locked "3 x 5 MB slots"; keeps that decision's substance (three fixed
  slots, no dynamic allocation) and the 4-minute promise. 576 KiB spare.
- Retires M6 risk #1 (SBC-encode-while-capturing timing) — we no longer
  encode SBC at all.
- Crash recovery now validates a **payload checksum** per block. Without it
  a torn write whose header landed but whose data was cut short was
  wrongly accepted, keeping 23 ms of noise — a real bug the yank sweep
  caught once the format changed.
- Host tests: added `test_adpcm_block` (block geometry, capacity,
  independent decodability, truncation rejection). 5 suites, ~4,100
  assertions, green.

### Added (2026-08-25, firmware Phase A — M0/M1/M2)

- `firmware/` — ESP-IDF project skeleton: pin map (`main/include/board.h`),
  `sdkconfig.defaults` (Classic BT + A2DP source, BLE off, BR/EDR-only
  controller), component/CMake wiring, and a UI-bring-up `app_main`.
- `firmware/components/tape` — crash-safe slot manager behind an abstract
  `flash_hal.h`: append-only ping-pong header log (64-byte records, CRC32 +
  generation counter), just-in-time erase ahead of the write pointer, and
  mount-time repair of a slot left mid-recording.
- `firmware/components/ui` — button grammar and device state machine
  (REC hold, PLAY short/long, TRACK cycle, MODE 2/5/10 s), pure logic.
- `firmware/test/host` — NOR flash mock that models erase/program bit
  semantics and tears any chosen operation, plus a **power-yank sweep**
  that tears every flash operation of a recording in turn and re-checks the
  invariants. 4 suites, ~2,300 assertions, all passing in <1 s.
- `.github/workflows/firmware.yml` — CI: host tests via ctest, plus an
  ESP-IDF v5.3 container build.
- `docs/storage-budget.md` — the M1 arithmetic.

### Changed / findings (2026-08-25, firmware)

- **Record pipeline changed to one-pass SBC — needs Steven's sign-off.**
  The brief's two-pass pipeline needs a 5.05 MiB ADPCM scratch region, but
  three 5 MiB slots plus a header leave only 960 KiB — a 4.11 MiB deficit,
  i.e. 44 seconds of scratch instead of 4 minutes. Encoding SBC directly at
  capture removes the scratch entirely, honours the LOCKED "3 x 5 MiB slots"
  layout exactly, raises the affordable bitpool from 18 to 26 (121 -> 165
  kbps), halves flash writes, removes the post-record wait, and makes a
  power yank *keep* the partial take. Only loss is whole-take peak
  normalisation, replaced by a look-ahead limiter. ADPCM is implemented and
  tested regardless. See `docs/storage-budget.md` §4.
- Slot-repair scanning is a linear forward scan, not a binary search: a torn
  erase leaves a half-erased block whose tail still holds the previous take,
  so the slot is not monotonic and a binary search could resurrect stale
  audio. Caught by the block-crossing yank sweep.
- `tape_store_erase_slot` disowns a slot's audio *before* erasing it, so a
  yank mid-erase cannot leave the header claiming playable audio over
  half-erased flash.
- Storage-budget table corrected to whole-frame sizes (4:00 at bitpool 26 is
  4,961,220 B, not the fractional 4,961,250) — caught by `test_sbc_frame`.

### Added (2026-08-25, prior art research)

- `docs/prior-art.md` — eleven cassette-form-factor projects researched:
  Mixtape Alpha and 8Bit Mix Tape (direct ancestors), plus Mixxtape (Mixxim),
  the Larry Schotz car cassette adapter, 8BitMixtape NEO, JamHamster's ZX
  Spectrum cassette, the Cassette Pi IoT scroller, the **Digisette Duo-Aria
  (2000)** — the only known cassette-shaped device with record + playback,
  incl. deck playback via edge transducer, predating the Mixxim patent —
  the ION Bluetooth cassette adapter (mic inside the shell), Milktape /
  Suck UK USB mixtapes, and NFC mixtape tokens. Per-project takeaways and
  cross-cutting patterns.

### Added (2026-08-25, KiCad project setup)

- KiCad 9 project in `hardware/` (`mixxtape.kicad_pro`, `mixxtape.kicad_sch`,
  lib tables) with first-pass schematic: USB-C + ESD + CH340N, AMS1117 power,
  ESP32-WROOM-32E wired per the brief's GPIO map, I²S mic, W25Q128 flash,
  4 buttons, write-protect tab, castellated header, 29-LED WS2812 chain,
  and the DNP battery section. ERC passes with 0 errors.
- Symbols/footprints/3D models for all BOM parts fetched from JLCPCB/EasyEDA
  into `hardware/parts/mixxtape_parts.*` via `hardware/parts/fetch_parts.py`
  (uses curl_cffi Chrome TLS impersonation — EasyEDA's API blocks plain
  clients, and rate-limits bursts).
- Hand-authored `mixxtape_local.kicad_sym` (break-off tab, castellated
  header, JST connector symbols).
- `hardware/scripts/gen_schematic.py` — one-shot generator that produced the
  initial schematic (do not re-run after hand-editing in KiCad).

### Changed / findings (2026-08-25)

- **WS2812B-2020 substituted:** genuine Worldsemi part (C965555) is EOL at
  JLC (stock 3). Fitted part is XINGLIGHT XL-2020RGBC-2812B (**C5349955**,
  ~$0.06 @ 500, 180k stock) — same protocol and land pattern; schematic uses
  the WS2812B-2020 symbol/footprint with LCSC field C5349955.
- **CH340N has no DTR** (RTS# only) — the BOM's S8050 auto-reset pair needs
  both signals. Schematic fits a cap-coupled RTS reset instead; Q1/Q2 omitted
  until Steven decides (alternative: CH340C/CH343). Flagged on the schematic.
- LDO uprated to 1 A as the BOM required: AMS1117-3.3 (C6186), SOT-223.
- **USB-C is now power-only; programming moves to a jig (Steven,
  2026-08-25):** CH340N, USBLC6 ESD, and their caps removed; USB data pins
  NC. The castellated hacker header is removed. New J5: six bare pogo pads
  (3V3, GND, EN, IO0, TX, RX) — the jig carries the USB-UART bridge and
  auto-program transistors. Saves ~$0.60/board and the castellated-edge
  surcharge; resolves the CH340N-has-no-DTR question by removing it.
- **USB-C CC sensing added (2026-08-25):** CC1/CC2 wired through 10 k
  (R10/R11) to ADC1 on GPIO36/39 so firmware can read the source's current
  advertisement and raise the LED brightness cap on 1.5 A/3 A supplies.
  Extra resistors alone cannot unlock more current — the source advertises,
  the sink measures.
- **Firmware framework locked: ESP-IDF (Steven, 2026-08-25).** Zephyr was
  considered and rejected — BLE-first stack, partial BR/EDR host, upstream
  deprecation proposal for Classic BT, and no supported A2DP path on ESP32;
  Bluedroid (ESP-IDF) has the proven A2DP source + SBC encoder.
- **Name change planned (Steven, 2026-08-25):** "mixxtape" collides with
  Mixxim's commercial product name; will be renamed before going public.
- `docs/firmware-plan.md` — firmware architecture and milestone plan for
  agent handoff: task layout, two-pass record pipeline, yank-safety rules,
  no-devkit de-risking order (host-tested core + early 2–3 board prototype
  as the bring-up vehicle), factory-test firmware, CC-sense power logic.
  Flags a storage-budget conflict (4-min ADPCM scratch ≈ 5.3 MB vs ~1 MB
  spare) to resolve on paper first.
- **MicroSD footprint added, DNP (Steven, 2026-08-25):** TF-01A push-push
  socket (**C91145**, ~$0.13 @ 500) as J4, the "studio edition" option for
  loading songs. SPI-mode wiring sharing VSPI with the audio flash:
  CS = IO22 (with DNP 10 k pullup R9 so a populated card stays deselected
  during flash access), card-detect = IO32 (needs internal pullup in
  firmware), DAT1/DAT2 unused. Default build unchanged — footprint only.
- **LED level shifter added (Steven, 2026-08-25):** XL-2020RGBC-2812B
  confirmed working from Steven's past projects, including at 3.3 V data —
  but a TI SN74AHCT1G125 (**C7484**, SOT-23-5, ~$0.08) is fitted anyway as
  U8: ESP32 IO27 (`LED_DATA`) → buffer → `LED_DATA_5V` → D1, OE̅ tied to GND,
  powered from VBUS.

### Added

- Project write-up covering concept, rationale, and open design questions
  (`docs/cassette-project-writeup.md`)
- Agent handoff brief with locked decisions, GPIO map, behaviour spec, and
  suggested phase order (`docs/cassette-recorder-agent-brief.md`)
- Bill of materials v3 with LCSC part numbers and qty-20 costing
  (`docs/cassette-recorder-bom-v3.md`)
- Empty `firmware/` and `hardware/` directory placeholders
- README, changelog, and AGENTS.md

### Design decisions (as of 2026-08-25)

- MCU locked to ESP32-WROOM-32E for Classic Bluetooth / A2DP source
- USB-C only power; battery circuit on board but unpopulated
- 29 × WS2812B-2020 indicators replacing earlier charlieplex approach
- LDO to be uprated from 500 mA to 1 A (part selection pending)
- Write-protect tab count (one vs three) still open

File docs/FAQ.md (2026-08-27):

# Frequently asked questions

> **Draft.** No hardware exists yet, so answers marked *(unverified)* are
> design intent waiting on the first prototype boards. Where something is
> genuinely not known, this says so rather than guessing.

See also: [the manual](MANUAL.md).

---

## The basics

### What is it?

A circuit board shaped exactly like a cassette, with a microphone on it.
Hold REC to record, pair it to Bluetooth earbuds or a speaker, press PLAY.
Three tracks, about four minutes each.

### Does it play in a real tape deck?

**No.** It is cassette-shaped, but there is no tape head. Put it in a deck
and nothing happens.

This is deliberate rather than an oversight. Making a cassette-shaped
device that plays through a real deck is covered by a patent held by
Mixxim, who make the Mixxtape player. We are not going anywhere near that
without a lawyer reading it first, and it is not what this device is for
anyway.

### So it is another cassette Bluetooth player?

No — and this is the whole reason the project exists. There are perhaps
ten cassette-shaped Bluetooth *players*. You sideload files onto them.

Nobody ships a cassette-shaped **recorder**, and recording is the part
that made a mixtape a mixtape. You made it, it was yours, you gave it to
someone.

We looked. In [eleven cassette-form-factor projects](prior-art.md) going
back to the 1980s, exactly one device ever recorded — the Digisette
Duo-Aria in 2000, and only as a dictaphone feature. Record-as-the-point
is still an empty niche.

### Can I put my own music on it?

**No.** There is no way to load audio files onto it, by design.

It records what is in front of the microphone. If you want to put an
album on a cassette-shaped object, the Mixxtape player already does that
well.

### Can I get my recordings off it, onto a computer?

Not in the default build. There is no USB data connection — USB-C carries
power only.

This is a real limitation and we know it. It exists because dropping the
USB data path removed a chip, saved board space, and closed off a whole
class of "why won't my computer see it" problems. The recordings are meant
to live on the tape and be given away with it.

If you want this, the board has an unpopulated microSD footprint. See
[Building your own](#building-your-own).

---

## Recording

### How long can I record?

About four minutes per track, three tracks, so roughly twelve minutes in
total.

That is not a compromise we are embarrassed about. A mixtape that holds
everything is a hard drive.

### Can I record over a track?

Yes — that is the only way it works. Holding REC always records over the
current track from the beginning. There is no append, and no delete
function, because **recording is erasing**, exactly like tape.

### Can I record more than one thing onto a single track?

No. Each hold of REC is one take, and it replaces the whole track.

### How good does it sound?

Mono, 44.1 kHz, from a single small microphone. Think good voice memo
rather than field recording.

*(Unverified.)* The genuine open question is handling noise: it is a
microphone on a bare circuit board, so fingernails and board flex go
straight into the recording. We have designed around it — relief slots
near the mic, placement away from where you naturally grip — but nobody
knows how well that works until a board exists. It is the project's
biggest technical risk and we are not going to pretend otherwise.

### Do I need to set a recording level?

No. There is no gain control. It watches the room continuously — lifting
quiet material so ambience is audible, and catching sudden loud sounds
before they distort. The REC lamp brightness follows the input so you can
see it working.

### What happens if the power is pulled mid-recording?

**You keep what was recorded.** The take is simply shorter. Nothing else
on the tape is affected, and the tape is immediately usable again.

This is not a happy accident. There is no battery, so pulling the cable is
the normal way of switching off, and the storage layer was built around
that from the start. Every single flash operation of a recording has been
tested by simulating a power cut at exactly that moment and checking that
existing recordings are still byte-identical afterwards.

### Can I record while it is playing?

No. Pressing REC stops playback and starts recording.

---

## The write-protect tab

### What does the tab do?

The same thing the plastic tab on a real cassette did. Snap it off and the
tape can never record again.

### Is it really permanent?

**Yes.** It is a trace on a break-off piece of the board. Once it is
snapped, the connection is gone, and the firmware refuses to record.
There is no reset, no button combination, and no way for us to undo it.

### Why would I want that?

Because it is what makes handing someone a tape into a thing that
happened. You record it, you write the label on the front, you snap the
tab, and you give it away. The last step is physical and irreversible.

A file you send someone is a copy. This is the object.

### Can I still play it after snapping the tab?

Yes. Playback, pairing and everything else work exactly as before. Only
recording is disabled.

### One tab for the whole tape, or one per track?

One for the whole tape. Three would be more useful; one is more faithful,
and matches what a cassette actually did. *(Still open — Steven has not
finally decided.)*

---

## Bluetooth and pairing

### What can I pair it with?

Ordinary Bluetooth earbuds and speakers — anything a phone pairs with for
music. It behaves like a phone, not like an accessory: it is the thing
sending the audio.

### Will it work with AirPods?

It should — AirPods are a standard Bluetooth audio sink. *(Unverified.
Apple devices are notoriously particular about pairing, and testing
against a range of real earbuds is explicitly on the list before any
boards are built in quantity.)*

### How do I choose which speaker to use?

You hold the tape against it. That is the entire interface.

When you hold MODE for two seconds it looks around, ignores everything
that is not a speaker or headphones — phones, laptops, watches, keyboards
— and picks the closest one. There is no list and no app.

### It keeps failing to connect and pulsing red slowly.

The speaker is almost certainly still connected to someone's phone.
Bluetooth audio devices talk to one thing at a time. Disconnect it at the
other end and try again.

The slow red pulse means exactly that, rather than a general failure. We
would rather tell you what is wrong than blink hopefully.

### Does it remember what I paired with?

Yes — up to eight devices, most recently used first. Plug it in and it
reconnects to the last one on its own. Those are stored in flash and
survive the cable being pulled.

### Why Bluetooth Classic and not the newer low-energy audio?

Because ordinary earbuds do not support the newer standard yet. LE Audio
would be a better fit technically, but Apple does not support it, so a
large fraction of people simply could not use the thing.

That decision drove the whole design: Classic Bluetooth is why this uses
the original ESP32 rather than a newer, smaller, cheaper one. Every newer
ESP32 is low-energy only.

---

## Power

### Why is there no battery?

Because a cassette should still work when you find it in a box years
later. A lithium cell left in a drawer for eight years is dead, and
sometimes swollen. Building that into an object whose entire premise is
"it still works when rediscovered" would be self-defeating.

It also avoids the shipping paperwork that lithium cells drag along.

### So I need to keep it plugged in?

Yes. A small power bank in a pocket, with the tape on a cable, is more or
less a Walkman.

### Can I add a battery myself?

Not without redesigning the power supply. The board used to carry an
unpopulated charger, but it was removed once it became clear it could never
have worked: the 3.3 V rail comes from an AMS1117, which needs 1.1-1.3 V of
headroom, and a lithium cell only ever reaches 4.2 V falling to 3.0 V. The
LEDs run from the 5 V USB rail as well. Running on a cell means a different
regulator and a different LED rail — a real redesign, not a part you add.

### Will any USB charger work?

Yes. If it is plugged into a supply that can give more current, it notices
and runs the lights brighter — otherwise it stays inside what a basic USB
port can provide.

---

## The object

### Is it safe to hold a bare circuit board?

Yes. There is nothing on it above 5 volts and nothing that gets hot.

The bare board is the point, not a cost saving. It descends from Open
Music Labs' Mixtape Alpha, whose stated goal was getting people
comfortable touching electronics and changing expectations about what
electronics should look like. We took that wholesale.

Static is the usual way to damage a bare board — touch something earthed
first in a very dry room. In normal conditions, do not think about it.

### Why is the board white?

So you can write on it. Ordinary green circuit boards are glossy and
reject permanent marker — it beads up and thumbs off. Matte white takes
it and keeps it, and there are faint ruled lines where a cassette's paper
label used to go.

### Does it come with a case?

Yes, an ordinary cassette case, mostly bought secondhand. The case is not
packaging; it is what makes it read as a cassette when you hand it over.

### What are all the lights for?

Twelve around each reel window. As a track plays the left ring empties and
the right ring fills — tape moving from one reel to the other. It is a
position indicator nobody has to learn.

They also show recording level, pairing progress, and the background
tidying-up that happens before a track can be recorded over.

---

## Building your own

### Is it open source?

Yes. Schematic, board files, firmware and the design notes are all public,
including the arguments that changed our minds along the way.

### Can I build one?

Yes. It is a two-layer board with parts on one side, priced at roughly $13
each in a batch of twenty. The repository has the bill of materials with
part numbers.

### What is the unpopulated microSD slot for?

A "studio edition" variant. The footprint is there, wired up and not
fitted, so anyone who wants removable storage can add it without
redesigning the board.

We left it off the default build on purpose. An SD card you load songs
onto turns this back into the cassette-shaped player that already exists,
and it weakens the tape metaphor — the write-protect tab means much less
when the media pops out.

### Can I write my own firmware for it?

Yes. There is no USB data connection, so firmware goes on through six pads
along the board edge with a jig. The repository explains it. The audio
storage, the playback sequencer, the reel display and the pairing logic
are all portable C with tests you can run on a PC without any hardware.

### What is it called?

Undecided. The repository is currently named after an existing commercial
product, which is a problem we intend to fix before this goes anywhere
public. Suggestions welcome.

---

## Honest limitations

Collected in one place, because they are easier to trust than to discover:

- **No way to get recordings onto a computer** in the default build.
- **Twelve minutes total**, and each track is all-or-nothing.
- **Mono**, from one small microphone.
- **Handling noise is an open risk** — a bare board with a mic on it is
  not the quietest thing to hold. *(Unverified until prototypes exist.)*
- **It needs to stay plugged in.**
- **It does not play in a tape deck**, and will not.
- **Reconnect time is unknown.** *(If it turns out to take eight seconds
  to reconnect on power-up, the whole interaction needs rethinking, and we
  will say so.)*

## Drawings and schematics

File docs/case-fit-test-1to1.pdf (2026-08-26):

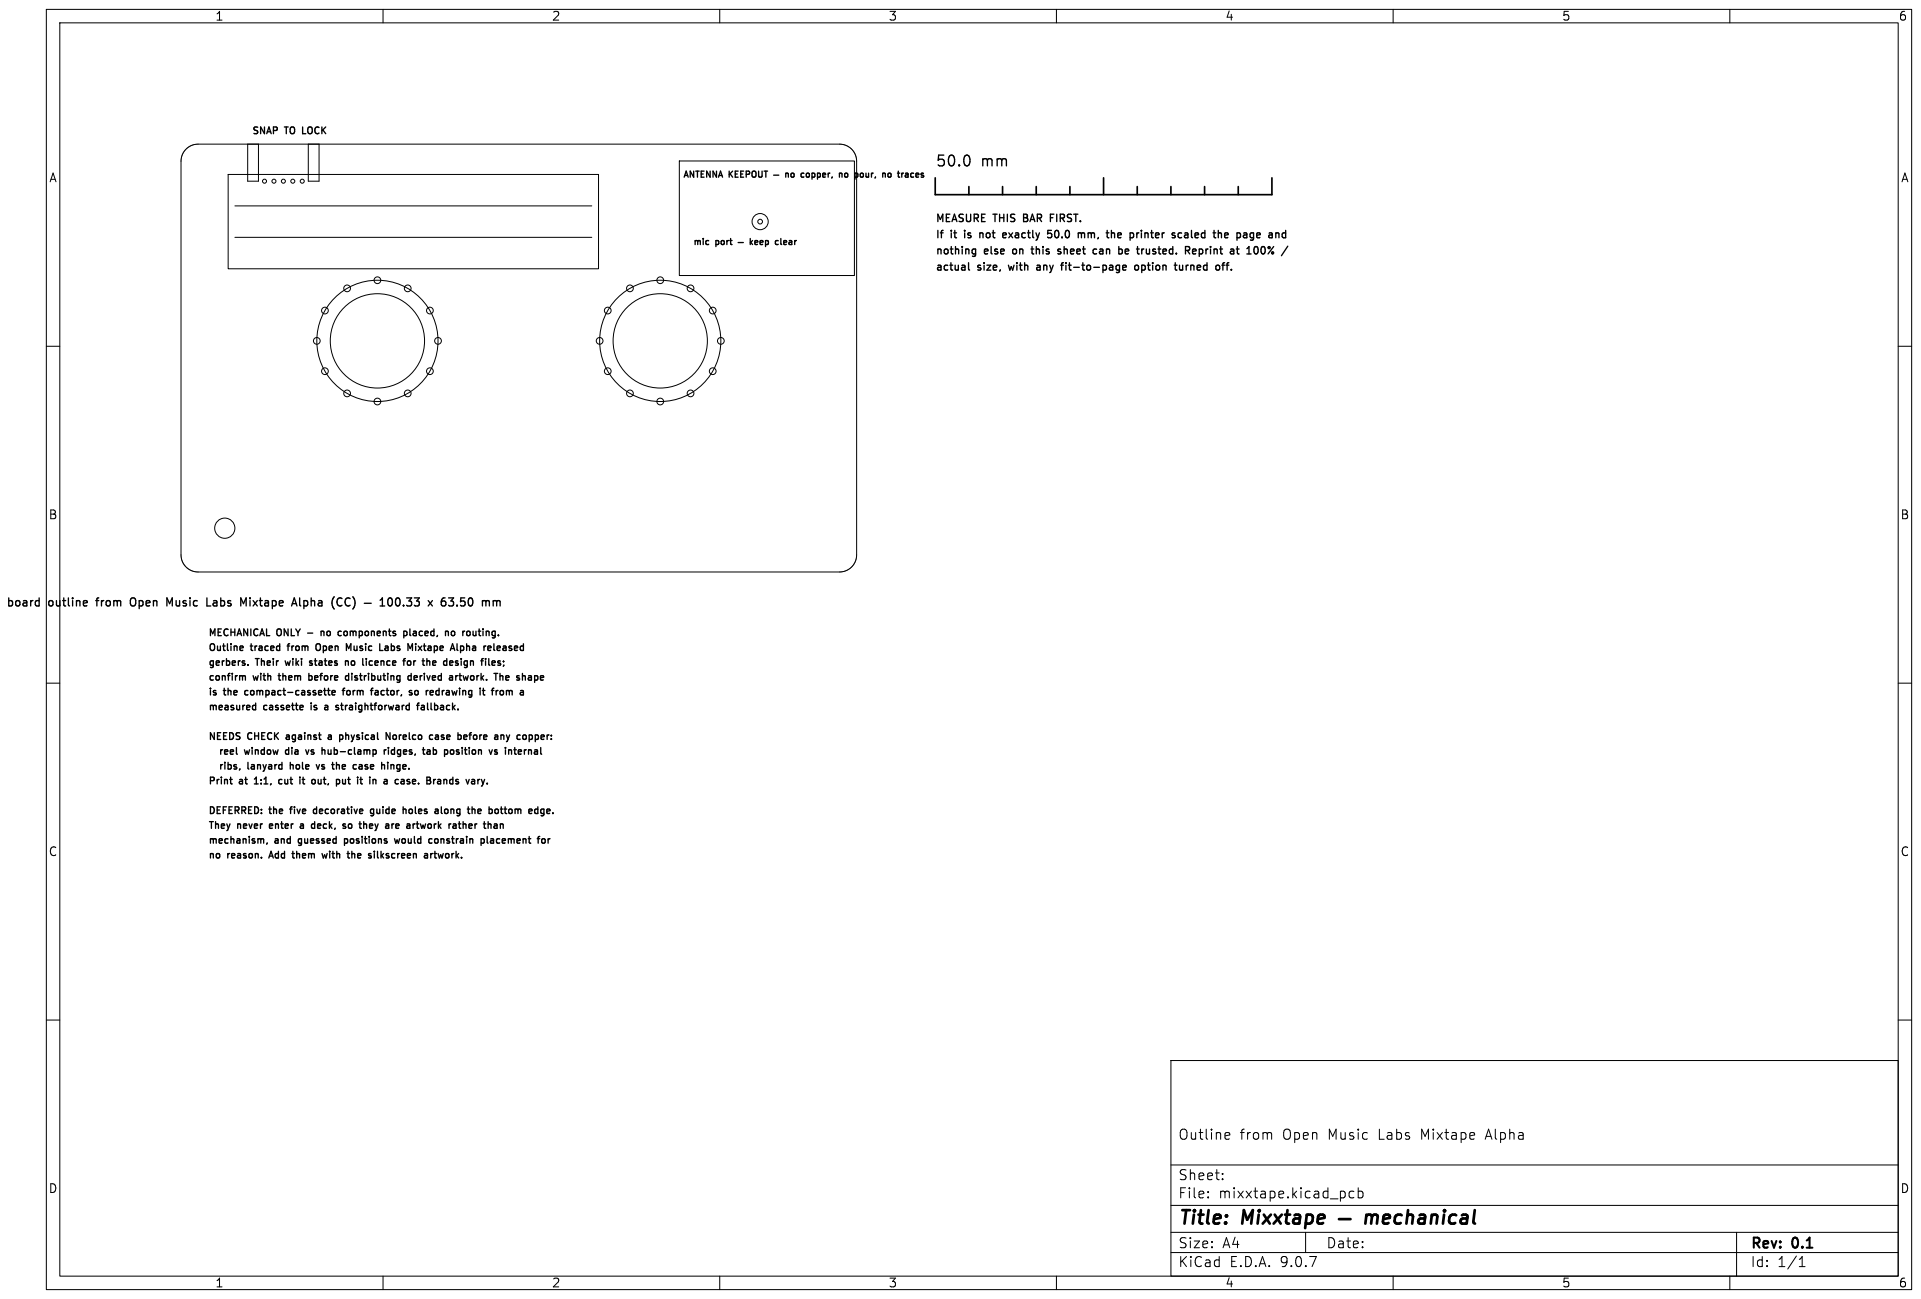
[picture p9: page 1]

MEASURE THIS BAR FIRST.

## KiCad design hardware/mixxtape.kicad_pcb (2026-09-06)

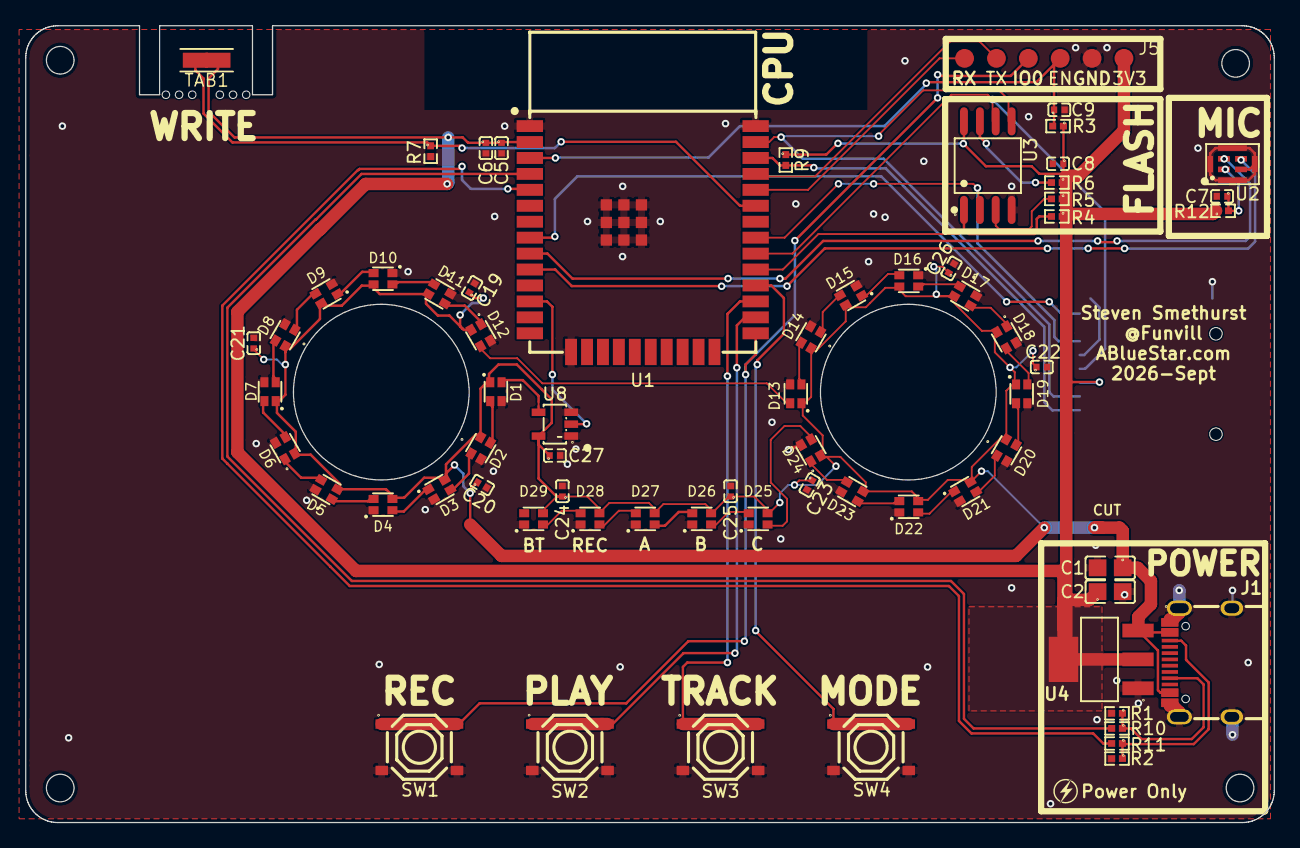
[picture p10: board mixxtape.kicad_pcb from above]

Board: 2 copper layers, 99.5 x 63.5 mm, 70 parts (1 on the bottom side), 56 nets.

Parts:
C1, C2: 10uF; C0805
C5, C6, C7, C8, C19, C20, C21, C22, C23, C24, C25, C26, C27: C0402
C9: 1uF; C0402
D1, D2, D3, D4, D5, D6, D7, D8, D9, D10, D11, D12, D13, D14, D15, D16, D17, D18, D19, D20, D21, D22, D23, D24, D25, D26, D27, D28, D29: XL-1615RGBC-2812B; LED-SMD_4P-L1.6-W1.5_XL-1615RGBC-2812B
J1: USB-C_SMD-TYPE-C-31-M-12_1
J4: TF-SMD_TF-01A
J5: PROG_JIG; PROG_JIG_6PAD
MB1: MOUSEBITE_6
R1, R2: R0402
R3, R4, R5, R6, R7, R9, R10, R11: R0603; R0402
R12: 100R; R0402
SW1, SW2, SW3, SW4: SW-SMD_4P-L5.1-W5.1-P3.70-LS6.5-TL_H1.5
TAB1: WRITE-PROTECT; TAB_BREAKOFF_LINK
U1: WIFI-SMD_ESP32-WROOM-32E
U2: LGA-8_L4.0-W3.0-R_WMM7040DT0
U3: SOIC-8_L5.3-W5.3-P1.27-LS8.0-BL
U4: SOT-223-3_L6.5-W3.4-P2.30-LS7.0-BR
U8: SOT-23-5_L3.0-W1.7-P0.95-LS2.8-BR

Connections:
3V3: C2.1, C5.1, C6.1, C8.1, J4.4, J5.1, R3.1, R4.1, R5.1, R6.1, R9.1, R12.1, TAB1.1, U1.2, U3.8, U4.2, U4.4
BTN_MODE: SW4.1, SW4.2, U1.28
BTN_PLAY: SW2.1, SW2.2, U1.26
BTN_REC: J5.4, SW1.1, SW1.2, U1.25
BTN_TRACK: SW3.1, SW3.2, U1.27
CC1: J1.A5, R1.1, R10.1
CC1_SENSE: R10.2, U1.4
CC2: J1.B5, R2.1, R11.1
CC2_SENSE: R11.2, U1.5
EN: C9.1, J5.3, R3.2, U1.3
FLASH_HOLD_N: R6.2, U3.7
FLASH_WP_N: R5.2, U3.3
GND: C1.2, C2.2, C5.2, C6.2, C7.2, C8.2, C9.2, C19.2, C20.2, C21.2, C22.2, C23.2, C24.2, C25.2, C26.2, C27.2, D1.1, D2.1, D3.1, D4.1, D5.1, D6.1, D7.1, D8.1, D9.1, D10.1, D11.1, D12.1, D13.1, D14.1, D15.1, D16.1, D17.1, D18.1, D19.1, D20.1, D21.1, D22.1, D23.1, D24.1, D25.1, D26.1, D27.1, D28.1, D29.1, J1.1, J1.2, J1.3, J1.4, J1.A1B12, J1.B1A12, J4.6, J4.10, J4.11, J4.12, J4.13, J5.2, R1.2, R2.2, R7.2, SW1.3, SW1.4, SW2.3, SW2.4, SW3.3, SW3.4, SW4.3, SW4.4, U1.1, U1.15, U1.38, U1.39, U2.2, U2.5, U2.6, U2.7, U2.8, U3.4, U4.1, U8.1, U8.3
LD1: D1.4, D2.2
LD2: D2.4, D3.2
LD3: D3.4, D4.2
LD4: D4.4, D5.2
LD5: D5.4, D6.2
LD6: D6.4, D7.2
LD7: D7.4, D8.2
LD8: D8.4, D9.2
LD9: D9.4, D10.2
LD10: D10.4, D11.2
LD11: D11.4, D12.2
LD12: D12.4, D13.2
LD13: D13.4, D14.2
LD14: D14.4, D15.2
LD15: D15.4, D16.2
LD16: D16.4, D17.2
LD17: D17.4, D18.2
LD18: D18.4, D19.2
LD19: D19.4, D20.2
LD20: D20.4, D21.2
LD21: D21.4, D22.2
LD22: D22.4, D23.2
LD23: D23.4, D24.2
LD24: D24.4, D25.2
LD25: D25.4, D26.2
LD26: D26.4, D27.2
LD27: D27.4, D28.2
LD28: D28.4, D29.2
LED_DATA: U1.12, U8.2
LED_DATA_5V: D1.2, U8.4
MIC_VDD: C7.1, R12.2, U2.1
PDM_CLK: U1.10, U2.3
PDM_DATA: U1.9, U2.4
SD_CS_N: J4.2, R9.2, U1.36
SD_DETECT: J4.9, U1.8
SPI_CLK: J4.5, U1.30, U3.6
SPI_CS_N: R4.2, U1.29, U3.1
SPI_MISO: J4.7, U1.31, U3.2
SPI_MOSI: J4.3, U1.37, U3.5
TAB_SENSE: R7.1, TAB1.2, U1.33
UART_RX: J5.6, U1.34
UART_TX: J5.5, U1.35
VBUS: C1.1, C19.1, C20.1, C21.1, C22.1, C23.1, C24.1, C25.1, C26.1, C27.1, D1.3, D2.3, D3.3, D4.3, D5.3, D6.3, D7.3, D8.3, D9.3, D10.3, D11.3, D12.3, D13.3, D14.3, D15.3, D16.3, D17.3, D18.3, D19.3, D20.3, D21.3, D22.3, D23.3, D24.3, D25.3, D26.3, D27.3, D28.3, D29.3, J1.A4B9, J1.B4A9, U4.3, U8.5

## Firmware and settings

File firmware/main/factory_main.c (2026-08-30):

/* Factory test runner (plan milestone M5).
 *
 * Twenty boards get built by hand. This is what the jig runs on each one
 * before production firmware goes on: probe every subsystem, print one
 * greppable line, move to the next board.
 *
 *   idf.py -DMIXXTAPE_FACTORY_TEST=ON build flash monitor
 *
 * Log the jig's serial output to a file and that file is the build record
 * for the run — one `FT|1|...` line per board, with measured values, so a
 * board that comes back flaky later can be looked up rather than guessed
 * about.
 *
 * ── Status ────────────────────────────────────────────────────────────
 * The harness (components/factory) is host-tested. The probes below are
 * NOT — there is no board yet, and no ESP-IDF install here to compile
 * against. Treat this file as the bring-up checklist it is: probes that
 * depend on drivers M4 still has to write report SKIP with a "TODO M4"
 * detail, and the runner refuses to print a clean PASS banner while any
 * of them remain. Fill them in as each driver lands.
 */

#ifdef MIXXTAPE_FACTORY_TEST

#include <stdio.h>
#include <string.h>

#include "board.h"
#include "driver/gpio.h"
#include "driver/spi_master.h"
#include "esp_attr.h"   /* WORD_ALIGNED_ATTR */
#include "esp_log.h"
#include "esp_timer.h"
#include "factory_test.h"
#include "freertos/FreeRTOS.h"
#include "freertos/task.h"
#include "tape_layout.h"

static const char *TAG = "factory";

/* Either 128 Mbit part may be fitted. Type 0x40 and capacity 0x18 (16 MiB)
 * are common to both; only the manufacturer byte differs. */
#define JEDEC_WINBOND_W25Q128     0xEF4018 /* Winbond */
#define JEDEC_GIGADEVICE_GD25Q128 0xC84018 /* GigaDevice */

typedef struct {
    spi_device_handle_t flash;
    bool flash_ready;
} probe_ctx_t;

static uint32_t now_ms(void)
{
    return (uint32_t)(esp_timer_get_time() / 1000);
}

/* --- flash ----------------------------------------------------------- */

static int probe_flash_id(void *user, int32_t *measured, char *detail)
{
    probe_ctx_t *ctx = (probe_ctx_t *)user;
    if (!ctx->flash_ready) {
        snprintf(detail, FT_DETAIL_LEN, "spi bus not up");
        return -1;
    }
    uint8_t rx[3] = {0};
    spi_transaction_t t = {
        .cmd = 0,
        .addr = 0,
        .length = 8 * 4,
        .rxlength = 8 * 4,
        .flags = 0,
    };
    /* Word-aligned because DMA is enabled on this bus (SPI_DMA_CH_AUTO
     * below). ESP-IDF does not REJECT a misaligned buffer - it silently
     * allocates an aligned bounce buffer and memcpys, so the unaligned
     * version worked. (An earlier comment here claimed it would fail; that
     * was wrong.) Aligning simply saves two heap allocations per call on
     * the first thing that runs on a new board, which is a good place not
     * to depend on the heap. */
    static WORD_ALIGNED_ATTR uint8_t tx[4];
    static WORD_ALIGNED_ATTR uint8_t buf[4];
    tx[0] = 0x9Fu; tx[1] = tx[2] = tx[3] = 0; /* Read JEDEC ID */
    buf[0] = buf[1] = buf[2] = buf[3] = 0;
    t.tx_buffer = tx;
    t.rx_buffer = buf;

    if (spi_device_polling_transmit(ctx->flash, &t) != ESP_OK) {
        snprintf(detail, FT_DETAIL_LEN, "spi transfer failed");
        return -1;
    }
    rx[0] = buf[1];
    rx[1] = buf[2];
    rx[2] = buf[3];

    int32_t id = ((int32_t)rx[0] << 16) | ((int32_t)rx[1] << 8) | rx[2];
    *measured = id;

    if (id == 0 || id == 0xFFFFFF) {
        snprintf(detail, FT_DETAIL_LEN, "no flash responding");
        return -1;
    }
    if (id != JEDEC_WINBOND_W25Q128 && id != JEDEC_GIGADEVICE_GD25Q128) {
        snprintf(detail, FT_DETAIL_LEN, "wrong part, expected 0x%X or 0x%X",
                 JEDEC_WINBOND_W25Q128, JEDEC_GIGADEVICE_GD25Q128);
        return -1;
    }
    return 0;
}

static int probe_flash_rw(void *user, int32_t *measured, char *detail)
{
    (void)user;
    *measured = 0;
    /* Exercises the spare region only — never a slot, so running the
     * factory test can never eat a recording. Needs the SPI flash HAL. */
    snprintf(detail, FT_DETAIL_LEN, "TODO M4: needs flash HAL");
    return 1;
}

/* --- microphone ------------------------------------------------------ */

static int probe_mic(void *user, int32_t *measured, char *detail)
{
    (void)user;
    *measured = 0;
    /* Capture ~100 ms via I2S PDM RX at a 2.8224 MHz clock, compute RMS,
     * and require it to be neither stuck at zero (dead mic or dead clock)
     * nor pinned at the rail. The pass window has to be set against real
     * boards in a quiet room. */
    snprintf(detail, FT_DETAIL_LEN, "TODO M4: needs PDM capture");
    return 1;
}

/* --- write-protect tab ----------------------------------------------- */

static int probe_tab(void *user, int32_t *measured, char *detail)
{
    (void)user;
    int level = gpio_get_level(PIN_TAB_SENSE);
    *measured = level;

    /* A board fresh off the line has its tab intact, so this reads high.
     * Reading low means the trace is broken, the pull-down is wrong, or
     * someone has already snapped the tab. */
    if (level != 1) {
        snprintf(detail, FT_DETAIL_LEN, "tab reads snapped");
        return -1;
    }
    return 0;
}

/* --- USB-C CC sense --------------------------------------------------- */

static int probe_cc(void *user, int32_t *measured, char *detail)
{
    (void)user;
    *measured = 0;
    /* Read CC1 and CC2 on ADC1 and take the higher: one line is the live
     * one, the other sits near ground. A plausible reading proves the CC
     * pull-downs and the divider are fitted. */
    snprintf(detail, FT_DETAIL_LEN, "TODO M4: needs ADC oneshot");
    return 1;
}

/* --- radio ------------------------------------------------------------ */

static int probe_bt(void *user, int32_t *measured, char *detail)
{
    (void)user;
    *measured = 0;
    /* Bring up the controller and Bluedroid, run a short inquiry, and
     * report how many devices answered. Any non-zero count proves the
     * radio transmits and receives and the antenna keepout is sane —
     * which is the single most important thing to know about a board. */
    snprintf(detail, FT_DETAIL_LEN, "TODO M4: needs BT init");
    return 1;
}

/* --- LEDs (operator) --------------------------------------------------- */

static int probe_leds(void *user, int32_t *measured, char *detail)
{
    (void)user;
    *measured = 0;
    /* Walk the chain one group at a time — left reel, right reel, track,
     * REC, BT — and have the operator confirm. A single dead WS2812 kills
     * everything downstream of it, so the walk has to be visual. */
    snprintf(detail, FT_DETAIL_LEN, "TODO M4: needs RMT driver");
    return 1;
}

/* --- buttons (operator) ------------------------------------------------ */

static int probe_buttons(void *user, int32_t *measured, char *detail)
{
    (void)user;
    const int pins[4] = {PIN_BTN_REC, PIN_BTN_PLAY, PIN_BTN_TRACK,
                         PIN_BTN_MODE};
    const char *names[4] = {"REC", "PLAY", "TRACK", "MODE"};
    uint32_t seen = 0;
    const uint32_t deadline_ms = 20000u;
    uint32_t start;

    /* REC is GPIO0, which the programming jig also drives to enter download
     * mode. If the jig is still holding it low when this probe runs, REC
     * would "pass" the instant the loop starts and nobody would have
     * touched the button - a green result on an untested switch. Refuse to
     * start rather than report a pass nobody earned. */
    if (gpio_get_level(PIN_BTN_REC) == 0) {
        snprintf(detail, FT_DETAIL_LEN,
                 "IO0 already low - jig still driving it? release and retry");
        *measured = 0;
        return -1;
    }

    start = now_ms();
    printf("  press each button: REC, PLAY, TRACK, MODE\n");

    while (seen != 0x0Fu && (now_ms() - start) < deadline_ms) {
        for (int i = 0; i < 4; i++) {
            if (gpio_get_level(pins[i]) == 0) { /* active low */
                if (!(seen & (1u << i))) {
                    seen |= (1u << i);
                    printf("    %s ok\n", names[i]);
                }
            }
        }
        vTaskDelay(pdMS_TO_TICKS(20));
    }
    *measured = (int32_t)seen;

    if (seen != 0x0Fu) {
        char missing[FT_DETAIL_LEN];
        missing[0] = '\0';
        for (int i = 0; i < 4; i++) {
            if (!(seen & (1u << i))) {
                strncat(missing, names[i],
                        sizeof(missing) - strlen(missing) - 2u);
                strncat(missing, " ", sizeof(missing) - strlen(missing) - 1u);
            }
        }
        snprintf(detail, FT_DETAIL_LEN, "no press: %s", missing);
        return -1;
    }
    return 0;
}

/* --- suite ------------------------------------------------------------ */

static const ft_step_def_t k_steps[] = {
    {"flash_id", false, true,  probe_flash_id},
    {"flash_rw", false, false, probe_flash_rw},
    {"mic",      false, false, probe_mic},
    {"tab",      false, false, probe_tab},
    {"cc",       false, false, probe_cc},
    {"bt",       false, false, probe_bt},
    {"leds",     true,  false, probe_leds},
    {"buttons",  true,  false, probe_buttons},
};

#define STEP_COUNT (sizeof(k_steps) / sizeof(k_steps[0]))

static void configure_gpio(void)
{
    uint64_t buttons = (1ULL << PIN_BTN_REC) | (1ULL << PIN_BTN_PLAY) |
                       (1ULL << PIN_BTN_TRACK) | (1ULL << PIN_BTN_MODE);
    gpio_config_t bcfg = {
        .pin_bit_mask = buttons,
        .mode = GPIO_MODE_INPUT,
        .pull_up_en = GPIO_PULLUP_ENABLE,
        .pull_down_en = GPIO_PULLDOWN_DISABLE,
        .intr_type = GPIO_INTR_DISABLE,
    };
    ESP_ERROR_CHECK(gpio_config(&bcfg));

    gpio_config_t tab = {
        .pin_bit_mask = (1ULL << PIN_TAB_SENSE),
        .mode = GPIO_MODE_INPUT,
        .pull_up_en = GPIO_PULLUP_DISABLE, /* the tab has an external pull-down */
        .pull_down_en = GPIO_PULLDOWN_DISABLE,
        .intr_type = GPIO_INTR_DISABLE,
    };
    ESP_ERROR_CHECK(gpio_config(&tab));
}

static bool configure_flash_spi(probe_ctx_t *ctx)
{
    spi_bus_config_t bus = {
        .mosi_io_num = PIN_SPI_MOSI,
        .miso_io_num = PIN_SPI_MISO,
        .sclk_io_num = PIN_SPI_SCK,
        .quadwp_io_num = -1,
        .quadhd_io_num = -1,
        .max_transfer_sz = 4096,
    };
    if (spi_bus_initialize(VSPI_HOST, &bus, SPI_DMA_CH_AUTO) != ESP_OK) {
        return false;
    }
    spi_device_interface_config_t dev = {
        .clock_speed_hz = 10 * 1000 * 1000, /* gentle for bring-up */
        .mode = 0,
        .spics_io_num = PIN_FLASH_CS,
        .queue_size = 1,
    };
    if (spi_bus_add_device(VSPI_HOST, &dev, &ctx->flash) != ESP_OK) {
        return false;
    }
    ctx->flash_ready = true;
    return true;
}

void factory_test_main(void)
{
    printf("\n=== mixxtape factory test ===\n");

    configure_gpio();

    probe_ctx_t ctx;
    memset(&ctx, 0, sizeof(ctx));
    if (!configure_flash_spi(&ctx)) {
        ESP_LOGE(TAG, "SPI bus init failed; flash probes will fail");
    }

    ft_suite_t suite;
    if (ft_init(&suite, k_steps, (uint32_t)STEP_COUNT, true) != 0) {
        ESP_LOGE(TAG, "suite init failed");
        return;
    }

    ft_run(&suite, &ctx, now_ms);

    char report[FT_REPORT_LEN];
    ft_format_human(&suite, report, sizeof(report));
    printf("\n%s", report);

    ft_format_machine(&suite, report, sizeof(report));
    printf("\n%s\n", report);

    /* Any skip here means a probe is still a stub, so the board has not
     * really been tested. Refuse to show a clean banner until M4 has
     * filled them in — a green light nobody earned is worse than none. */
    if (suite.skipped > 0u) {
        printf("\n*** SUITE INCOMPLETE: %u probe(s) unimplemented ***\n",
               (unsigned)suite.skipped);
    } else if (ft_verdict(&suite)) {
        printf("\n*** BOARD PASSED ***\n");
    } else {
        printf("\n*** BOARD FAILED ***\n");
    }
}

#endif /* MIXXTAPE_FACTORY_TEST */

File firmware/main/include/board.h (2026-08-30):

/* Pin map for the rev 0.1 board.
 *
 * Authoritative source: docs/firmware-plan.md sec.2, which supersedes the
 * GPIO table in docs/cassette-recorder-agent-brief.md sec.5 (USB-C is now
 * power-only, programming is via the J5 pogo pads, and SENSOR_VP/VN sense
 * the USB-C CC lines).
 *
 * ESP32 constraints honoured here:
 *   GPIO 6-11  are the module's own flash — never used
 *   GPIO 12    is the MTDI strap and must be low at boot — left unused
 *   GPIO 34/35/36/39 are input-only
 */
#ifndef BOARD_H
#define BOARD_H

#include "tape_layout.h" /* TAPE_SAMPLE_RATE */

/* --- PDM microphone (MSM261DHT006, mono, L/R tied low) --------------
 * PDM rather than I2S: two wires instead of three, so the old bit-clock
 * pin (GPIO26) is now free. The ESP32's I2S peripheral does PDM receive
 * in hardware, decimating to PCM on the way in, so nothing downstream
 * changes.
 *
 * Clock rate matters here. PDM clock = sample rate x downsample ratio:
 *   44100 x 64  = 2.8224 MHz  -> inside the mic's 1.1-4.8 MHz window
 *   44100 x 128 = 5.6448 MHz  -> ABOVE its 4.8 MHz maximum
 * so the downsample ratio must be 64. Picking 128 would run the part out
 * of spec and is the obvious mistake to make here.
 *
 * The part is TOP-ported: sound enters from the component side, and there
 * is deliberately no hole through the board beneath it. Keep its top face
 * clear of case ribs, labels and fingers.
 */
#define PIN_PDM_CLK  25 /* ESP32 -> mic, 2.8224 MHz */
#define PIN_PDM_DATA 33 /* mic -> ESP32            */

#define PDM_DOWNSAMPLE_RATIO 64
#define PDM_CLOCK_HZ         (TAPE_SAMPLE_RATE * PDM_DOWNSAMPLE_RATIO)

/* --- VSPI: audio flash (W25Q128) + optional microSD (DNP) ----------- */
#define PIN_SPI_SCK   18
#define PIN_SPI_MISO  19
#define PIN_SPI_MOSI  23
#define PIN_FLASH_CS   5
#define PIN_SD_CS     22 /* microSD is DNP on the default build         */
#define PIN_SD_DETECT 32 /* switch to GND; needs an internal pull-up    */

/* --- WS2812 chain (via SN74AHCT1G125 level shifter) ----------------- */
#define PIN_LED_DATA 27
#define LED_COUNT    29
#define LED_REEL_LEFT_FIRST   0  /* D1-D12  */
#define LED_REEL_LEFT_COUNT   12
#define LED_REEL_RIGHT_FIRST  12 /* D13-D24 */
#define LED_REEL_RIGHT_COUNT  12
#define LED_TRACK_FIRST       24 /* D25-D27 */
#define LED_TRACK_COUNT       3
#define LED_REC               27 /* D28 */
#define LED_BT                28 /* D29 */

/* Global brightness ceiling. All 29 LEDs at full white is ~1.7 A; the
 * default USB-C budget is 500 mA until CC sensing says otherwise. */
/* Re-derived 2026-08-30 against the real part. At 5 mA/channel all 29 LEDs
 * at full white draw about 435 mA, not the 1.7 A the old caps assumed.
 *
 *   Default USB (500 mA guaranteed): an ESP32 Bluetooth TX burst takes
 *   ~250 mA through the linear regulator, leaving ~250 mA for the array.
 *   130/255 gives 435 * 130/255 = 222 mA, for ~472 mA total.
 *
 *   A 1.5 A source can supply the whole array at full, so the cap there is
 *   the part's own limit rather than the supply's.
 *
 * Firmware MUST read CC1_SENSE/CC2_SENSE before using the HIGH cap - the
 * board advertises itself as a plain sink (5.1k Rd), so a host is only
 * obliged to give 500 mA. */
#define LED_BRIGHTNESS_USB_DEFAULT 130 /* /255, ~51%, ~222 mA of array */
#define LED_BRIGHTNESS_USB_HIGH    255 /* /255, full, ~435 mA of array  */

/* --- Buttons: active low, internal pull-ups -------------------------- */
#define PIN_BTN_REC   0  /* also the BOOT strap — safe as active-low     */
#define PIN_BTN_PLAY  4
#define PIN_BTN_TRACK 16
#define PIN_BTN_MODE  17

/* --- Write-protect tab: external 10k pull-down, intact = high -------- */
#define PIN_TAB_SENSE 21

/* --- USB-C CC sense (ADC1) ------------------------------------------ */
#define PIN_CC1_SENSE 36 /* SENSOR_VP */
#define PIN_CC2_SENSE 39 /* SENSOR_VN */

/* CC voltage thresholds in millivolts, at the divider we fit (Rd = 5.1k,
 * sensed through 10k). Source advertises: ~0.41 V default (500 mA),
 * ~0.92 V (1.5 A), ~1.68 V (3 A). Thresholds sit mid-band. */
#define CC_MV_THRESHOLD_1A5 660
#define CC_MV_THRESHOLD_3A0 1230

/* --- UART to the programming jig (J5 pogo pads) ---------------------- */
#define PIN_UART_TX 1
#define PIN_UART_RX 3

/* --- Unpopulated (DNP) ---------------------------------------------- */
#define PIN_BATT_SENSE 34 /* divider not fitted  */
#define PIN_LINE_IN    35 /* jack not fitted     */

#endif /* BOARD_H */

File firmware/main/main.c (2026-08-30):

/* M0 skeleton: brings up the buttons and the tab sense and drives the
 * interaction state machine, logging every event over the jig UART.
 *
 * This is deliberately the *only* target-specific code so far. Everything
 * with real logic in it — the slot manager, the audio codec, the button
 * grammar — lives in components/ and is covered by host tests, because
 * there is no devkit to try things on (docs/firmware-plan.md sec.7).
 *
 * Still to come, and all gated on the first prototype boards (M4):
 *   - SPI flash HAL implementing flash_hal.h against the W25Q128
 *   - PDM capture (I2S peripheral in PDM RX mode) and ADPCM block
 *     encoding feeding tape_store
 *   - A2DP source, pairing by RSSI, bond storage
 *   - WS2812 output via the RMT peripheral
 *   - CC sensing to raise the LED brightness cap
 */

#include <string.h>

#include "board.h"
#include "esp_log.h"
#include "freertos/FreeRTOS.h"
#include "freertos/task.h"
#include "driver/gpio.h"
#include "ui_state.h"
#include "ws2812.h"

static const char *TAG = "mixxtape";

static const int k_button_pins[4] = {PIN_BTN_REC, PIN_BTN_PLAY, PIN_BTN_TRACK,
                                     PIN_BTN_MODE};
static const uint32_t k_button_bits[4] = {UI_BTN_REC, UI_BTN_PLAY,
                                          UI_BTN_TRACK, UI_BTN_MODE};

static void configure_inputs(void)
{
    uint64_t button_mask = 0;
    for (int i = 0; i < 4; i++) {
        button_mask |= (1ULL << k_button_pins[i]);
    }
    gpio_config_t buttons = {
        .pin_bit_mask = button_mask,
        .mode = GPIO_MODE_INPUT,
        .pull_up_en = GPIO_PULLUP_ENABLE, /* buttons short to GND */
        .pull_down_en = GPIO_PULLDOWN_DISABLE,
        .intr_type = GPIO_INTR_DISABLE,
    };
    ESP_ERROR_CHECK(gpio_config(&buttons));

    /* The tab has an external 10k pull-down; intact reads high. No internal
     * pull, so a snapped tab cannot be masked by one. */
    gpio_config_t tab = {
        .pin_bit_mask = (1ULL << PIN_TAB_SENSE),
        .mode = GPIO_MODE_INPUT,
        .pull_up_en = GPIO_PULLUP_DISABLE,
        .pull_down_en = GPIO_PULLDOWN_DISABLE,
        .intr_type = GPIO_INTR_DISABLE,
    };
    ESP_ERROR_CHECK(gpio_config(&tab));
}

static uint32_t sample_buttons(void)
{
    uint32_t mask = 0;
    for (int i = 0; i < 4; i++) {
        if (gpio_get_level(k_button_pins[i]) == 0) { /* active low */
            mask |= k_button_bits[i];
        }
    }
    return mask;
}

static bool tab_intact(void)
{
    return gpio_get_level(PIN_TAB_SENSE) != 0;
}

static void ui_task(void *arg)
{
    (void)arg;
    ui_ctx_t ui;
    ui_init(&ui);

    const TickType_t period = pdMS_TO_TICKS(5);
    TickType_t last_wake = xTaskGetTickCount();
    bool warned_tab = false;

    for (;;) {
        uint32_t now_ms = (uint32_t)(xTaskGetTickCount() * portTICK_PERIOD_MS);
        bool tab_ok = tab_intact();

        if (!tab_ok && !warned_tab) {
            ESP_LOGW(TAG, "write-protect tab is snapped: recording disabled");
            warned_tab = true;
        }

        ui_event_t events[8];
        uint32_t n = ui_tick(&ui, now_ms, sample_buttons(), tab_ok, events,
                             (uint32_t)(sizeof(events) / sizeof(events[0])));
        for (uint32_t i = 0; i < n; i++) {
            ESP_LOGI(TAG, "%s -> %s (track %d)", ui_event_name(events[i]),
                     ui_state_name(ui.state), ui.track + 1);
        }
        vTaskDelayUntil(&last_wake, period);
    }
}

#ifdef MIXXTAPE_FACTORY_TEST
void factory_test_main(void);
#endif

void app_main(void)
{
#ifdef MIXXTAPE_FACTORY_TEST
    /* Built for the jig: probe the board, print the record, stop. The
     * production image goes on afterwards. */
    factory_test_main();
    return;
#endif

    ESP_LOGI(TAG, "mixxtape firmware, M0 skeleton");
    ESP_LOGI(TAG, "tape: %d slots x %u KiB, ADPCM mono %u Hz",
             TAPE_SLOT_COUNT, (unsigned)(TAPE_SLOT_SIZE / 1024u),
             (unsigned)TAPE_SAMPLE_RATE);

    configure_inputs();

    /* Boot heartbeat: one green flash on the Bluetooth LED, then dark.
     *
     * This exists because without it a working board and a dead board are
     * VISUALLY IDENTICAL - 29 unlit LEDs and a UART line only the jig can
     * see. With 20 boards, no prototype and no test equipment, one flash
     * answers "is it alive?" from across the bench, and it exercises the
     * whole output path in doing so: GPIO27, the SN74AHCT1G125 level
     * shifter, the VBUS cut-link, and at least the first LED in the chain.
     *
     * Kept dim (24/255) so it costs a few mA and cannot brown out a board
     * on a marginal supply during the one moment we most need it to boot. */
    if (ws2812_init() == 0) {
        rgb_t boot[LED_COUNT];
        memset(boot, 0, sizeof(boot));
        boot[LED_BT].g = 24u;
        if (ws2812_show(boot, LED_COUNT) != 0) {
            ESP_LOGE(TAG, "ws2812_show failed - LED chain or level shifter?");
        }
        vTaskDelay(pdMS_TO_TICKS(250));
        ws2812_clear();
    } else {
        ESP_LOGE(TAG, "ws2812_init failed - RMT did not start");
    }

    xTaskCreate(ui_task, "ui", 4096, NULL, 5, NULL);
}

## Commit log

2026-08-25 Initial commit: docs, KiCad project, and first-pass schematic
    - Design docs: project write-up, agent handoff brief, BOM v3
    - README, CHANGELOG, AGENTS.md
    - KiCad 9 project in hardware/ with ERC-clean schematic: USB-C + ESD +
    CH340N, AMS1117-3.3 power, ESP32-WROOM-32E per the brief's GPIO map,
    I2S mic, W25Q128 flash, buttons, write-protect tab, castellated
    header, SN74AHCT1G125 level shifter, 29x WS2812B-2020 chain, and DNP
    battery section
    - Part libraries (symbols/footprints/3D) fetched from JLCPCB/EasyEDA via
    fetch_parts.py (curl_cffi Chrome TLS impersonation workaround)
    - LED positions fitted with XINGLIGHT XL-2020RGBC-2812B (C5349955);
    genuine Worldsemi WS2812B-2020 is EOL at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
    [mixxtape.kicad_sch]
2026-08-25 hardware: USB-C power-only, pogo jig, CC sense, DNP microSD
    - Remove CH340N + USBLC6 and the USB data path; USB-C is power only.
    Resolves the CH340N-has-no-DTR problem by deletion.
    - Remove the castellated hacker header; add J5, six bare pogo pads
    (3V3/GND/EN/IO0/TX/RX). The jig carries the bridge and auto-program
    transistors.
    - Add CC1/CC2 sensing through 10k to ADC1 (GPIO36/39) so firmware can
    read the source current advertisement and raise the LED brightness cap.
    - Add J4 microSD (TF-01A, C91145) + R9 pullup as footprint-only DNP,
    SPI mode sharing VSPI; CS=IO22, card-detect=IO32.
    - Add SN74AHCT1G125 (C7484) level shifter U8 for the WS2812 chain.
    - docs/prior-art.md: eleven casse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
    [mixxtape.kicad_sch]
2026-08-25 firmware: Phase A core — crash-safe slot manager, host tests, CI
    There is no devkit for this project, so everything with real logic in it
    is portable C behind flash_hal.h and proven on the host.
    components/tape:
    - Slot manager with an append-only ping-pong header log (64-byte records,
    CRC32 + generation counter), just-in-time erase ahead of the write
    pointer, and mount-time repair of a slot left mid-recording.
    - SBC frame arithmetic and IMA-ADPCM codec.
    components/ui: button grammar and device state machine (REC hold, PLAY
    short/long, TRACK cycle, MODE 2/5/10s), pure logic.
    test/host: NOR mock modelling erase/program bit semantics and torn
    writes, plus a power-yank sweep that tears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
    [board.h, main.c, mock_flash.c]
2026-08-25 firmware: store ADPCM, not SBC — A2DP source takes PCM only
    M3 reference study turned up a finding that invalidates the brief's
    playback design: ESP-IDF's A2DP source callback is handed a "buffer to be
    filled with PCM data stream", Bluedroid encodes SBC internally, and there
    is no API for pre-encoded frames. Storing SBC would mean decoding it back
    to PCM at playback purely so the stack could re-encode it — the exact
    real-time DSP the design forbids, plus a generation of extra loss.
    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
2026-08-25 firmware: tape-side player and reel display, both host-tested
    tape_player turns the three slots into one side: PLAY runs every recorded
    track in order, skipping empty slots rather than playing silence, and
    position is measured across the whole side because that is what the reels
    show. Pull-based, because the A2DP source callback runs on the Bluetooth
    task and must never block — a prefetch task drains this into a PCM ring
    and the callback only copies out of it.
    reels renders the display as a pure function of (mode, progress, level,
    clock): left ring empties while the right fills, red pulse riding the
    input level while recording, amber sweep hunting for a sink, dim reverse
    spin during backg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
    [reels.h, test_tape_player.c]
2026-08-25 firmware: factory test harness (M5)
    Twenty boards get assembled by hand and have to be checked identically by
    someone who did not design them. This is what the jig runs on each one
    before production firmware goes on.
    components/factory sequences the probes, aggregates results, and emits
    both an operator table and a one-line machine record:
    FT|1|flash_id=PASS:0xEF4018|mic=PASS:1832|tab=PASS:1|VERDICT=PASS
    Log the jig's serial output and that file is the build record for the run,
    so a board that turns out flaky later can be looked up rather than
    guessed about.
    Two properties earn their keep and are host-tested with mock probes:
    - Every step runs even after one fails, so a board with a d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
    [factory_main.c, main.c]
2026-08-25 firmware: pairing policy and persistent bond table
    Two halves of the pairing ritual, both host-testable even though the
    Bluedroid plumbing under them is not.
    components/bt/pairing is the selection policy that makes "hold the board
    against the speaker" the entire interaction. Class-of-Device filtering
    drops phones, laptops, peripherals and wearables, so the user never sees
    a list of their own hardware, and rejects the non-sink members of the
    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
2026-08-25 firmware: record-path look-ahead limiter
    Replaces the whole-take peak normalisation that one-pass recording gave
    up. One gain does both jobs:
    target = min(max_gain, ceiling / envelope)
    Loud rooms get pulled down and cannot clip; quiet rooms get lifted by up
    to +18 dB, which matters because a MEMS mic recording ambience is quiet
    and would otherwise be unlistenable. It is also the better tool than
    normalisation, which one door slam defeats.
    The envelope is a true sliding maximum over a window that includes the
    sample about to leave the delay line — not a decaying peak follower. That
    turns "output never exceeds the ceiling" into a hard guarantee for any
    input rather than a fast attack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
    [limiter.h]
2026-08-25 docs: user manual and FAQ
    The manual as it would ship with a board — getting started, controls,
    recording and playback, what the lights mean, the write-protect tab and
    why it is permanent, power, labelling, care, troubleshooting, specs, and
    a plain list of what the device deliberately does not do.
    The FAQ answers what people actually ask: does it play in a tape deck
    (no, and why), can I load music onto it (no, and that is the point), what
    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
2026-08-25 docs: correct the audio row in the README hardware table
    Said SBC-encoded at record time with read-frames-and-transmit playback,
    which the M3 finding retired: ESP-IDF's A2DP source takes PCM only, so
    the tape stores ADPCM and Bluedroid does the SBC encoding.
2026-08-25 hardware: generate BOM v4 from the schematic with live JLC pricing
    BOM v3 was hand-maintained and had drifted from the board in seven
    places: it still listed the CH340N, USBLC6 and S8050 pair that went away
    when USB-C became power-only, and the ME6211 LDO that the AMS1117
    replaced; and it was missing the WS2812 substitute actually fitted, the
    level shifter and the DNP microSD footprint. Since the BOM is what you
    order from, that is a quiet blocker rather than a documentation nit.
    gen_bom.py now derives it from mixxtape.kicad_sch and reads prices, stock
    and library type live from JLCPCB, emitting the markdown BOM and a
    JLCPCB-format assembly CSV. The two cannot disagree again. Requests are
    p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
    [cassette-recorder-bom-v4.csv]
2026-08-25 hardware: PCB mechanical layer — outline, reels, tab, holes
    Phase 2 of the brief's order. Mechanical only: no components placed and
    no routing, because the shape is what everything else hangs off and it
    has to be checked against a real cassette case before any copper.
    The outline is not redrawn from a standard. The brief says to take it
    from Open Music Labs' Mixtape Alpha rather than guess, so it is traced
    from that project's released gerbers — 104 segments, 100.33 x 63.50 mm,
    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
    [mixxtape.kicad_pcb]
2026-08-26 hardware: enforce the 5,000-stock supply-chain rule; case-fit test sheet
    Steven's rule: every fitted part needs 5,000+ in stock at JLCPCB, and a
    common part beats a capable one — a run of 20 hand-built boards is not
    worth a redesign because a clever chip went end-of-life. gen_bom.py now
    enforces it and prints a rule section; find_common_parts.py searches for
    compliant alternatives.
    Audit result: everything clears the bar except the microphone.
    That exception is worth stating plainly. No digital MEMS microphone at
    JLCPCB meets the rule — the category is thin and the best-stocked digital
    part is about 3.5k. The one microphone that does clear 5,000 (ZTS6216,
    C481302, 29k) is analog: it wa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
    [mixxtape.kicad_pcb]
2026-08-26 hardware: mic datasheet review — the brief's "bottom-ported" is wrong
    Read the datasheets before committing to a replacement microphone, and
    the more important finding was about the part we already had.
    The brief specifies MSM261S4030H0R as bottom-ported and calls for a
    0.5-0.8 mm acoustic hole through the board beneath it. Its datasheet says
    otherwise on page 2: "omnidirectional, Top-ported, I2S digital output".
    Every in-stock alternative in that family is top-ported too. Sound enters
    from the component side, so that hole would have done nothing but weaken
    the board and give a false sense the acoustics were handled. Removed from
    the mechanical layout, replaced with a keep-clear annotatio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
    [mixxtape.kicad_pcb]
2026-08-26 mic: move to MSM261DHT006 (PDM) across hardware and firmware
    Replaces MSM261S4030H0R, which is at zero stock. Acoustically an equal
    swap: identical -26 dBFS sensitivity, same 1.6-3.6 V range, same 4x3 mm
    LGA-8 outline, 1 dB less SNR and 2 dB better acoustic overload, at $0.45
    against $1.61.
    This was a schematic change rather than a part-number swap, because the
    pinout is completely different: pin 1 is VDD where the old part had GND,
    L/R moves to pin 2, and pins 5-8 are all GND. New footprint fetched from
    EasyEDA and verified against the datasheet pin table.
    Interface moves from I2S to PDM. That is two wires instead of three, so
    GPIO26 is now free; GPIO25 carries the PDM clock and GPIO33 th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
    [cassette-recorder-bom-v4.csv, mixxtape.kicad_sch]
2026-08-27 hardware: pre-routing review — outline, pin types, TAB1, battery removal
    Checked every footprint and every net before routing starts.
    The board outline was self-intersecting and would have failed CAM. The
    write-protect tab's two slots were drawn as closed rectangles lying on top
    of the top edge instead of cut into it, so the edge ran straight through
    both. Split the top edge into three spans and removed the slot mouths.
    Every symbol pin now has a real electrical type. easyeda2kicad types every
    pin "unspecified", which silently disables the checks that matter, so ERC
    was reporting 191 warnings of one meaningless class and nothing else. 109
    pins retyped from the datasheets, in the schemati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
    [cassette-recorder-bom-v4.csv, mixxtape-mechanical.kicad_pcb, mixxtape.kicad_pcb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]
2026-08-27 firmware: hardware-facing drivers (WIP, not compiled)
    The five drivers that can only be finished against a real board: W25Q128
    over VSPI, the PDM microphone on I2S, WS2812 on RMT, USB-C CC sensing on
    ADC1, and A2DP source over Bluedroid.
    Every file is marked NOT YET RUN ON HARDWARE, because none of it has been.
    There are no boards, and ESP-IDF is not installed here, so none of this has
    been compiled either. The policy these sit under — pairing, bonds, the tape
    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
2026-08-27 ci: rename the bt component off IDF's name; run on pull requests only
    The IDF build has been red since 3dcf692, the commit that created
    firmware/components/bt. ESP-IDF ships its own component called `bt`, and
    project components override IDF's by directory name, so ours shadowed the
    real Bluetooth component. esp_hid then lost the include paths it inherits
    through bt and the build failed on
    esp_hidh_private.h:13:10: fatal error: esp_timer.h: No such file or directory
    which is inside IDF's own source, so it read as an IDF problem rather than
    ours. Renamed to components/btaudio. Host tests were green the whole time,
    which is why four consecutive failures went unnoticed.
    The constraint is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
    [bonds.c]
2026-08-30 hardware+firmware: flash second-sourced, passives on 0402, ERC actually clean
    Flash: U3 moves from Winbond W25Q128JVSIQ (C97521) to GigaDevice
    GD25Q128ESIG (C2758105), $2.2557 -> $1.3348 at a run of 20, net $15.41
    after the Extended setup fee. Land patterns agree to 0.02 mm and the
    command set and 256 B / 4 KiB / 64 KiB geometry are identical, so neither
    the layout nor the storage design changes. The only difference is the
    JEDEC manufacturer byte, so rather than move the hard-coded constant both
    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
    [mixxtape-bom.csv, mixxtape.kicad_pcb, mixxtape.kicad_sch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]
2026-08-30 hardware: fix a latent fatal LED footprint fault; clear 19 hidden DRC rules
    The LED footprint was drawn for the GENUINE Worldsemi WS2812B-2020 (C965555)
    and still carried that part number, while the BOM shipped the XINGLIGHT clone
    C5349955, whose pad 1 is on the diagonally opposite corner. Every one of the
    29 LEDs would have had VDD on the GND net and GND on VBUS - reverse-powered
    across the 5 V rail, with no bodge possible on 0.225 mm of exposed copper.
    ERC, DRC, the netlist and the BOM/CPL cross-check all passed, because every
    one of them trusts the footprint.
    Switched to XL-1615RGBC-2812B (C5349954), which Steven has used before: half
    the price, double the stock, and its pin FUNCTIONS la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
    [cassette-recorder-bom-v4.csv, mixxtape.kicad_pcb, mixxtape.kicad_sch]
2026-08-30 hw+fw: widen the antenna keep-out, untent 44 probe vias, fix the SPI clock
    Antenna: the keep-out existed and was honoured, but was only 22 mm wide, so
    GND pour came within 1.85 mm of the module on the right and 2.10 mm on the
    left - in the antenna's own plane, where it detunes it and absorbs near-field
    energy. This is the arrangement Espressif's design guidelines name explicitly
    as the one to avoid. Widened to 35.5 mm; measured clearance is now 8.47 mm
    left and 8.97 mm right. Nothing but pour was in the way, so this cost one
    polygon edit and a re-pour with zero re-routing. The left edge stops at 62.5
    rather than 58 because the 3V3 and TAB_SENSE diagonals to the write-protect
    tab pass through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
    [mixxtape.kicad_pcb]
2026-08-30 hardware: cut-links, drilled mouse bites, U4 heatsink, real pin-1 markers
    Cut-links, so a board that arrives wrong can still be salvaged. Each is a
    narrowed neck in an existing trace with a solder-mask opening either side:
    cut the neck to isolate, bridge the exposed copper to restore or re-route.
    Built from copper geometry and mask apertures rather than footprints, so
    there is nothing for a future "update PCB from schematic" to delete and
    nothing enters the BOM or placement file.
    VBUS at (116.6-117.4, 70.0), 0.6 mm neck - isolates all 29 LEDs from the
    5 V rail. Every mA of array current passes through here, so it doubles
    as the place to put an ammeter. If the LED array is ever wron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
    [mixxtape-bom.csv, mixxtape.kicad_pcb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]
2026-08-30 docs: record the six-agent review and what it left open
    CHANGELOG gets the full account of today's fixes. The checklist gets a new
    section 0 listing what the reviews found that could NOT be fixed
    deterministically - the USB-C plug fit, the mounting-hole skew, the mic's
    port direction, the protective components that need schematic changes, the
    five stubbed factory-test probes, and the residuals that were quantified and
    knowingly accepted rather than risked unattended.
2026-08-30 docs: close the microphone port-direction blocker
    MSM261DHT006 (C51928215) is TOP-ported, confirmed from LCSC's own product
    page. The board is correct as drawn: no through-hole under U2. This had been
    flagged because gen_layout.py argues the case using the name of the part it
    replaced, and two reviewers could not close it from the repo alone.
2026-08-30 docs: close the USB-C CC pad-mapping question
    J1's signal row, read in physical order, is exactly the USB Type-C standard
    12-pin sequence reversed by the connector's 90 degree rotation. A5 is CC1 and
    B5 is CC2, both in their standard positions with their own 5.1k pull-downs.
    Cross-checked against LCSC's library data for C165948. The board would have
    taken no power from a C-to-C charger if this had been wrong, while still
    working on a legacy A-to-C cable - which is how it would have hidden.
2026-08-30 hardware: fix two defects the LED verification found in my own repair
    The independent verification confirmed the LED swap is correct - all 29 land
    VDD on VBUS and GND on GND across all 20 non-orthogonal rotations - but found
    two real defects in the repair itself.
    The pin-1 silk dot I drew sat ON pad 1, overlapping by ~0.155 mm. JLC clips
    silk off pads, so it was not a manufacturing risk - but clipping ERASES the
    marker, which defeats the entire point of adding one, and it raised 29
    silk_over_copper warnings that would bury real ones. Moved to local
    (-1.35, +0.95) on all 29 and in the library; tightest gap to pad 1 is now
    0.186 mm.
    LD28 landed only 0.082 mm into D29 pad 2 - 2.4% of the pad,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
    [mixxtape.kicad_pcb]
2026-08-30 firmware: the LED swap broke the driver against its new datasheet
    The re-review found that changing the LED part left a driver written for the
    old one. These are the most severe findings of the whole review pass, and both
    are consequences of my own hardware change.
    WS2812 timing was out of spec for the fitted part. The XL-1615RGBC-2812B
    demands MORE than Worldsemi's original: a 1 code needs >= 0.9 us high (the
    driver emitted 0.8), a 0 code needs >= 0.9 us low (it emitted 0.85), and the
    reset gap needs >= 200 us (it used 60). Every 1 bit in every frame was
    under-spec, and back-to-back frames would not latch - the second frame's bits
    append to the first and the whole chain shifts. Clones are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
    [board.h, factory_main.c, main.c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]
2026-08-30 hardware: fix what the regression audit found in my own repairs
    The MIC_VDD cut-link was on the wrong branch. I verified it by flood-filling
    the net with the neck removed: it splits into R12.2+U2.1 in one cluster and
    C7.1 alone in another. Cutting it would have left the microphone POWERED and
    stripped its decoupling - the opposite of what the commit claimed, and worse
    than not having the feature. The segment that actually feeds the mic is only
    0.82 mm long with a via at one end and R12's pad at the other, so there is no
    room to do it properly. Removed it: R12 is already a 0402 in series with the
    mic supply, and lifting one end isolates the mic completely. The feature was
    redundant as well as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
    [mixxtape.kicad_pcb]
2026-08-30 re running traces
    [mixxtape.kicad_pcb]
2026-08-30 hardware: repair three breaks left by the re-route
    The re-route in ee24c0e introduced three faults. DRC found them because the
    severities were promoted to error earlier; at the original settings two of the
    three would have been warnings.
    D12 pad 3 (VBUS) was left 0.693 mm short of its feed - the track stopped
    before reaching the pad. D12 would have had no power, and because the LEDs are
    a daisy chain that also kills every LED after it. Reconnected on the board's
    existing 45-degree house style.
    C2's ground was orphaned. The re-route split the F.Cu pour and left an
    8.48 mm2 island whose only member was C2 pad 2, with no via to the plane - so
    the AMS1117's output capacitor had no ground retur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
    [mixxtape.kicad_pcb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]
2026-08-30 hardware: keep the new silkscreen off the exposed probe points
    Two of Steven's new silk items landed on vias I had left untented. Neither was
    a manufacturing risk - export_fab.py passes --subtract-soldermask, so the silk
    is clipped and no ink reaches copper - but clipping ERASES the marking, and
    both would have printed with a bite taken out on a board where rework is
    expected.
    The FLASH section box sat at y = 46.90 with a 0.50 mm stroke, putting its
    outer edge at exactly 47.15: the centre of both PDM_DATA probe vias. Raised
    the bottom edge to 46.40, which clears them by 0.20 mm. Checked first that no
    footprint falls outside the box as a result.
    R1's designator overlapped a GND probe via. M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
    [mixxtape.kicad_pcb]
2026-09-06 hardware: restore the B-side artwork, and centre its bleed this time
    The peony was removed in ee24c0e. Restored from e15b369 verbatim - 2.16 MB,
    81,406 points across 193 B.SilkS shapes - with one change: it moves +0.382 mm
    in x.
    It had been drawn to the ORIGINAL 100.33 mm outline, and the board was later
    trimmed to 99.50 mm from the LEFT. So at its old position the artwork hung
    0.806 mm off the left edge and only 0.042 mm off the right: the fab's clip
    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
    [mixxtape.kicad_pcb]
2026-09-06 docs: close three pre-production questions on Steven's answers
    The peony is the final B-side artwork, so docs/b-side-silkscreen-brief.html is
    retired - there is no outstanding artwork commission. The 1:1 template stays
    for anyone reworking it later, and the docs index now points at that instead
    of the brief.
    The four mounting holes are correct as drawn, measured against the real shell.
    They are deliberately NOT a rectangle - 0.350 mm of skew across the rows,
    0.250 mm between the columns - because the moulded bosses are not square
    either. A review flagged this as a defect on the reasonable assumption that
    they would be, and it was the right thing to flag. The checklist now records
    the measur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
2026-09-07 fab: rebuild the JLCPCB package and commit reference renders
    Rebuilt with hardware/scripts/export_fab.py, which gates on a clean DRC and
    cross-checks the BOM against the placement file before writing the zip.
    gerbers zip 12 files, 0.96 MB - 9 layers, 2 drills, the .gbrjob
    BOM 14 lines
    CPL 66 placements
    NPTH drill 10 holes - the 6 mouse bites plus J1's and J4's locating pegs
    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
